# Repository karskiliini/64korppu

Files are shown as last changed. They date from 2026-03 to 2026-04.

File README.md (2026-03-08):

# 64korppu

Standardi PC:n 1.44MB 3.5" HD-korppuasema Commodore 64 -tietokoneeseen. FAT12-levyformaatti mahdollistaa tiedostojen siirron C64:n ja PC:n välillä.

## Vaihtoehdot

| # | Ratkaisu | Liitäntä | Hinta | RAM | Tasonmuuntimet | Suositus |
|---|---|---|---|---|---|---|
| **[A](docs/A-IEC-Pico/)** | **IEC + Raspberry Pi Pico** | IEC-sarjaväylä | ~12€ | 264 KB | 4x BSS138 | **Suositeltu** |
| [B](docs/B-Expansion-FDC/) | Expansion port + FDC-piiri | Expansion port | ~20-30€ | - | Ei | Nopein |
| [C](docs/C-Userport-Pico/) | User port + Raspberry Pi Pico | User port | ~12€ | 264 KB | 1x 74LVC245 + 2x BSS138 | Kompromissi |
| [D](docs/D-IEC-Nano/) | IEC + Arduino Nano | IEC-sarjaväylä | ~8€ | 2 KB | **Ei yhtään** | Halvin |
| [E](docs/E-IEC-Nano-SRAM/) | IEC + Arduino Nano + SPI SRAM | IEC-sarjaväylä | ~10-13€ | 2+128 KB | **Ei yhtään** | Nano tehostettuna |

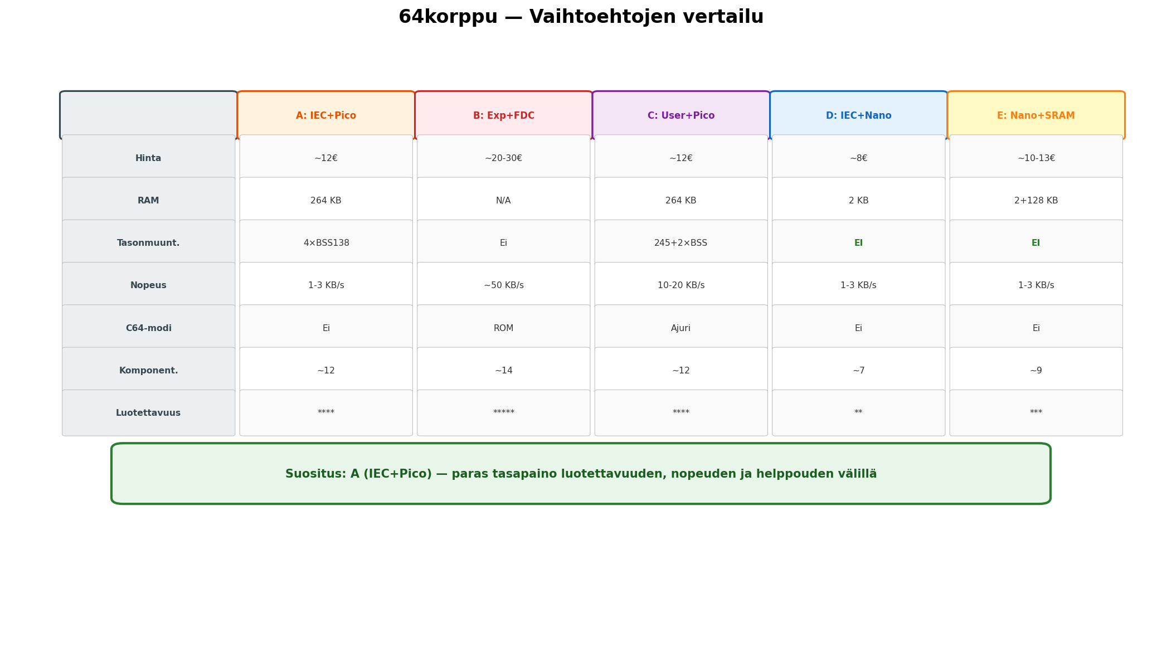
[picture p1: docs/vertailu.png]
Vaihtoehtojen vertailu


## Arkkitehtuuri

```
C64 ──[IEC / User port / Expansion port]──> Ohjain ──[34-pin]──> PC 3.5" HD floppy
                                                         │
                                                    FAT12-levy
                                                    (1.44 MB)
                                                         │
                                                    PC lukee/kirjoittaa
                                                    samaa levyä
```

## Miksi?

- **Tiedostonsiirto** C64:n ja modernin PC:n välillä ilman erikoislaitteita
- **FAT12** on universaali — levy toimii molemmissa koneissa
- **.PRG-tiedostot** tallennetaan suoraan levylle (2 tavun load address + data)
- **.D64 disk imaget** tuettuja — kopioi .D64-tiedosto levylle, mounttaa C64:llä, lataa ohjelmia suoraan
- C64:llä: `LOAD "PELI.PRG",8` / `SAVE "OMA.PRG",8` / `LOAD "$",8`

## Projektin rakenne

```
64korppu/
├── docs/
│   ├── A-IEC-Pico/           Vaihtoehto A: IEC + Pico (suositeltu)
│   │   ├── README.md         Yhteenveto
│   │   ├── kuvaus.md         Arkkitehtuuri ja komponentit
│   │   ├── piirikaavio.md    Yksityiskohtainen piirikaavio
│   │   └── d64-tuki.md       D64 disk image -tuki
│   ├── B-Expansion-FDC/      Vaihtoehto B: Expansion port + FDC
│   │   ├── README.md
│   │   ├── kuvaus.md
│   │   └── piirikaavio.md
│   ├── C-Userport-Pico/      Vaihtoehto C: User port + Pico
│   │   ├── README.md
│   │   ├── kuvaus.md
│   │   └── piirikaavio.md
│   ├── D-IEC-Nano/           Vaihtoehto D: IEC + Arduino Nano
│   │   ├── README.md
│   │   ├── kuvaus.md
│   │   └── piirikaavio.md
│   └── E-IEC-Nano-SRAM/      Vaihtoehto E: IEC + Nano + 128KB SRAM
│       ├── README.md
│       ├── kuvaus.md
│       └── piirikaavio.md
├── firmware/                  Pico-firmware (vaihtoehto A)
│   ├── CMakeLists.txt
│   ├── include/               Header-tiedostot
│   │   ├── cbm_dos.h          CBM-DOS-emulaatio
│   │   ├── d64.h              D64 disk image -tuki
│   │   ├── fat12.h            FAT12-tiedostojärjestelmä
│   │   ├── floppy_ctrl.h      Floppy-aseman ohjaus
│   │   ├── iec_protocol.h     IEC-väyläprotokolla
│   │   └── mfm_codec.h        MFM-koodaus/dekoodaus
│   ├── src/                   Lähdekoodit
│   │   ├── main.c             Pääohjelma, dual-core, inter-core viestit
│   │   ├── cbm_dos.c          LOAD/SAVE/$, CD:/S:/R:/N:/I:, D64-moodi
│   │   ├── d64.c              D64-parsinta, mount/unmount, BAM, T/S-ketjut
│   │   ├── fat12.c            FAT12 mount/read/write/delete/format
│   │   ├── floppy_ctrl.c      GPIO-ohjaus: moottori, seek, side select
│   │   ├── iec_protocol.c     ATN/CLK/DATA bit-bang, byte send/receive
│   │   └── mfm_codec.c        MFM-dekoodaus, CRC-CCITT, sektorihaku
│   └── pio/                   PIO-ohjelmat (RP2040)
│       ├── iec_bus.pio        IEC-vastaanotto
│       ├── mfm_read.pio       MFM flux-transitioiden mittaus
│       └── mfm_write.pio      MFM flux-transitioiden generointi
└── test/                      Testit (ajetaan host-koneella, ei tarvitse Picoa)
    ├── Makefile               Kääntää testit ja IEC bridge
    ├── test_d64.c             D64-moduulin yksikkötestit (27 testiä)
    ├── mock_fat12.c/h         FAT12-mock: tiedostot muistissa
    ├── gen_test_d64.py        Generoi testi-.D64-imagen
    └── vice/                  IEC bridge integraatiotestaukseen
        ├── iec_bridge.c       TCP-palvelin: oikea CBM-DOS + D64 host-koneella
        ├── mock_iec.c/h       IEC-protokollan stubit
        ├── vice_test.py       Python-testiskripti (simuloi C64 IEC-komentoja)
        └── README.md          Bridge-arkkitehtuuri ja ohje
```

## Testaus

D64- ja CBM-DOS-koodi on testattavissa host-koneella (Linux/macOS) ilman Pico-laitteistoa:

```bash
cd test
make test          # 27 yksikkötestiä D64-moduulille
make               # kääntää myös IEC bridge
./vice/iec_bridge  # käynnistä TCP-palvelin
python3 vice/vice_test.py  # aja integraatiotestit toisessa terminaalissa
```

## Tila

Projekti on suunnitteluvaiheessa. Firmware-koodi on kirjoitettu vaihtoehto A:lle (Pico), mutta ei vielä testattu oikealla laitteistolla. D64 disk image -tuki toteutettu ja testattu host-tasolla.

## Lisenssi

Avoin lähdekoodi. Lisenssi lisätään myöhemmin.

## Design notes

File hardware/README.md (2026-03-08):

# Hardware — KiCad-piirilevyt

## Hakemistorakenne

```
hardware/
└── E-IEC-Nano-SRAM/
    ├── 64korppu-E.kicad_pro        # KiCad-projekti
    ├── 64korppu-E.kicad_sch        # Piirikaavio
    ├── 64korppu-E.kicad_pcb        # Piirilevylayout
    ├── fp-lib-table                # Footprint-kirjaston asetukset
    └── 64korppu-E.pretty/          # Projektikohtaiset footprintit
        └── DIN-6_IEC_Vertical.kicad_mod
```

## Vaatimukset

- **KiCad 8** (https://www.kicad.org/)

## Projektin avaaminen

1. Avaa KiCad
2. **File → Open Project**
3. Valitse `hardware/E-IEC-Nano-SRAM/64korppu-E.kicad_pro`

Piirikaavio avautuu Schematic Editorilla, piirilevylayout PCB Editorilla.

## Automaattireititys Freeroutingilla

Freerouting reitittää piirilevyn vedot automaattisesti KiCadin tuottamasta netlististä.

1. **KiCad PCB Editor:** File → Export → Specctra DSN — tallenna `.dsn`-tiedosto
2. Lataa Freerouting: https://github.com/freerouting/freerouting
3. Käynnistä:
   ```bash
   java -jar freerouting.jar
   ```
4. Avaa `.dsn`-tiedosto ja klikkaa **Autoroute**
5. Kun reititys valmis: **File → Export Specctra Session** (`.ses`)
6. **KiCad PCB Editor:** File → Import → Specctra Session — valitse `.ses`-tiedosto

Tarkista tulos DRC:llä (Inspect → Design Rules Checker) ennen Gerber-vientiä.

## Gerber-vienti (JLCPCB / PCBWay)

### Gerber-tiedostot

1. **KiCad PCB Editor:** File → Fabrication Outputs → Gerbers
2. Varmista että seuraavat tasot ovat valittuna:
   - `F.Cu` — etupuolen kupari
   - `B.Cu` — takapuolen kupari
   - `F.SilkS` — etupuolen silkkipaino
   - `B.SilkS` — takapuolen silkkipaino
   - `F.Mask` — etupuolen juotosmaskimaski
   - `B.Mask` — takapuolen juotosmaskimaski
   - `Edge.Cuts` — levyn ääriviivat
3. Klikkaa **Plot**

### Poraustiedostot

1. File → Fabrication Outputs → Drill Files
2. Käytä oletusasetuksia (Excellon-formaatti)
3. Klikkaa **Generate Drill File**

### Tilaus

1. Pakkaa kaikki Gerber- ja poraustiedostot yhteen `.zip`-tiedostoon
2. Lataa osoitteeseen [JLCPCB](https://jlcpcb.com/) tai [PCBWay](https://pcbway.com/)
3. Tarkista esikatselu ennen tilausta

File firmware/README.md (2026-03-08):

# Firmware

Kullekin laitteistovaihtoehdolle on oma hakemistonsa.
Vaihtoehdot vastaavat `docs/`-kansion suunnitelmia.

```
firmware/
├── A-IEC-Pico/          Raspberry Pi Pico, IEC-väylä (suositeltu)
│   ├── src/             C-lähdekoodi
│   ├── include/         Otsikkotiedostot
│   ├── pio/             PIO-ohjelmat (iec_bus, mfm_read, mfm_write)
│   ├── CMakeLists.txt   Pico SDK build
│   └── pico_sdk_import.cmake
│
├── B-Expansion-FDC/     Expansion port + FDC-piiri (ei vielä toteutettu)
├── C-Userport-Pico/     User port + Pico (ei vielä toteutettu)
├── D-IEC-Nano/          Arduino Nano, IEC-väylä (ei vielä toteutettu)
└── E-IEC-Nano-SRAM/     Arduino Nano + SPI SRAM (ei vielä toteutettu)
```

## A-IEC-Pico

Ainoa toistaiseksi toteutettu vaihtoehto. Raspberry Pi Pico emuloi
CBM-levyasemaa IEC-sarjaväylän yli ja ohjaa PC 3.5" HD -korppuasemaa.

Tuetut levyformaatit:
- **HD 1.44 MB** — FAT12-tiedostojärjestelmä
- **DD 720 KB** — CBM 1581 -yhteensopiva CBMFS-tiedostojärjestelmä
- **D64-levykuvat** — 1541-yhteensopiva (luetaan FAT12-levyltä)

Kääntäminen:

```bash
cd firmware/A-IEC-Pico
mkdir build && cd build
cmake ..
make
```

## B–E: Muut vaihtoehdot

Suunnitteludokumentit löytyvät `docs/`-kansiosta. Firmwarea ei ole
vielä toteutettu näille vaihtoehdoille. Jokainen vaihtoehto tulee
noudattamaan samaa logiikkakerrosrakennetta (CBM-DOS, D64, FAT12/CBMFS),
mutta laitteistotason koodi (IEC-protokolla, floppy-ohjaus, MFM) on
alustaspesifistä.

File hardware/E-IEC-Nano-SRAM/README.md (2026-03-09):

# 64korppu-E — Hardware

> Arduino Nano + 23LC256 SPI SRAM + 74HC595

## 4-layer (70x60mm)

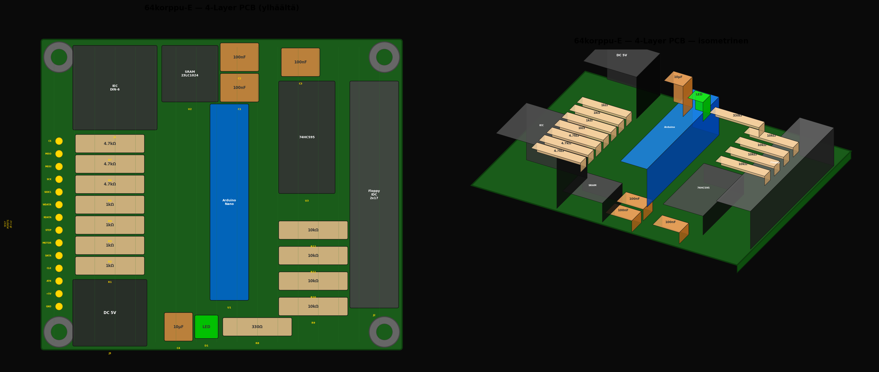
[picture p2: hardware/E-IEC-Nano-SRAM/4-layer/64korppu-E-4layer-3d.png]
64korppu-E 4-layer PCB


## 2-layer (140x120mm)

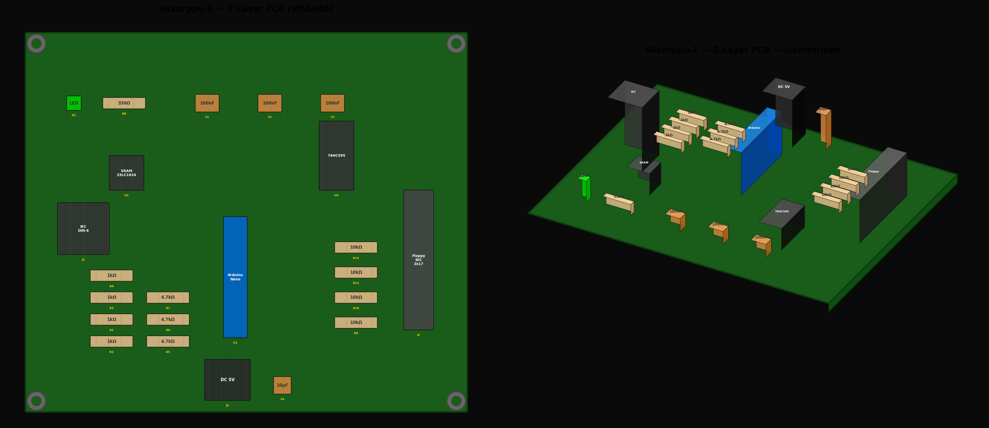
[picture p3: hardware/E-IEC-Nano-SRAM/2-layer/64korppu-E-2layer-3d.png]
64korppu-E 2-layer PCB


## Variantit

| Kansio | Kerrokset | Mitat (mm) | Pinta-ala |
|---|---|---|---|
| [2-layer/](2-layer/) | F.Cu + B.Cu | 140.0 × 120.0 | 16 800 mm² |
| [4-layer/](4-layer/) | F.Cu / GND / +5V / B.Cu | 70.0 × 60.0 | 4 200 mm² |

## Dokumentaatio

Katso [docs/E-IEC-Nano-SRAM/](../../docs/E-IEC-Nano-SRAM/) — piirikaavio, diagnostiikkapadit, komponenttikuvaus.

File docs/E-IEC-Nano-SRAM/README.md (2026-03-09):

# E: IEC-väylä + Arduino Nano + SPI SRAM (Nano tehostettuna)

> C64:n IEC-sarjaväylä → Arduino Nano + 23LC256 SRAM → PC 3.5" HD floppy

## Yhteenveto

Vaihtoehto D:n parannettu versio. Microchipin 23LC256 SPI SRAM (32 KB) ratkaisee Nanon 2 KB muistirajoituksen. 74HC595 shift register ohjaa floppy-signaaleja SPI-väylän kautta, vapauttaen GPIO-pinnejä. Edelleen täysin 5V-natiivi — ei tasonmuuntimia.

## Tiedostot

| Tiedosto | Sisältö |
|---|---|
| [kuvaus.md](kuvaus.md) | SRAM-vaihtoehdot, muistikartta, SPI-väylän jakaminen, 74HC595-ohjaus, firmware-rakenne |
| [piirikaavio.md](piirikaavio.md) | 23LC256 + 74HC595 SPI-kytkentä, kokonaispiirikaavio, bypass-kondensaattorit |
| [diagnostiikkapadit.md](diagnostiikkapadit.md) | 14 testipistettä: signaalit, odotetut tasot, mittausohje, vianetsintä |

## PCB

| Variantti | Mitat | Kerrokset |
|---|---|---|
| 2-layer | 140.0 × 120.0 mm | F.Cu + B.Cu |
| 4-layer | 70.0 × 60.0 mm | F.Cu / GND / +5V / B.Cu |

64korppu-E 4-layer PCB

## Piirikaavio

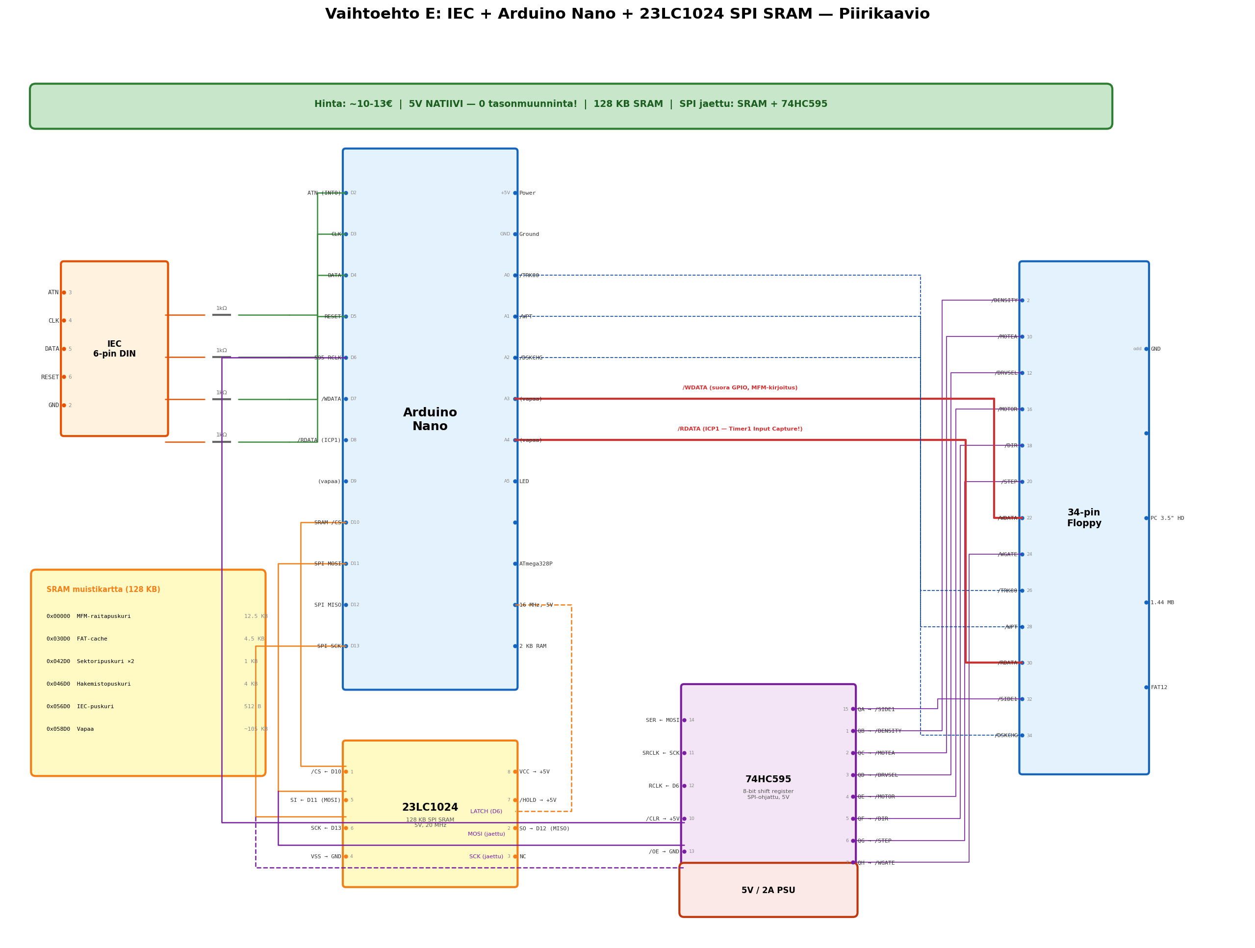
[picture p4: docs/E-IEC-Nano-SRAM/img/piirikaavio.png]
Vaihtoehto E: Nano + SRAM


## Avainominaisuudet

- **32 KB SRAM** — koko raita, FAT-taulu ja puskurit mahtuvat
- **Ei tasonmuuntimia** — 5V natiivi (Nano + 23LC256 + 74HC595 + floppy)
- **SPI-väylän jakaminen** — SRAM ja shift register samalla väylällä
- **Edullinen** (~10-13€)

## Hinta: ~10-13€

## Haaste

SPI SRAM lisää hieman latenssia. Single-core (ei rinnakkaista IEC + floppy). 32 KB Flash voi olla tiukka.

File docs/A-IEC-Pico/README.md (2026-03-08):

# A: IEC-väylä + Raspberry Pi Pico (Suositeltu)

> C64:n IEC-sarjaväylä → Raspberry Pi Pico → PC 3.5" HD floppy

## Yhteenveto

Pico emuloi CBM-levyasemaa (device #8) IEC-väylällä ja ohjaa PC-korppuasemaa 34-pin Shugart-liitännällä. FAT12-tiedostojärjestelmä mahdollistaa levyjen lukemisen sekä C64:llä että PC:llä.

## Tiedostot

| Tiedosto | Sisältö |
|---|---|
| [kuvaus.md](kuvaus.md) | Arkkitehtuuri, komponenttilista, GPIO-kartta, firmware-rakenne, plussat/miinukset |
| [piirikaavio.md](piirikaavio.md) | Yksityiskohtainen piirikaavio: BSS138 level shifter, floppy-kytkentä, Pico pinout |
| [d64-tuki.md](d64-tuki.md) | D64 disk image -tuki: formaatti, käyttöohjeet, rajoitukset |

## Piirikaavio

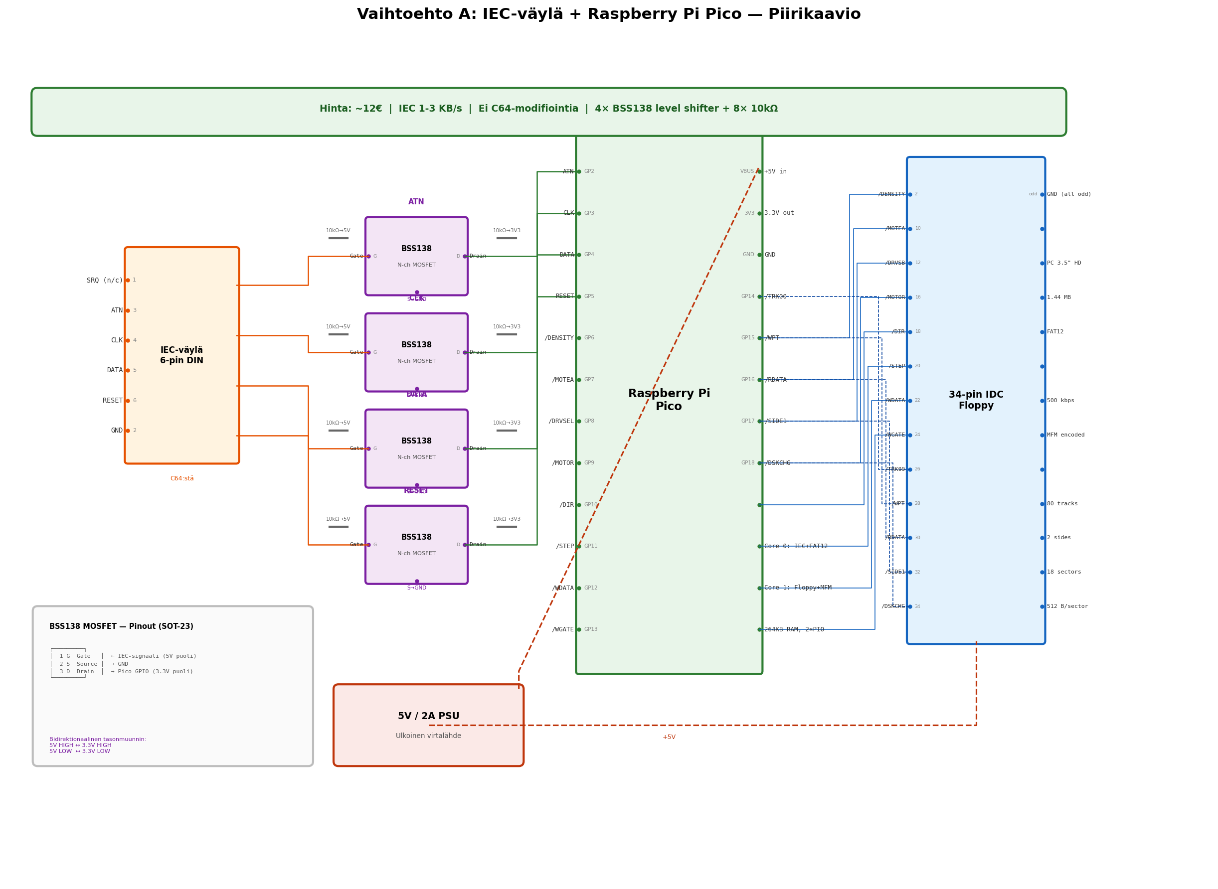
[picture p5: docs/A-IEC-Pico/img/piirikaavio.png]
Vaihtoehto A: IEC + Pico


## Avainominaisuudet

- **Ei vaadi C64:n modifiointia** — toimii suoraan LOAD/SAVE-komennoilla
- **Dual-core**: IEC-protokolla ja floppy-ohjaus rinnakkain
- **PIO**: tarkka ajoitus MFM-koodaukselle ja IEC-signaloinnille
- **264 KB RAM**: koko raita ja FAT-taulu mahtuvat muistiin
- **D64 disk image -tuki**: kopioi .D64-tiedosto levylle, mounttaa C64:llä `CD:`-komennolla

## Hinta: ~12€

## Haaste

Tarvitsee 4x BSS138 MOSFET level shifter (3.3V ↔ 5V) IEC-väylälle.

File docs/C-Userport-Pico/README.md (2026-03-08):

# C: User Port + Raspberry Pi Pico (Hyvä kompromissi)

> C64 user port → Raspberry Pi Pico → PC 3.5" HD floppy

## Yhteenveto

Pico kommunikoi C64:n kanssa user portin 8-bittisen rinnakkaisväylän kautta. Nopeampi kuin IEC (~10-20 KB/s), mutta vaatii ladattavan ajurin C64-puolelle. Expansion port jää vapaaksi.

## Tiedostot

| Tiedosto | Sisältö |
|---|---|
| [kuvaus.md](kuvaus.md) | Arkkitehtuuri, user port protokolla, CIA2-kytkennät, C64-ajurikoodi |
| [piirikaavio.md](piirikaavio.md) | 74LVC245 dataväylä, BSS138 handshake, floppy-kytkentä, DIR-ohjaus |

## Piirikaavio

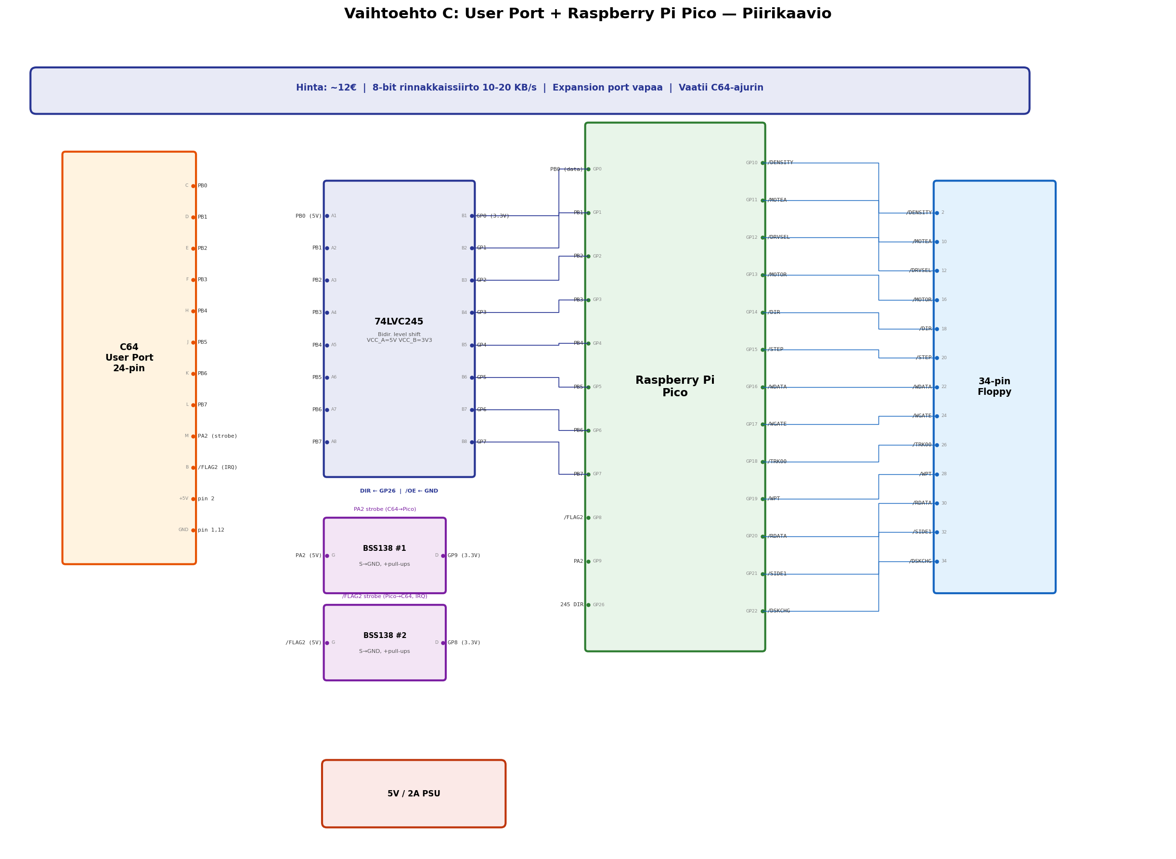
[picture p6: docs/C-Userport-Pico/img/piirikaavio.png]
Vaihtoehto C: User port + Pico


## Avainominaisuudet

- **Nopeampi kuin IEC** — 8-bittinen rinnakkaissiirto (~10-20 KB/s)
- **Expansion port vapaa** — cartridget ja REU toimivat
- **Dual-core**: sama Pico-etu kuin vaihtoehdossa A

## Hinta: ~12€

## Haaste

Vaatii C64-ajurin lataamisen ennen käyttöä. Ei suoraan yhteensopiva kaiken ohjelmiston kanssa. User port varattu.

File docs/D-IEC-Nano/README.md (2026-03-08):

# D: IEC-väylä + Arduino Nano (Edullinen klassikko)

> C64:n IEC-sarjaväylä → Arduino Nano → PC 3.5" HD floppy

## Yhteenveto

Arduino Nano emuloi CBM-levyasemaa IEC-väylällä. Nanon 5V-logiikka on suoraan yhteensopiva sekä IEC-väylän että floppy-aseman kanssa — tasonmuuntimia ei tarvita lainkaan!

## Tiedostot

| Tiedosto | Sisältö |
|---|---|
| [kuvaus.md](kuvaus.md) | Arkkitehtuuri, GPIO-kartta, Timer1 ICP MFM-strategia, RAM-rajoitukset |
| [piirikaavio.md](piirikaavio.md) | Suora 5V-kytkentä, ICP1 MFM-luku, komponenttilista |

## Piirikaavio

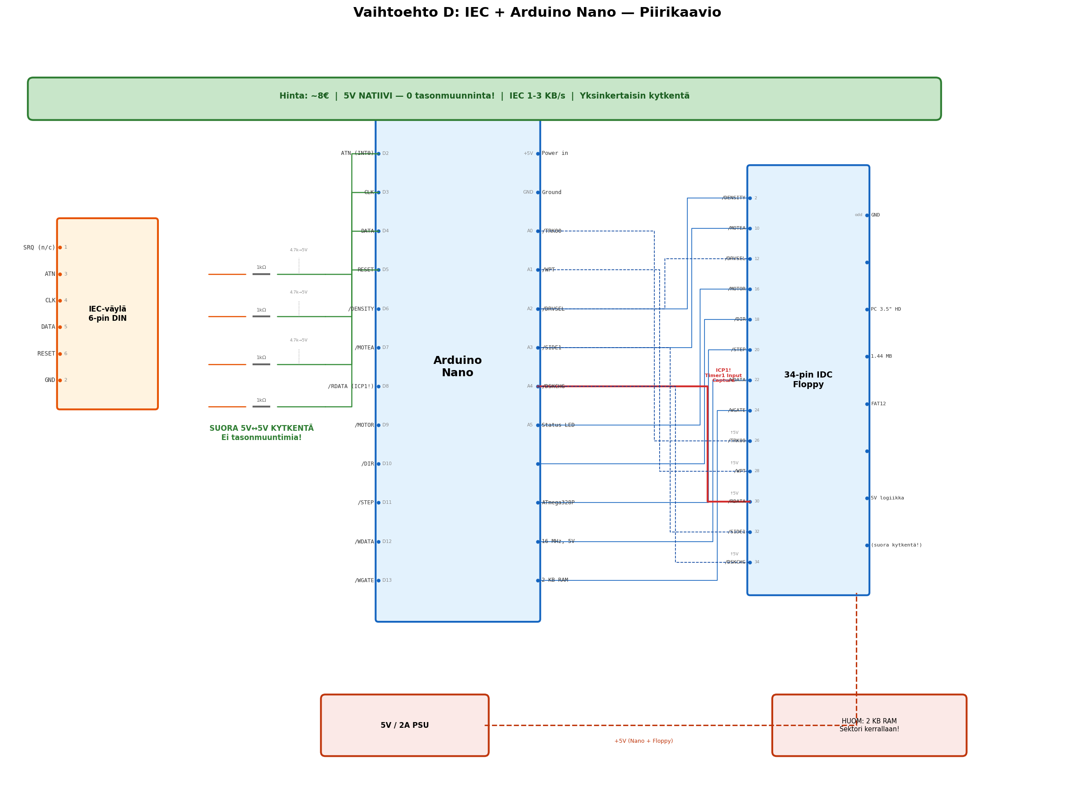
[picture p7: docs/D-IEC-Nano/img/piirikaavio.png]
Vaihtoehto D: IEC + Nano


## Avainominaisuudet

- **Ei tasonmuuntimia!** — 5V natiivi, yksinkertaisin kytkentä
- **Edullisin vaihtoehto** (~8€)
- **Tuttu Arduino-ympäristö**

## Hinta: ~8-10€

## Haaste

Vain 2 KB RAM — MFM-raita (12.5 KB) ja FAT-taulu (4.5 KB) eivät mahdu muistiin. Vaatii sektori-kerrallaan reaaliaikaista dekoodausta. Katso vaihtoehto E ratkaisulle.

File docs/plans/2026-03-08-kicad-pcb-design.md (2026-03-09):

# KiCad PCB Design — Vaihtoehto E (IEC + Nano + SPI SRAM)

## Päätökset

- **Levy:** ~85 × 55 mm, 2-kerroksinen (top + bottom)
- **Nano:** Pin header -sokkelit, irrotettava moduuli
- **Liittimet:** IEC DIN-6 vasemmalla, 34-pin IDC oikealla, DC jack ylhäällä
- **Automaattireititys:** Freerouting (.dsn export)

## Komponentit

| Ref | Komponentti | Paketti | Kpl |
|-----|---|---|-----|
| U1 | Arduino Nano | 2×15 pin header | 1 |
| U2 | 23LC256 | DIP-8 | 1 |
| U3 | 74HC595 | DIP-16 | 1 |
| J1 | 6-pin DIN | DIN-6 (IEC) | 1 |
| J2 | 34-pin IDC | 2×17 shrouded header | 1 |
| J3 | DC jack | 5.5/2.1mm barrel | 1 |
| R1-R4 | 1 kOhm | axial | 4 |
| R5-R7 | 4.7 kOhm | axial | 3 |
| R8 | 330 Ohm | axial | 1 |
| R9-R12 | 10 kOhm | axial | 4 |
| C1-C3 | 100 nF | ceramic disc | 3 |
| C4 | 10 uF | electrolytic | 1 |
| D1 | LED green | 3mm | 1 |

## Netlist

```
IEC-väylä:
  J1.ATN  → R1 → U1.D2
  J1.CLK  → R2 → U1.D3
  J1.DATA → R3 → U1.D4
  J1.RST  → R4 → U1.D5
  J1.GND  → GND

IEC pull-up:
  R5: +5V → J1.ATN (after R1)
  R6: +5V → J1.CLK (after R2)
  R7: +5V → J1.DATA (after R3)

SPI SRAM (23LC256):
  U1.D10  → U2./CS
  U1.D11  → U2.SI
  U1.D12  ← U2.SO
  U1.D13  → U2.SCK
  U2./HOLD → +5V
  U2.VCC  → +5V
  U2.VSS  → GND

74HC595:
  U1.D11  → U3.SER
  U1.D13  → U3.SRCLK
  U1.D6   → U3.RCLK
  U3./CLR → +5V
  U3./OE  → GND
  U3.VCC  → +5V
  U3.GND  → GND

Floppy (via 74HC595):
  U3.QA → J2./SIDE1
  U3.QB → J2./DENSITY
  U3.QC → J2./MOTEA
  U3.QD → J2./DRVSEL
  U3.QE → J2./MOTOR
  U3.QF → J2./DIR
  U3.QG → J2./STEP
  U3.QH → J2./WGATE

Floppy (suora GPIO):
  U1.D7  → J2./WDATA
  U1.D8  ← J2./RDATA
  U1.A0  ← J2./TRK00   (R9 pull-up 10k)
  U1.A1  ← J2./WPT     (R10 pull-up 10k)
  U1.A2  ← J2./DSKCHG  (R11 pull-up 10k)
  U1.D8 pull-up: R12 10k → +5V

LED:
  U1.A5 → R8(330) → D1 → GND

Bypass:
  C1: U1.+5V ↔ GND
  C2: U2.VCC ↔ GND
  C3: U3.VCC ↔ GND
  C4: J3.+5V ↔ GND (bulk)

Virta:
  J3.+5V → +5V (kaikille)
  J3.GND → GND (kaikille)
```

## Sijoittelu

```
              J3 (DC jack)
        ┌────────┬─────────────────┐
        │  C4                      │
        │                          │
  J1 ───┤  R1-R4    ┌──────────┐   ├─── J2
 (DIN-6)│  R5-R7    │ U1 Nano  │   │  (34-pin IDC)
        │           │ headers  │   │
        │  ┌────┐   └──────────┘   │
        │  │ U2 │                  │
        │  │SRAM│   ┌──────────┐   │
        │  └────┘   │U3 74HC595│   │
        │           └──────────┘   │
        │  D1 R8   C1 C2 C3       │
        │          R9-R12          │
        └──────────────────────────┘
```

## Reititysprioriteetti

1. SPI-väylä (MOSI/MISO/SCK) — lyhyet vedot
2. MFM (WDATA/RDATA) — suorat lyhyet vedot
3. IEC — DIN-6 → vastukset → Nano
4. GND-täyttö bottom-kerroksella

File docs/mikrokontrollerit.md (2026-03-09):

# Mikrokontrollerit ja kehitysalustat — vertailu

Tämä dokumentti listaa kaikki Arduino-laudat ja vastaavat kehitysalustat,
jotka voisivat soveltua 64korppu-projektiin.

## Projektin vaatimukset

```
IEC-väylä:       4 GPIO  (ATN interrupt, CLK, DATA, RESET)
Floppy output:   9 GPIO  (DENSITY, MOTEA, DRVSEL, MOTOR, DIR, STEP, WDATA, WGATE, SIDE1)
Floppy input:    4 GPIO  (TRK00, WPT, RDATA, DSKCHG)
─────────────────────────
Yhteensä:       17 GPIO  (minimi ilman SRAM:ia)
+ SPI SRAM:     +4 GPIO  (MOSI, MISO, SCK, CS)  → 21 GPIO

Lisävaatimukset:
- Timer Input Capture tai vastaava MFM-dekoodaukseen (500 kbps, 2 µs/bitti)
- Ulkoinen keskeytys ATN-signaalille
- MFM-kirjoitus: tarkka ajoitus (~2 µs resoluutio)
- 5V-logiikka suositeltava (IEC + floppy ovat 5V) — 3.3V vaatii tasonmuuntimia
```

---

## Arduino-laudat

### 5V-laudat (ei tarvitse tasonmuuntimia)

| Lauta | Prosessori | MHz | RAM | Flash | GPIO | Hinta | Soveltuvuus |
|---|---|---|---|---|---|---|---|
| **Arduino Uno** | ATmega328P | 16 | 2 KB | 32 KB | 20 | ~5€ (klooni) | Toimii, RAM tiukka |
| **Arduino Nano** | ATmega328P | 16 | 2 KB | 32 KB | 22 | ~3-5€ (klooni) | Toimii, kompakti |
| **Arduino Pro Mini 5V** | ATmega328P | 16 | 2 KB | 32 KB | 20 | ~2-3€ (klooni) | Pienin, ei USB:ta |
| **Arduino Leonardo** | ATmega32U4 | 16 | 2.5 KB | 32 KB | 20 | ~5-8€ (klooni) | +500B RAM, natiivi USB |
| **Arduino Micro** | ATmega32U4 | 16 | 2.5 KB | 32 KB | 20 | ~5-8€ (klooni) | Sama kuin Leonardo, pienempi |
| **Arduino Mega 2560** | ATmega2560 | 16 | **8 KB** | 256 KB | **54** | ~8-12€ (klooni) | Paljon RAM:ia ja GPIO:ta |
| **Arduino Nano Every** | ATmega4809 | 20 | **6 KB** | 48 KB | 20 | ~8-10€ | Parempi Nano, CCL-logiikka |

### 3.3V-laudat (tarvitsee tasonmuuntimet IEC:lle ja flopylle)

| Lauta | Prosessori | MHz | RAM | Flash | GPIO | Hinta | Soveltuvuus |
|---|---|---|---|---|---|---|---|
| **Arduino Due** | SAM3X8E (ARM) | 84 | **96 KB** | 512 KB | 54 | ~12-15€ | Tehokas, paljon muistia |
| **Arduino Zero** | SAMD21 (ARM) | 48 | **32 KB** | 256 KB | 20 | ~15-20€ | ARM Cortex-M0+ |
| **Arduino Nano 33 IoT** | SAMD21 + WiFi | 48 | **32 KB** | 256 KB | 14 | ~18€ | WiFi turha, vähän GPIO:ta |
| **Arduino Nano 33 BLE** | nRF52840 | 64 | **256 KB** | 1 MB | 14 | ~20€ | BLE turha, vähän GPIO:ta |
| **Arduino Nano RP2040** | RP2040 | 133 | **264 KB** | 16 MB | 20 | ~20€ | Pico Nano-muodossa |
| **Arduino MKR Zero** | SAMD21 | 48 | **32 KB** | 256 KB | 22 | ~25€ | SD-korttipaikka mukana |

---

## Arduino-yhteensopivat alustat

### 5V-alustat

| Lauta | Prosessori | MHz | RAM | Flash | GPIO | Hinta | Soveltuvuus |
|---|---|---|---|---|---|---|---|
| **STM32 Blue Pill** | STM32F103C8 | 72 | **20 KB** | 64 KB | 33 | ~2-3€ | 5V-tolerantti input! |
| **Teensy 2.0** | ATmega32U4 | 16 | 2.5 KB | 32 KB | 25 | ~20€ | Hyvä USB, kuten Leonardo |

### 3.3V-alustat

| Lauta | Prosessori | MHz | RAM | Flash | GPIO | Hinta | Soveltuvuus |
|---|---|---|---|---|---|---|---|
| **Raspberry Pi Pico** | RP2040 (2 ydintä) | 133 | **264 KB** | 2 MB | 26 | ~4-5€ | **Projektin päävalinta** |
| **Raspberry Pi Pico W** | RP2040 + WiFi | 133 | **264 KB** | 2 MB | 26 | ~7€ | WiFi turha |
| **Raspberry Pi Pico 2** | RP2350 (2 ydintä) | 150 | **520 KB** | 4 MB | 26 | ~5-6€ | Picon seuraaja, PIO v2 |
| **STM32 Black Pill** | STM32F411CE | 100 | **128 KB** | 512 KB | 32 | ~3-5€ | Tehokas, edullinen |
| **Teensy 4.0** | i.MX RT1062 | 600 | **1 MB** | 2 MB | 24 | ~25€ | Ylilyönti, kallis |
| **Teensy 4.1** | i.MX RT1062 | 600 | **1 MB** | 8 MB | 42 | ~35€ | Ylilyönti, kallis |
| **ESP32-DevKit** | ESP32 (2 ydintä) | 240 | **520 KB** | 4 MB | 25 | ~4-5€ | WiFi/BT turha, ajoitus? |
| **ESP32-S3** | ESP32-S3 (2 ydintä) | 240 | **512 KB** | 8 MB | 36 | ~5-7€ | USB OTG, paljon GPIO |
| **Seeed XIAO SAMD21** | SAMD21 | 48 | **32 KB** | 256 KB | 11 | ~5€ | Liian vähän GPIO:ta |
| **Seeed XIAO RP2040** | RP2040 | 133 | **264 KB** | 2 MB | 11 | ~5€ | Liian vähän GPIO:ta |
| **Adafruit Feather M4** | SAMD51 | 120 | **192 KB** | 512 KB | 21 | ~25€ | Kallis, hyvä suorituskyky |
| **WeAct STM32F411** | STM32F411CE | 100 | **128 KB** | 512 KB | 32 | ~3€ | Black Pill klooni |

---

## GPIO-riittävyys

Minimi 17 GPIO (ilman SRAM:ia), 21 GPIO SRAM:n kanssa.

```
                               GPIO    Riittääkö?
                               ────    ──────────
5V-laudat:
  Arduino Uno / Nano / Pro Mini  20-22   Kyllä (17/22), SRAM:lla tiukka (21/22)
  Arduino Leonardo / Micro       20      Kyllä (17/20), SRAM:lla tiukka (21 > 20!)
  Arduino Mega 2560              54      Reilusti
  Arduino Nano Every             20      Kyllä, SRAM:lla tiukka
  STM32 Blue Pill                33      Reilusti
  Teensy 2.0                     25      Reilusti

3.3V-laudat:
  Raspberry Pi Pico / Pico 2     26      Reilusti
  Arduino Due                    54      Reilusti
  Arduino Nano RP2040            20      Kyllä, SRAM:lla tiukka
  STM32 Black Pill               32      Reilusti
  ESP32-DevKit                   25      Reilusti (mutta osa pinneistä rajoitettuja)
  Teensy 4.0                     24      Kyllä
  Teensy 4.1                     42      Reilusti
  Arduino Nano 33 IoT/BLE        14      EI RIITÄ
  Seeed XIAO (kaikki)            11      EI RIITÄ
```

### Leonardo/Micro + SRAM -ongelma

ATmega32U4-lautojen 20 GPIO:sta D0/D1 ovat vapaita (natiivi USB ei käytä niitä),
joten 21 GPIO on juuri mahdollista kun kaikki pinnit käytetään. Ei yhtään
vapaata debug-pinnistä.

---

## RAM-riittävyys (ilman ulkoista SRAM:ia)

```
MFM-raita:    ~12 500 B (yksi raita 500 kbps × 200 ms)
FAT-taulu:    ~4 500 B (1.44 MB levyn FAT12)
Sektori:         512 B
IEC-puskuri:     256 B
Pino + muut:     512 B
─────────────────────────
Yhteensä:    ~18 280 B  (jos kaikki mahtuu kerralla)
Minimi:       ~1 536 B  (sektori + IEC + pino, ei raitapuskuria)

                     RAM      Raitapuskuri?   FAT kokonaan?
                     ───      ─────────────   ─────────────
ATmega328P           2 KB     Ei              Ei
ATmega32U4           2.5 KB   Ei              Ei
ATmega4809           6 KB     Ei              Kyllä (4.5 KB)
ATmega2560           8 KB     Ei              Kyllä
STM32F103 (Blue)     20 KB    Kyllä           Kyllä
SAMD21               32 KB    Kyllä           Kyllä
RP2040 (Pico)        264 KB   Kyllä           Kyllä
STM32F411 (Black)    128 KB   Kyllä           Kyllä
ESP32                520 KB   Kyllä           Kyllä
SAM3X8E (Due)        96 KB    Kyllä           Kyllä
i.MX RT1062 (Teensy) 1 MB     Kyllä           Kyllä
```

---

## MFM-ajoituksen soveltuvuus

MFM-dekoodaus vaatii 2 µs tarkkuutta (500 kbps HD floppy).
CPU-syklejä per MFM-bitti = kellotaajuus × 2 µs:

```
                     MHz    Syklejä/bitti   Riittääkö?
                     ───    ─────────────   ──────────
ATmega328P           16          32         Tiukka mutta toimii (Timer1 ICP)
ATmega32U4           16          32         Tiukka mutta toimii (Timer1 ICP)
ATmega4809           20          40         Hieman parempi
ATmega2560           16          32         Tiukka mutta toimii
STM32F103            72         144         Hyvä
SAMD21               48          96         Hyvä
RP2040              133         266         Erinomainen (+ PIO!)
RP2350              150         300         Erinomainen (+ PIO v2!)
STM32F411           100         200         Hyvä
ESP32               240         480         Erinomainen (mutta RTOS-jitter!)
SAM3X8E              84         168         Hyvä
i.MX RT1062         600        1200         Ylivoimainen
```

**ESP32-varoitus:** ESP32 pyörittää FreeRTOS-käyttöjärjestelmää, joka aiheuttaa
satunnaista viivettä (jitter) keskeytyksiin. Tämä voi häiritä MFM-dekoodausta,
vaikka CPU-teho sinänsä riittää. Ratkaisu: käytä toista ydintä ilman RTOS:ia
tai RMT-periferiaa (Remote Control Transceiver) pulssinmittaukseen.

---

## Tasonmuunnin-tarve

```
5V-natiivi (ei tasonmuuntimia):
  ✓ Kaikki ATmega-pohjaiset Arduinot (Uno, Nano, Mega, Leonardo...)
  ✓ Teensy 2.0
  △ STM32 Blue Pill (5V-tolerantti INPUT, mutta output on 3.3V)

3.3V (tarvitsee tasonmuuntimia IEC + floppy):
  ✗ Raspberry Pi Pico / Pico 2
  ✗ Arduino Due, Zero, MKR, Nano 33 -sarja
  ✗ STM32 Black Pill
  ✗ ESP32
  ✗ Teensy 4.x
  ✗ Kaikki SAMD-pohjaiset

Tasonmuuntimen hinta: ~1-3€ (2× 74LVC245 tai 4× BSS138 MOSFET)
```

**STM32 Blue Pill -erikoistapaus:** STM32F103:n GPIO-pinnit ovat 5V-tolerantteja
*input*-tilassa, mutta output on 3.3V. IEC-väylä on open-collector (aktiivisena
vedetään alas), joten 3.3V:n LOW-taso riittää. Floppy-signaalit ovat samoin
aktiivi-LOW. Blue Pill saattaa toimia **ilman tasonmuuntimia** open-collector-
kytkennällä, mutta tämä vaatii testausta.

---

## Yhteenveto — parhaat vaihtoehdot

### Tier 1: Suositeltavat

| Lauta | Hinta | Miksi |
|---|---|---|
| **Raspberry Pi Pico** | ~4-5€ | Paras kokonaisuus: PIO, dual-core, 264 KB RAM |
| **Raspberry Pi Pico 2** | ~5-6€ | Picon seuraaja, PIO v2, enemmän RAM:ia |
| **Arduino Nano + 23LC256** | ~6-8€ | Edullisin 5V-ratkaisu, ei tasonmuuntimia |
| **Arduino Mega 2560** | ~8-12€ | 8 KB RAM + 54 GPIO, 5V, ei SRAM:ia välttämättä tarvita |

### Tier 2: Toimivia vaihtoehtoja

| Lauta | Hinta | Miksi |
|---|---|---|
| **STM32 Blue Pill** | ~2-3€ | Halvin, 20 KB RAM, 5V-tolerantti, mutta voi tarvita tasonmuuntimia |
| **STM32 Black Pill** | ~3-5€ | 128 KB RAM, 100 MHz, mutta 3.3V |
| **Arduino Nano Every** | ~8-10€ | 6 KB RAM, 20 MHz, 5V, CCL-logiikka |
| **Arduino Uno** | ~5€ | Sama kuin Nano, isompi |
| **Arduino Leonardo** | ~5-8€ | +500B RAM vs. Nano, natiivi USB |

### Tier 3: Toimivat mutta huono hinta/hyöty

| Lauta | Hinta | Miksi |
|---|---|---|
| **Arduino Due** | ~12-15€ | Tehokas mutta 3.3V, sama hinta kuin Pico |
| **ESP32** | ~4-5€ | Halpa ja tehokas, mutta RTOS-jitter ja WiFi/BT turhia |
| **Teensy 4.0/4.1** | ~25-35€ | Ylilyönti, kallis |
| **Adafruit Feather M4** | ~25€ | Kallis, 3.3V |

### Ei sovellu

| Lauta | Miksi ei |
|---|---|
| **Arduino Nano 33 IoT/BLE** | Vain 14 GPIO — ei riitä |
| **Seeed XIAO (kaikki)** | Vain 11 GPIO — ei riitä |
| **ESP8266** | Vain 11 GPIO, 3.3V, ei Input Capture |

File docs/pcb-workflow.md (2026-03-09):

# PCB-suunnittelun työnkulku (CLI)

Koko PCB-suunnitteluprosessi komentoriviltä ilman GUI:ta.

## Vaatimukset

- KiCad 9+ (`brew install --cask kicad`)
- Freerouting (`tools/freerouting.jar`) — https://github.com/freerouting/freerouting/releases
- OpenJDK (`brew install openjdk`)
- KiCadin Python: `/Applications/KiCad/KiCad.app/Contents/Frameworks/Python.framework/Versions/Current/bin/python3`

## Pikapolku: kaikki yhdellä komennolla

Kun `.kicad_pcb` on generoitu, **yksi komento** hoitaa kaiken:

```bash
./tools/pcb-pipeline.sh hardware/E-IEC-Nano-SRAM/64korppu-E
```

Pipeline tekee: validointi → DSN export → Freerouting → SES import → zone fill → DRC → Gerberit → GenCAD → zip.

## Vaiheet yksityiskohtaisesti

### 1. Claude Code generoi KiCad-projektitiedostot

Generoitavat tiedostot:
- `.kicad_pro` — projektiasetukset (JSON)
- `.kicad_sch` — piirikaavio (S-expression)
- `.kicad_pcb` — PCB-layout ilman reititystä (S-expression)
- Custom footprintit `.pretty/`-kansioon
- `fp-lib-table` — kirjastoviittaus

### 2. Validoi ja reititä

```bash
./tools/pcb-pipeline.sh hardware/<variant>/<name>
```

### 3. Kopioi tuotokset bin/-kansioon

```bash
cp hardware/<variant>/<name>-gerbers.zip bin/<variant>/
```

### 4. Tilaa

Lataa `<name>-gerbers.zip` palveluun:
- https://jlcpcb.com — halvin, 5 levyä ~$2 + toimitus
- https://www.pcbway.com — hyvä laatu

## Kriittiset säännöt PCB-generoinnissa

**Nämä tulee tarkistaa AINA ennen reititystä.** `pcb-validate.py` tarkistaa automaattisesti.

### 1. Ei `;;`-kommentteja
KiCad 9 hylkää S-expression-tiedostot joissa on `;;`-kommentteja.

### 2. Komponenttien minimietäisyydet
- **Eri komponenttien padien reunojen** välissä vähintään **0.3 mm**
- Erityisvaara: axial-vastukset (P10.16mm) ulottuvat 10.16mm origosta
- DIP-paketit: DIP-16 ulottuu 17.78mm pystysuunnassa, 7.62mm vaakasuunnassa
- 2x17 IDC header: ulottuu 40.64mm pystysuunnassa

### 3. Kaikki padit piirilevyn sisällä
- Jokaisen padin **absoluuttinen** sijainti (footprint origin + pad offset + rotaatio) tulee olla levyn rajojen sisällä
- Vähintään 0.5mm marginaali reunaan

### 4. Komponenttien sijoittelusäännöt
- **Älä aseta IC:itä suoraan toistensa päälle tai viereen** — jätä vähintään 5mm IC-pakettien väliin
- Arduino Nano (2x15, P2.54mm) ulottuu 35.56mm pystysuunnassa
- Sijoita 74HC595 ja 23LC256 **eri puolille** Nanoa, ei suoraan alle

### 5. Piirilevyn koko
- Prototyypille 100-120mm per sivu on hyvä
- Mounting holet M3 (3.2mm drill, 6mm pad) 3mm sisäänvedolla kulmista
- GND copper zone B.Cu-kerrokselle

## Työkalut

| Tiedosto | Kuvaus |
|---|---|
| `tools/pcb-pipeline.sh` | Koko pipeline yhdellä komennolla |
| `tools/pcb-validate.py` | Validoi PCB ennen reititystä |
| `tools/freerouting.jar` | Freerouting autorouter |

## Tuotetut tiedostot

```
hardware/<variant>/
├── <name>.kicad_pro          Projektiasetukset
├── <name>.kicad_sch          Piirikaavio
├── <name>.kicad_pcb          PCB-layout (+ tracet reitytyksen jälkeen)
├── <name>.dsn                Specctra DSN (väliaikainen)
├── <name>.ses                Specctra Session (väliaikainen)
├── <name>.cad                GenCAD (Eagle-yhteensopiva)
├── <name>-gerbers.zip        Valmis tilattavaksi
├── <name>.pretty/            Custom footprintit
├── fp-lib-table              Kirjastoviittaus
└── gerbers/                  Gerber + drill -tiedostot

bin/<variant>/
├── <name>-gerbers.zip        Gerberit (kopio)
└── <variant>.zip             Firmware-binääri
```

## DRC-tarkistus erikseen

```bash
kicad-cli pcb drc --severity-all hardware/<variant>/<name>.kicad_pcb
```

## GenCAD → Eagle

Eagle: **File → Import → GenCAD** ja valitse `.cad`-tiedosto.

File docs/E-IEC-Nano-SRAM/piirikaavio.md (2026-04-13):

# Vaihtoehto E: IEC + Arduino Nano + SPI SRAM — Piirikaavio

## Kokonaiskaavio

```
                                   Ulkoinen
                                   5V/2A PSU
                                   ┌───────┐
                                   │ +5V   │
                                   │ GND   │
                                   └───┬───┘
                                       │
              ┌────────────────────────┼────────────────────────┐
              │                        │                        │
              ▼                        ▼                        ▼
       ┌──────────────┐         ┌──────────────┐        ┌────────────┐
       │   Floppy     │         │  Arduino     │        │  C64       │
       │   asema      │         │  Nano        │        │            │
       │   PC 3.5" HD │         │  + SPI SRAM  │        │  IEC-port  │
       └──────┬───────┘         │  + 74HC595   │        └──────┬─────┘
              │                 └──────┬───────┘               │
              │  34-pin                │  SPI              6-pin DIN
              │  lattakaapeli          │  väylä             IEC-kaapeli
              └────── GPIO ────────────┴──── GPIO ─────────────┘

  Kaikki komponentit ovat 5V — ei yhtään tasonmuunninta!
```

## IEC-väylä (suora 5V kytkentä)

```
  Sama kuin vaihtoehto D — suora kytkentä, ei tasonmuuntimia.

           C64                                    Arduino Nano
     6-pin DIN-liitin                             (5V logiikka)
    ┌──────────────┐                             ┌──────────────┐
    │              │        100Ω suoja            │              │
    │  Pin 3: ATN  ├─────────┤├──────────────────┤ D2 (INT0)    │
    │              │        100Ω                  │              │
    │  Pin 4: CLK  ├─────────┤├──────────────────┤ D3           │
    │              │        100Ω                  │              │
    │  Pin 5: DATA ├─────────┤├──────────────────┤ D4           │
    │              │        100Ω                  │              │
    │  Pin 6: RESET├─────────┤├──────────────────┤ D5           │
    │              │                              │              │
    │  Pin 2: GND  ├──────────────────────────────┤ GND          │
    │              │                              │              │
    └──────────────┘                             └──────────────┘

  Valinnaiset pull-up vastukset:

         +5V         +5V         +5V
          │           │           │
        4.7kΩ       4.7kΩ       4.7kΩ
          │           │           │
    ATN ──┘     CLK ──┘    DATA ──┘
```

## 23LC512 SPI SRAM (64 KB)

```
                    +5V
                     │
                    100nF      (bypass-kondensaattori
                     │          mahdollisimman lähelle
                    GND         piirin VCC/GND-pinnejä)

                23LC512
               ┌────┬────┐
    D10 ───────┤1 /CS  VCC├───── +5V
               │         8│
    D12 ←──────┤2 SO  /HLD├───── +5V  (HOLD ei käytössä, vedetään HIGH)
               │         7│
               │3 NC   SCK├───── D13 (SCK)
               │         6│
    GND ───────┤4 VSS   SI├───── D11 (MOSI)
               └──────────┘  5

  Pinnit:
    1  /CS   ← Arduino D10 (Chip Select, active LOW)
    2  SO    → Arduino D12 (MISO, data out)
    3  NC    (ei kytketä)
    4  VSS   → GND
    5  SI    ← Arduino D11 (MOSI, data in)
    6  SCK   ← Arduino D13 (SPI Clock)
    7  /HOLD ← +5V (ei käytetä, vedetään HIGH)
    8  VCC   ← +5V

  SPI Mode 0 (CPOL=0, CPHA=0), max 20 MHz
  Arduino SPI @ 8 MHz (16 MHz / 2) → ~1 MB/s
```

## 74HC595 Shift Register (floppy output -signaalit)

```
  8 floppy output -signaalia ohjataan yhdellä 74HC595:llä
  SPI-väylän kautta. Tämä vapauttaa 8 GPIO-pinniä Nanosta.

                    +5V
                     │
                    100nF
                     │
                    GND

                74HC595
               ┌────┬────┐
  /DENSITY ←───┤1 QB  VCC├───── +5V
               │        16│
  /MOTEA   ←───┤2 QC  QA ├───── /SIDE1 (→ IDC pin 32)
               │        15│                    ┌── 10kΩ ── +5V
  /DRVSEL  ←───┤3 QD  SER├───── D11 (MOSI)    │  (pull-up: tri-state
               │        14│                    │   bootissa kunnes
  /MOTOR   ←───┤4 QE RCLK├───── D6 ��─┬────    │   firmware aktivoi)
               │        12│          │         │
  /DIR     ←───┤5 QF SRCK├───── D13  10kΩ     │
               │        11│          │         │
  /STEP    ←───┤6 QG /CLR├───── +5V  GND      │
               │        10│   (pull-down:      │
  /WGATE   ←───┤7 QH  /OE├───── A3 ──┘──���─────┘
               │         9│   (firmware ohjaa LOW kun valmis)
  GND ─────────┤8 GND QH'├───── (ei käytetä)
               └──────────┘

  Boot-turvallisuus:
  - RCLK:n 10kΩ pull-down estää vahingollisen latchin ennen
    kuin firmware alustaa D6:n output LOW:ksi
  - /OE:n 10kΩ pull-up pitää lähdöt tri-state (high-Z) kunnes
    firmware ajaa A3:n LOW. Floppy-aseman omat pull-upit pitävät
    signaalit HIGH (deasserted) tri-state-aikana.
  - /WGATE ei voi vahingossa mennä päälle boot/reset-hetkellä

  Toiminta:
  1. Arduino lähettää 8 bittiä SPI:llä (MOSI + SCK)
     - /CS_SRAM on HIGH (SRAM ei reagoi)
  2. Arduino pulsittaa D6:n (RCLK) HIGH→LOW
     → 74HC595 siirtää shift registerin sisällön lähtöihin
  3. Floppy-signaalit päivittyvät

  Bittijärjestys (MSB first):
    Bit 7 (QH) = /WGATE
    Bit 6 (QG) = /STEP
    Bit 5 (QF) = /DIR
    Bit 4 (QE) = /MOTOR
    Bit 3 (QD) = /DRVSEL
    Bit 2 (QC) = /MOTEA
    Bit 1 (QB) = /DENSITY
    Bit 0 (QA) = /SIDE1

  Koodiesimerkki:
    void floppy_set_outputs(uint8_t bits) {
        digitalWrite(CS_SRAM, HIGH);   // Varmista SRAM pois
        SPI.transfer(bits);            // Siirrä 8 bittiä
        digitalWrite(LATCH_595, HIGH); // Lukitse lähtöihin
        digitalWrite(LATCH_595, LOW);
    }
```

## SPI-väylän jakaminen

```
  SRAM ja 74HC595 jakavat SPI-väylän (MOSI, MISO, SCK).
  Chip Select -signaalit erottavat ne:

         Arduino Nano
        ┌──────────────┐
        │              │
        │ D11 (MOSI) ──┼──────┬──────────────┐
        │              │      │              │
        │ D12 (MISO) ──┼──────┤              │
        │              │      │              │
        │ D13 (SCK) ───┼──────┤──────────┐   │
        │              │      │          │   │
        │ D10 (/CS) ───┼──┐   │          │   │
        │              │  │   │          │   │
        │ D6 (LATCH) ──┼──┼───┼──────┐   │   │
        │              │  │   │      │   │   │
        └──────────────┘  │   │      │   │   │
                          │   │      │   │   │
                     ┌────┴───┴──┐ ┌─┴───┴───┴──┐
                     │ 23LC512  │ │  74HC595    │
                     │           │ │             │
                     │ /CS ← D10│ │ SER ← MOSI  │
                     │ SI ← MOSI│ │ SRCLK ← SCK │
                     │ SO → MISO│ │ RCLK ← D6   │
                     │ SCK ← SCK│ │             │
                     └──────────┘ └─────────────┘

  Käyttöprotokolla:
  ─────────────────

  SRAM-operaatio:
    1. D10 = LOW  (SRAM valittu)
    2. D6  = LOW  (595 latch ei muutu)
    3. SPI.transfer(...)
    4. D10 = HIGH (SRAM deselected)

  595-operaatio:
    1. D10 = HIGH (SRAM deselected)
    2. SPI.transfer(byte)  ← bittit siirtyvät 595:een
    3. D6 = HIGH → LOW     ← latchi! lähdöt päivittyvät

  Näin SRAM ja 595 eivät häiritse toisiaan.
```

## Floppy-asema (34-pin IDC)

```
  Output-signaalit 74HC595:n kautta:

         74HC595                          34-pin IDC
        ┌──────────────┐                 ┌──────────────────┐
        │              │                 │                  │
        │ QB /DENSITY ─┼─────────────────┤  pin 2           │
        │ QC /MOTEA ───┼─────────────────┤  pin 10          │
        │ QD /DRVSEL ──┼─────────────────┤  pin 12          │
        │ QE /MOTOR ───┼─────────────────┤  pin 16          │
        │ QF /DIR ─────┼─────────────────┤  pin 18          │
        │ QG /STEP ────┼─────────────────┤  pin 20          │
        │ QH /WGATE ───┼─────────────────┤  pin 24          │
        │ QA /SIDE1 ───┼─────────────────┤  pin 32          │
        └──────────────┘                 │                  │
                                         │                  │
  Suorat GPIO (tarkka ajoitus tarpeen):  │                  │
                                         │                  │
         Arduino Nano                    │                  │
        ┌──────────────┐                 │                  │
        │ D7  /WDATA ──┼─────────────────┤  pin 22          │
        │              │                 │  (MFM write data)│
        │ D8  /RDATA ──┼──── 74LS14 ─────┤  pin 30          │
        │  (ICP1)      │   (Schmitt)     │  (MFM read data) │
        │              │   │             │                  │
        │ A0  /TRK00 ──┼───┤─────────────┤  pin 26          │
        │              │   ┌─ 10kΩ──5V   │                  │
        │ A1  /WPT ────┼───┤─────────────┤  pin 28          │
        │              │   ┌─ 10kΩ──5V   │                  │
        │ A2  /DSKCHG ─┼───┤─────────────┤  pin 34          │
        │              │                 │                  │
        │ GND ─────────┼─────────────────┤  pins 1,3,...,33 │
        └──────────────┘                 └──────────────────┘

  HUOM: /WDATA (D7) tarvitsee suoran GPIO-kytkennän (MFM-kirjoitus).
  /RDATA (D8) kulkee 74LS14 Schmitt-triggerin läpi joka terävöittää
  hitaat reunat ja poistaa muuttuvan viiveen MFM-lukusignaalista.
  Katso "74LS14 Schmitt-trigger puskuri" -osio.
```

## Arduino Nano — Pinout (Vaihtoehto E)

```
                        ┌──────────┐
                  ┌─────┤  USB     ├─────┐
                  │     └──────────┘     │
                  │     Arduino Nano     │
                  │                      │
    (TX)     D1  [1] │                      │ [30] VIN
    (RX)     D0  [2] │                      │ [29] GND
           /RST  [3] │                      │ [28] /RST
             GND [4] │                      │ [27] +5V ← PSU
    ATN      D2  [5] │                      │ [26] A7
    CLK      D3  [6] │                      │ [25] A6
    DATA     D4  [7] │                      │ [24] A5 ← LED
    RESET    D5  [8] │                      │ [23] A4 (vapaa)
    595LATCH D6  [9] │                      │ [22] A3 → 595 /OE
    WDATA    D7 [10] │                      │ [21] A2 ← /DSKCHG
    RDATA    D8 [11] │(ICP1)                │ [20] A1 ← /WPT
    (vapaa)  D9 [12] │                      │ [19] A0 ← /TRK00
    /CS_SRAM D10[13] │                      │ [18] AREF
    MOSI     D11[14] │→ SRAM SI + 595 SER   │ [17] 3V3
    MISO     D12[15] │← SRAM SO             │ [16] D13 SCK
                  │                      │        → SRAM SCK
                  │                      │        + 595 SRCLK
                  └──────────────────────┘

  GPIO-yhteenveto:
    D0-D1:   Serial (USB debug)
    D2-D5:   IEC-väylä (ATN/INT0, CLK, DATA, RESET)
    D6:      74HC595 Latch (RCLK)
    D7:      /WDATA (suora GPIO, MFM-kirjoitus)
    D8:      /RDATA (ICP1, MFM-luku Timer1 Input Capture)
    D9:      Vapaa
    D10:     23LC512 /CS
    D11-D13: SPI (MOSI, MISO, SCK) → SRAM + 595
    A0-A2:   Floppy input (/TRK00, /WPT, /DSKCHG)
    A3:      74HC595 /OE (output enable, active LOW)
    A4:      Vapaa
    A5:      Status LED
```

## Virtalähde

```
    Ulkoinen 5V/2A PSU
    ┌──────────┐
    │          │
    │ +5V ─────┼──┬───── Arduino Nano +5V (pin 27)
    │          │  │
    │          │  ├───── 23LC512 VCC (pin 8)
    │          │  │
    │          │  ├───── 74HC595 VCC (pin 16)
    │          │  │
    │          │  └───── Floppy-asema +5V
    │          │
    │ GND ─────┼──┬───── Arduino Nano GND
    │          │  ├───── 23LC512 VSS (pin 4)
    │          │  ├───── 74HC595 GND (pin 8)
    │          │  └───── Floppy-asema GND
    └──────────┘
```

## Kokonaispiirikaavio

```
    C64                                                       Floppy-asema
  ┌──────┐                                                   ┌───────────┐
  │      │                                                   │ PC 3.5"   │
  │ IEC  │      Arduino Nano                                  │ HD 1.44MB │
  │ port │     ┌────────────────┐                             │           │
  │      │     │   ATmega328P   │     23LC512      74HC595   │  34-pin   │
  │      │     │                │    ┌────────┐   ┌────────┐  │  IDC      │
  │      │100Ω │                │    │ 64KB   │   │ 8-bit  │  │           │
  │ ATN  ├─┤├──┤ D2 (INT0)     │    │ SPI    │   │ shift  │  │           │
  │ CLK  ├─┤├──┤ D3            │    │ SRAM   │   │ reg    │  │           │
  │ DATA ├─┤├──┤ D4            │    │        │   │        │  │           │
  │ RESET├─┤├──┤ D5            │    │        │   │        │  │           │
  │ GND  ├─────┤ GND          │    │        │   │        │  │           │
  │      │     │               │    │        │   │        │  │           │
  └──────┘     │ D10 (/CS) ────┼────┤ /CS    │   │        │  │           │
               │               │    │        │   │        │  │           │
               │ D11 (MOSI) ───┼──┬─┤ SI     │ ┌─┤ SER    │  │           │
               │               │  │ │        │ │ │        │  │           │
               │ D12 (MISO) ───┼──┤─┤ SO     │ │ │        │  │           │
               │               │  │ │        │ │ │        │  │           │
               │ D13 (SCK) ────┼──┴─┤ SCK    │ ├─┤ SRCLK  │  │           │
               │               │    │        │ │ │        │  │           │
               │               │    │ /HOLD──┤5V│        │  │           │
               │               │    │ VCC────┤5V│ VCC──5V│  │           │
               │               │    │ GND────┤G │ GND──G │  │           │
               │               │    └────────┘ │ │        │  │           │
               │               │               │ │ QB─────┼──┤ /DENSITY  │
               │ D6 (LATCH) ───┼───────────────┘─┤ RCLK   │  │           │
               │               │                 │ QC─────┼──┤ /MOTEA    │
               │               │                 │ QD─────┼──┤ /DRVSEL   │
               │               │                 │ QE─────┼──┤ /MOTOR    │
               │               │                 │ QF─────┼──┤ /DIR      │
               │               │                 │ QG─────┼──┤ /STEP     │
               │               │                 │ QH─────┼──┤ /WGATE    │
               │               │                 │ QA─────┼──┤ /SIDE1    │
               │               │                 └────────┘  │           │
               │ D7 (/WDATA) ──┼──────────────────────────────┤ /WDATA    │
               │               │           ┌── 10kΩ──5V      │           │
               │ D8 (/RDATA) ──┼───────────┤──────────────────┤ /RDATA    │
               │  (ICP1)       │           │                  │           │
               │               │           ┌── 10kΩ──5V      │           │
               │ A0 (/TRK00) ──┼───────────┤──────────────────┤ /TRK00    │
               │               │           ┌── 10kΩ──5V      │           │
               │ A1 (/WPT) ────┼───────────┤──────────────────┤ /WPT      │
               │               │           ┌── 10kΩ──5V      │           │
               │ A2 (/DSKCHG) ─┼───────────┤──────────────────┤ /DSKCHG   │
               │               │                              │           │
               │ GND ──────────┼──────────────────────────────┤ GND       │
               │               │                              │           │
               │ A5 ──┤├── LED │                              │ +5V ← PSU│
               │      330Ω     │                              │           │
               └───────────────┘                              └───────────┘

  +5V PSU ──────────────────────────────────────────────────────────┐
  GND PSU ──────────────────────────────────────────────────────────┤
                │          │           │            │               │
              Nano +5V   SRAM VCC    595 VCC    Floppy +5V    Bypass caps
              Nano GND   SRAM GND    595 GND    Floppy GND    3x 100nF
```

## 74LS14 Schmitt-trigger puskuri (/RDATA-signaalin terävöitys)

```
  Floppy-aseman /RDATA-signaali nousee hitaasti aseman sisäisen
  elektroniikan takia. Tämä aiheuttaa muuttuvan viiveen ICP-
  reunatunnistuksessa → MFM-pulssit luokitellaan väärin.

  74LS14 (tai 74HC14) on Schmitt-trigger invertterin joka:
  - Terävöittää hitaat reunat → vakio ~15ns propagaatioviive
  - Poistaa muuttuvan viiveen → puhtaat 2T/3T/4T-klusterit
  - Hystereesi (1.7V/0.9V) estää kohinatriggeröinnin

  Huom: 74LS14/74HC14 on INVERTOIVA. Käytetään yhtä porttia
  ja vaihdetaan ICP1 edge-tunnistus nousevaksi reunaksi softassa:
    TCCR1B |= (1 << ICES1);  /* Rising edge (inverted) */

  Tai kaksoiinversio kahdella portilla (ei softamuutosta).

  Vaihtoehto A: yksi inversio + softamuutos (suositeltu)
  ──────────────────���───────────────────────────────────

                    +5V
                     │
                    100nF
                     │
                    GND

                 74LS14
                ┌────┬──���─┐
  /RDATA ───────┤1 1A  VCC├───── +5V
                │        14│
  Arduino D8 ←──┤2 1Y  GND├───── GND
                │         7│
                │  (muut portit: input → GND)
                └──────────┘

  Floppy /RDATA (pin 30)
       │
       ├─── 150Ω ── +5V  (pull-up, edelleen tarpeen)
       │
       └─── 74LS14 pin 1 (1A, input)
                    pin 2 (1Y, output) ──→ Arduino D8 (ICP1)

  Softamuutos mfm_init():
    TCCR1B |= (1 << ICES1);   /* Rising edge (74LS14 invertoi) */

  Vaihtoehto B: kaksoiinversio, ei softamuutosta
  ──────────────────────────────────────────────

  /RDATA ──→ 74LS14 pin 1 (1A)
              pin 2 (1Y) ─���→ pin 3 (2A)
              pin 4 (2Y) ──→ Arduino D8

  Tulos: signaali kulkee kahden invertterin läpi → alkuperäinen
  polariteetti säilyy. ICP pysyy falling edge -tilassa.
  Viive: ~30ns (2 × 15ns).

  Vaihtoehto C: aktiivinen pull-up transistorilla
  ──────────────────────────────────────────────

  Ongelma: passiivinen pull-up -vastus (150Ω-1.5kΩ) ei voi olla
  sekä tarpeeksi pieni (nopea nousu) että tarpeeksi suuri
  (asema pystyy vetämään linjan alle 0.9V pulssin aikana).

  Ratkaisu: NPN-transistori toimii aktiivisena pull-upina joka
  vetää linjaa vahvasti HIGH-tilaan lepotilassa, mutta sammuu
  pulssin aikana eikä vastusta aseman open-collector -vetoa.

              +5V
               │
              1kΩ  (R_c, kollektorivastus)
               │
               ├─────────────────── /RDATA-linja ── 74LS14 pin 1
               │                         │
           C ──┤ 2N3904 (NPN)            │
               │                     Floppy /RDATA
           E ──┤                     (open-collector)
               │
              GND
               │
           B ──┤
               │
              10kΩ (R_b, kantavastus)
               │
               ├── +5V

  Toiminta:
    Lepotila: R_b vetää kannan HIGH → transistori ON → kollektori
    vetää /RDATA-linjaa aktiivisesti kohti +5V (nopea nousu).
    Nousuaika riippuu R_c:stä ja kuormasta, tyypillisesti ~10-20ns.

    Pulssin aikana: floppy-aseman OC-transistori vetää linjan LOW.
    NPN:n emitteri on GND:ssä, kollektori on /RDATA-linjalla.
    Kun linja putoaa alle ~0.7V, NPN:n VCE < VBE → transistori
    sammuu (saturoituu "väärin päin"). Asema pystyy vetämään
    linjan 0V:iin koska NPN ei enää vastusta.

    Vaihtoehtoinen kytkentä (emitteriseuraajapohjaiinen):

              +5V
               │
              10kΩ (R_b)
               │
           B ──┤ 2N3904
               │
           C ──┤── GND
               │
           E ──┤
               │
               ├── /RDATA-linja ── 74LS14 pin 1
               │
           Floppy /RDATA (open-collector)

    Emitteriseuraaja: V_out ≈ V_base - 0.7V ≈ 4.3V lepotilassa.
    Kun floppy vetää linjaa alas, emitteri seuraa → nopea lasku.
    Emitteriseuraajan ulostuloresistanssi on matala (~20Ω) →
    erittäin nopea nousu takaisin ilman erillistä pull-up-vastusta.
    Mutta: max V_out = 4.3V (ei täyttä 5V). Riittää 74LS14:lle
    jonka positiivinen kynnys on 1.7V.

  Komponentit:
    - 2N3904 NPN-transistori (tai BC547, yleinen NPN)
    - 10kΩ vastus (kanta)
    - 1kΩ vastus (kollektori, vaihtoehto 1)

  Oloskooppilla todennettavat parametrit:
    - /RDATA-pulssin alareuna: < 0.5V (asema vetää kunnolla)
    - Nousuaika: < 100ns (0.3V → 1.7V)
    - Pulssin leveys: ~150-250ns
    - Intervallien jitteri: < ±5 tikkiä (±312ns)

  Yhteensopivat piirit:
    74LS14   — TTL Schmitt-trigger, 5V, DIP-14
    74HC14   — CMOS Schmitt-trigger, 5V, DIP-14 (pienempi virrankulutus)
    74HCT14  — CMOS + TTL-yhteensopivat kynnykset, 5V, DIP-14
    SN74LS14 — Texas Instruments versio 74LS14:stä

  Kaikki ovat pin-yhteensopivia. 74HC14 suositeltu uusiin piireihin
  (pienempi virta), 74LS14 toimii yhtä hyvin.

  Käyttämättömät portit: kytke inputit (3A, 4A, 5A, 6A) → GND.
```

## Bypass-kondensaattorit

```
  Jokaiselle IC:lle 100nF keraaminen bypass-kondensaattori
  VCC-GND väliin, mahdollisimman lähelle piirin jalkoja:

    +5V ──┤├── GND   (Arduino Nano, lähellä +5V/GND pinnejä)
          100nF

    +5V ──┤├── GND   (23LC512, pin 8 ja pin 4 väliin)
          100nF

    +5V ──┤├── GND   (74HC595, pin 16 ja pin 8 väliin)
          100nF

    +5V ──┤├── GND   (74LS14, pin 14 ja pin 7 väliin)
          100nF

  Lisäksi bulk-kondensaattori virtalähteen liittimeen:
    +5V ──┤├── GND   (10µF elektrolyyttinen)
```

## Komponenttilista (BOM)

```
  Nro  Komponentti            Paketti       Kpl   Huomio
  ───  ─────────────────────  ────────────  ───   ────────────────────────
   1   Arduino Nano (klooni)  DIP-moduuli    1   ATmega328P, 16MHz, 5V
   2   23LC512               DIP-8          1   64KB SPI SRAM, 5V
   3   74HC595                DIP-16         1   8-bit shift register
  3b  74LS14 tai 74HC14      DIP-14         1   Schmitt-trigger /RDATA puskuri
   4   Vastus 100Ω            1/4W           4   IEC-suojavastukset
   5   Vastus 4.7kΩ           1/4W           3   IEC pull-up (valinnainen)
   6   Vastus 10kΩ            1/4W           5   Floppy pull-up: /TRK00, /WPT, /DSKCHG (3) + RCLK pull-down (1) + /OE pull-up (1)
  6b  Vastus 150Ω            1/4W           1   /RDATA pull-up (PC-standardi, nopea MFM-signaali)
   7   Vastus 330Ω            1/4W           1   LED-vastus
   8   Kond. 100nF            keraami.       4   Bypass (Nano, SRAM, 595, 74LS14)
   9   Kond. 10µF             elektrol.      1   Bulk virta
  10   LED vihreä             3mm            1   Tilaindikaattori
  11   6-pin DIN liitin       DIN-6          1   IEC-väylä
  12   34-pin IDC header      2x17 pin       1   Floppy-liitäntä
  13   4-pin Berg liitin      Berg           1   Floppy-virta
  14   DC jack 5.5/2.1mm      panel mount    1   Virtalähde
  15   Pin headerit           2.54mm         -   Nanon + IC:den kiinnitys
  ──────────────────────────────────────────────────────────────────
  Yhteensä (ilman Nanoa ja floppy-asemaa):             ~7€
  Yhteensä (Nano-kloonilla):                           ~10-13€
```

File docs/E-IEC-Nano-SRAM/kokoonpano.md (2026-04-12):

# 64korppu E — Kokoonpano-ohje (2-layer)

## Tarvikkeet

- Juotoskolvi (~350 °C)
- Lyijyllinen tinajuote (Sn60/Pb40, ø 0.5–1.0 mm)
- Sivuleikkurit
- Kolmas käsi tai PCB-pidike
- IC-kannat: DIP-8 (U2) ja DIP-16 (U3)
- Pin headerit: 2 × 15 female (U1 Nano)

## Komponenttilista

| Ref | Komponentti | Kotelo | Huom |
|-----|---|---|---|
| U1 | Arduino Nano | 2×15 pin header | Female headerit levylle |
| U2 | 23LC512 / 23LCV512 | DIP-8 | SPI SRAM 64KB |
| U3 | 74HC595 | DIP-16 | Shift register |
| J1 | DIN-6 liitin | Pystysuora | IEC-väylä (C64) |
| J2 | IDC 2×17 header | Pystysuora | Floppy-kaapeli |
| J3 | Barrel jack | 5.5/2.1 mm | Virtaliitin |
| R1–R7 | Vastukset | Axial | IEC-väylän vastukset |
| R8 | Vastus | Axial | LED-virranrajoitin |
| R9–R12 | Vastukset | Axial | Floppy pull-up |
| C1–C3 | Keraaminen kondensaattori | Disc 100 nF | Bypass-kondikat |
| C4 | Elektrolyyttikondensaattori | Radial | Syöttösuodatus |
| D1 | LED | 3 mm / 5 mm | Tila-LED |
| H1–H4 | Kiinnitysruuvit | M3 | Valinnainen |

## Juottamisen periaate

Kaikki komponentit ovat through-hole (THT):

1. **Työnnä** komponentin jalat levyn etupuolelta (silkscreen-teksteillä merkitty puoli) reikien läpi
2. **Käännä** levy ympäri
3. **Juota** jalat takapuolelta (B.Cu)
4. **Leikkaa** ylimääräiset jalat sivuleikkurilla

Kaikki juotetaan samalta puolelta — ei tarvitse juottaa mitään etupuolella.

## Juotusjärjestys

Juota matalimmasta korkeimpaan, jotta komponentit pysyvät paikallaan kun levy on ylösalaisin:

### 1. Vastusten R1–R12

- Taivuta jalat 90° kohdasta jossa ne menevät runkoon
- Työnnä reikiin, taivuta jalat hieman levyn alla jotta pysyy paikallaan
- Juota, leikkaa ylimääräiset jalat

### 2. IC-kannat (U2, U3)

- **Älä juota siruja suoraan** — käytä IC-kantoja
- Tarkista kannan lovi vastaa silkscreen-merkintää (pin 1)
- Juota ensin kaksi vastakkaista kulmaa, tarkista suoruus, juota loput

### 3. Keraamiskondensaattorit C1–C3

- Ei napaisuutta, menee kummin päin tahansa

### 4. LED D1

- **Napainen!** Pidempi jalka = anodi (+), lyhyempi = katodi (−)
- Tarkista silkscreen-merkintä levyltä

### 5. Elektrolyyttikondensaattori C4

- **Napainen!** Raita kotelossa = miinusjalka (−)
- Tarkista silkscreen-merkintä

### 6. Liittimet J1, J2, J3

- **J1 (DIN-6):** IEC-liitin, shield-jalat menevät myös reikiin
- **J2 (IDC 2×17):** Pitkä header, tarkista suunta (lovi osoittaa oikein)
- **J3 (Barrel jack):** Isot padit, tarvitsee enemmän lämpöä

### 7. Arduino Nano pin headerit

- Juota 2 × 15 pin female headerit levylle
- Nano painetaan paikoilleen headereihin (irrotettava)

### 8. IC-piirit kantaan

- Aseta U2 (23LC512) ja U3 (74HC595) kantoihinsa
- Tarkista pin 1 -merkintä (lovi) ennen painamista

## Juotosvinkit

- **Kolvi padiin ja jalkaan yhtä aikaa ~2 s** → syötä tinaa → irrota kolvi
- Hyvä juotos on kiiltävä ja kartion muotoinen (ei pallon muotoinen)
- Kylmäjuotos (mattapintainen, rosoinen) → lämmitä uudelleen ja lisää tinaa
- Tina-silta kahden padin välillä → poista juotospumpulla tai juotosnauhalla

## Reset-nappi (valinnainen)

Arduino Nanon voi varustaa ulkoisella reset-napilla:

1. Kytke hetkellinen painonappi (normally open) Nanon **RST**-pinnin ja **GND**-pinnin väliin
2. Nanossa on sisäinen pull-up-vastus RST-pinnissä, joten ulkoista pull-upia ei tarvita
3. Napin painaminen vetää RST-pinnin maahan → Nano resetoituu

Nappi ei ole PCB:llä — se kytketään hyppylangalla suoraan Nanon headereihin.

> **Vinkki:** 100 nF keraaminen kondensaattori napin yli (RST–GND) vähentää mekaanista värähtelyä (debounce), mutta ei ole välttämätön.

## Test pointit (TP1–TP14)

Levyn takapuolella (B.Cu) on 14 testipistettä. Näitä **ei juoteta** — ne ovat mittauspisteitä joihin voi koskea yleismittarin koetinkärjellä vianetsinnässä. Katso [diagnostiikkapadit.md](diagnostiikkapadit.md) lisätietoja.

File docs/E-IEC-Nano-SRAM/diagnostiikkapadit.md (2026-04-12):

# Diagnostiikkapadit (Test Points) — 4-layer PCB

14 SMD-testipistettä PCB:n taustapuolella (B.Cu), vasemmassa reunassa pystyrivinä.
Kaikki padit ovat 1.5mm pyöreitä kuparipadeja ilman juotepastaa — mittapää koskettaa suoraan kupariin.

## Padien sijainnit ja signaalit

```
    PCB:n vasen reuna (x = 103mm)
    ────────────────────────────────

    TP1  ● GND              y = 108.0mm
    TP2  ● +5V              y = 110.5mm
         ─── jännitteet ───
    TP3  ● IEC_ATN           y = 113.0mm
    TP4  ● IEC_CLK           y = 115.5mm
    TP5  ● IEC_DATA          y = 118.0mm
         ─── IEC-väylä ───
    TP6  ● FLOPPY_MOTOR      y = 120.5mm
    TP7  ● FLOPPY_STEP       y = 123.0mm
    TP8  ● FLOPPY_RDATA      y = 125.5mm
    TP9  ● FLOPPY_WDATA      y = 128.0mm
    TP10 ● FLOPPY_SIDE1      y = 130.5mm
         ─── floppy-väylä ───
    TP11 ● SPI_SCK            y = 133.0mm
    TP12 ● SPI_MOSI           y = 135.5mm
    TP13 ● SPI_MISO           y = 138.0mm
    TP14 ● SPI_CS_SRAM        y = 140.5mm
         ─── SPI-väylä ───
```

## Signaalien selitykset

### Jännitteet (TP1-TP2)

| Padi | Signaali | Odotettu taso | Merkitys |
|---|---|---|---|
| TP1 | GND | 0V | Maareferenssi. Kiinnitä yleismittarin musta johto tähän. |
| TP2 | +5V | 4.8–5.2V | Käyttöjännite. Jos puuttuu, mikään ei toimi. Tarkista virtalähde ja barrel jack. |

### IEC-väylä / C64 (TP3-TP5)

Nämä signaalit kulkevat C64:n ja Arduinon välillä 100Ω suojavastusten läpi.
Kaikki ovat open collector: lepotilassa HIGH (4.7kΩ pull-up → +5V), aktiivisena LOW.

| Padi | Signaali | Lepotila | Aktiivinen | Merkitys |
|---|---|---|---|---|
| TP3 | IEC_ATN | HIGH (~5V) | LOW (0V) | **Attention** — C64 lähettää komennon. Pulssittaa LOW kun C64 kutsuu laitetta. Jos pysyy LOW, C64 on jumissa. Jos pysyy HIGH, C64 ei kommunikoi. |
| TP4 | IEC_CLK | HIGH (~5V) | LOW (0V) | **Clock** — kellosignaali. Datansiirron aikana vaihtelee HIGH/LOW. Bittiväli ~60-80µs. |
| TP5 | IEC_DATA | HIGH (~5V) | LOW (0V) | **Data** — databitit. Talker vetää LOW lähettäessään 0-bitin. |

**Pikadiagnostiikka:**
- Kaikki HIGH → C64 ei ole käynnissä tai IEC-kaapeli irti
- ATN pulssittaa, CLK/DATA eivät → Arduino ei vastaa C64:lle
- Kaikki LOW → oikosulku tai komponentti viallinen

### Floppy-signaalit (TP6-TP10)

Nämä ohjataan 74HC595 shift registerin (TP6-TP7, TP10) tai suoran GPIO:n (TP8-TP9) kautta.
Kaikki floppy-signaalit ovat aktiivisia LOW-tilassa (negatiivinen logiikka).

| Padi | Signaali | Lepotila | Aktiivinen | Merkitys |
|---|---|---|---|---|
| TP6 | FLOPPY_MOTOR | HIGH (~5V) | LOW (0V) | **Moottorin käynnistys.** LOW = moottori pyörii. Tarkista: aseman moottori pyörii kun LOW. Jos HIGH eikä moottori pyöri, signaali ei kulje. |
| TP7 | FLOPPY_STEP | HIGH (~5V) | pulssi LOW | **Askelpulssi.** Jokainen LOW-pulssi siirtää lukupäätä yhden raidan. Seuraavien aikana pitäisi näkyä 3ms pulsseja oskilloskoopilla. |
| TP8 | FLOPPY_RDATA | HIGH (~5V) | pulssijuna | **Luettu data (MFM).** Nopea pulssijuna (~4-8µs väli) kun asema lukee levyä. Vaatii oskilloskoopin. Jos pysyy HIGH levyn pyöriessä, lukupää tai asema on viallinen. |
| TP9 | FLOPPY_WDATA | HIGH (~5V) | pulssijuna | **Kirjoitettava data (MFM).** Nopea pulssijuna kirjoituksen aikana. Vaatii oskilloskoopin. |
| TP10 | FLOPPY_SIDE1 | HIGH (~5V) | LOW (0V) | **Levyn puoli.** HIGH = puoli 0 (yläpuoli), LOW = puoli 1 (alapuoli). DD-levyillä vain puoli 0. |

**Pikadiagnostiikka:**
- MOTOR LOW mutta asema ei pyöri → tarkista floppy-virta (4-pin Berg) ja IDC-kaapeli
- RDATA pysyy HIGH moottorin pyöriessä → lukupää ei lue, levy viallinen, tai asema rikki
- STEP ei pulssita seek-komennolla → 74HC595 tai SPI-väylä viallinen

### SPI-väylä (TP11-TP14)

SPI-väylä on jaettu 23LC256 SRAM:n ja 74HC595 shift registerin kesken.
SCK ja MOSI menevät molemmille, MISO tulee vain SRAM:lta. CS_SRAM valitsee SRAM:n.

| Padi | Signaali | Lepotila | Aktiivinen | Merkitys |
|---|---|---|---|---|
| TP11 | SPI_SCK | LOW (0V) | kellopulssijuna | **SPI Clock.** 8 MHz kellosignaali SPI-siirron aikana (Mode 0, CPOL=0). Oskilloskoopilla näkyy siistit 125ns pulssit. |
| TP12 | SPI_MOSI | vaihtelee | datapulssit | **Master Out, Slave In.** Arduino → SRAM/595 data. Vaihtuu SCK:n nousevalla reunalla. |
| TP13 | SPI_MISO | HIGH (Z) | datapulssit | **Master In, Slave Out.** SRAM → Arduino data. Aktiivinen vain kun CS_SRAM = LOW. Jos pysyy HIGH tai LOW CS:n ollessa LOW ja SCK pulssittaessa → SRAM viallinen tai kytös rikki. |
| TP14 | SPI_CS_SRAM | HIGH (~5V) | LOW (0V) | **SRAM Chip Select.** LOW = SRAM valittu. HIGH = SRAM pois, 595 voidaan ohjata. Jos pysyy LOW → SPI-väylä jumissa. |

**Pikadiagnostiikka:**
- SCK ei pulssita → SPI ei alustautunut, tarkista Arduino-firmware
- CS_SRAM pysyy LOW → koodi ei vapauta SRAM:a, 595 ei saa komentoja
- MISO pysyy HIGH CS:n ollessa LOW → SRAM-piiri viallinen tai kylmäjuotos

## Mittausohje

### Yleismittarilla (DC-jännite)

1. Kytke musta johto **TP1 (GND)**
2. Mittaa punainen johto muihin padeihin
3. Tarkista:
   - TP2 (+5V): pitää olla 4.8–5.2V
   - Lepotilassa IEC-signaalit (TP3-TP5): ~5V (pull-up)
   - Lepotilassa floppy-signaalit (TP6-TP10): ~5V (inaktiivinen)
   - TP14 (CS_SRAM): ~5V (SRAM ei valittuna)

### Oskilloskoopilla

1. GND-clip → **TP1 (GND)**
2. Probe → haluttu signaali
3. Hyödylliset asetukset:

| Signaali | Aikaskaalaus | Jänniteskaalaus | Mitä etsiä |
|---|---|---|---|
| IEC_ATN | 1ms/div | 2V/div | ~80µs LOW-pulssit komennon alussa |
| IEC_CLK | 50µs/div | 2V/div | 60-80µs bittikello datan aikana |
| FLOPPY_STEP | 5ms/div | 2V/div | 3ms LOW-pulssit seekin aikana |
| FLOPPY_RDATA | 2µs/div | 2V/div | MFM-pulssijuna 4-8µs välein |
| SPI_SCK | 100ns/div | 2V/div | 8 MHz neliöaalto (125ns jakso) |

## Vianetsintätaulukko

| Oire | Tarkista | Todennäköinen syy |
|---|---|---|
| +5V puuttuu | TP2 | Virtalähde, barrel jack, sulake |
| C64 ei löydä laitetta | TP3 (ATN) | IEC-kaapeli, suojavastukset R1-R4 |
| ATN pulssittaa, ei vastausta | TP4, TP5 | Arduino-firmware, pull-up vastukset R5-R7 |
| Floppy ei pyöri | TP6 (MOTOR) | IDC-kaapeli, floppy-virta, 74HC595 |
| Ei lue levyä | TP8 (RDATA) | Asema viallinen, levy viallinen, lukupää |
| SPI ei toimi | TP11 (SCK) | Arduino SPI-alustus, piirin kytös |
| SRAM-virhe | TP13, TP14 | 23LC256 viallinen, kylmäjuotos |

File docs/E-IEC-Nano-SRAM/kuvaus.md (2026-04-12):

# Vaihtoehto E: IEC-väylä + Arduino Nano + Ulkoinen SRAM

## Arkkitehtuuri

```
C64 ──[IEC-sarjaväylä]──> Arduino Nano ──[34-pin]──> PC 3.5" HD floppy
                                │
                           [SPI-väylä]
                                │
                          SRAM (64KB)
```

## Motivaatio

Vaihtoehto D:n (pelkkä Nano) suurin ongelma on 2 KB sisäinen RAM:
- Kokonainen MFM-raita = ~12.5 KB (ei mahdu)
- FAT-taulu = 4.5 KB (ei mahdu)
- Sektoripuskuri + IEC-puskuri + pino = ~1.5 KB

Lisäämällä ulkoinen SRAM-piiri saadaan riittävästi muistia ilman
Picon monimutkaisuutta, ja säilytetään Nanon 5V-etu (ei tasonmuuntimia).

## SRAM-vaihtoehdot

### Vaihtoehto 1: 23LC512 SPI SRAM (Valittu)

| Ominaisuus | Arvo |
|---|---|
| Valmistaja | Microchip |
| Kapasiteetti | 64 KB (512 Kbit) |
| Liitäntä | SPI (20 MHz max) |
| Käyttöjännite | 1.8V - 5.5V (**5V yhteensopiva!**) |
| Pinnit | 8 (DIP-8 / SOIC-8) |
| Hinta | ~1.5€ (uusi, Mouser/Digikey/eBay) |
| Arduino-pinnit | 4 kpl (MOSI, MISO, SCK, /CS) |
| Osoiteleveys | 16-bit (vs. 23LC1024:n 24-bit) |

**Miksi tämä:** LZ4-pakkauksen puskurit (~1 KB) mahtuvat ulkoiseen SRAM:iin,
vapauttaen ATmega328P:n 2 KB sisäisen RAM:in pinolle ja muuttujille.
Sama DIP-8 pinout ja SPI-komennot kuin 23LC256/23LC1024. Drop-in vaihto.

### Vaihtoehto 3: 62256 Parallel SRAM (vanhoista laitteista)

| Ominaisuus | Arvo |
|---|---|
| Kapasiteetti | 32 KB |
| Liitäntä | Rinnakkainen (15 osoite + 8 data) |
| Saatavuus | Vanhoista tietokoneista, pelikonsoleista |
| Ongelma | **Tarvitsee 23 I/O-pinniä — Nanossa ei riitä!** |

**Ei käytännöllinen Nanon kanssa** ilman shift-rekistereitä (74HC595)
osoiteväylän multipleksointiin. Mahdollinen mutta monimutkainen.

### Vaihtoehto 4: 6264 SRAM (C64:stä tai vastaavasta)

- 8 KB, rinnakkainen
- Löytyy vanhoista C64-koneista, Amiga-laajennuksista, jne.
- Sama ongelma kuin 62256: liikaa pinnejä

### Suositus: 23LC256 (SPI)

SPI-liitäntä on ylivoimainen Nano-projektissa:
- Vain 4 pinniä (vs. 23+ rinnakkaiselle)
- 20 MHz SPI → ~2 MB/s siirtonopeus
- 32 KB riittää (todellinen käyttö ~22 KB)
- 5V natiivi

## Muistikartta (23LC512, 64 KB)

```
SRAM-osoite    Käyttö                    Koko
───────────────────────────────────────────────────
0x00000-0x030CF  MFM-raitapuskuri          12.5 KB
0x030D0-0x042CF  FAT-taulun cache          4.5 KB
0x042D0-0x044CF  Sektoripuskuri #1         512 B
0x044D0-0x046CF  Sektoripuskuri #2         512 B
0x046D0-0x056CF  Hakemistopuskuri          4 KB
0x056D0-0x058CF  IEC-kanavan puskuri       512 B
0x058D0-0x05ACF  LZ4 raakadata-puskuri     512 B
0x05AD0-0x05D0B  LZ4 kehyspuskuri          556 B
0x05D0C-0x0FFFF  Vapaa (~41.2 KB)          käytettävissä
───────────────────────────────────────────────────
```

Nanon sisäinen 2 KB RAM käytetään:
- Pinolle ja muuttujille (~512 B)
- SPI-siirtopuskurille (~256 B)
- IEC-tilakoneelle (~256 B)
- MFM-dekoodauksen välipuskurille (~512 B)
- LZ4-pakkauksen aikana: hash-taulu pinossa (~512 B, väliaikainen)
- Loppuosa vapaana

## Komponenttilista

| Komponentti | Kuvaus | Hinta (arvio) |
|---|---|---|
| Arduino Nano (klooni) | ATmega328P, 16 MHz, 5V | ~3-5€ |
| 23LC512 | 64KB SPI SRAM, DIP-8 | ~1.5€ |
| 6-pin DIN -liitin | IEC-väylä C64:lle | ~2€ |
| 34-pin IDC -liitin | PC-floppy | ~1€ |
| 4-pin Berg liitin | Virta floppy-asemalle | ~1€ |
| Vastukset 100Ω x4 | IEC-suojavastukset | ~0.5€ |
| Kond. 100nF x3 | Bypass | ~0.5€ |
| **Yhteensä** | | **~10-13€** |

## GPIO-allokaatio

### SPI-väylä (Nano ↔ 23LC256)

| Nano-pinni | SPI-signaali | 23LC256 pin | Huomio |
|---|---|---|---|
| D13 (SCK) | SPI Clock | pin 6 (SCK) | Jaettu floppy /WGATE kanssa! |
| D11 (MOSI) | SPI Data In | pin 5 (SI) | Jaettu floppy /STEP kanssa! |
| D12 (MISO) | SPI Data Out | pin 2 (SO) | Jaettu floppy /WDATA kanssa! |
| D10 | /CS (SRAM) | pin 1 (/CS) | - |

**ONGELMA:** SPI-pinnit (D11-D13) ovat samat kuin floppy-signaalit
vaihtoehdossa D. Tarvitaan uudelleenjärjestely!

### Päivitetty GPIO-kartta

```
IEC-väylä (suora 5V kytkentä):
  D2  = ATN (INT0 keskeytys)
  D3  = CLK
  D4  = DATA
  D5  = RESET

SPI SRAM:
  D10 = /CS (SRAM chip select)
  D11 = MOSI (SPI data out)  → 23LC256 SI
  D12 = MISO (SPI data in)   ← 23LC256 SO
  D13 = SCK  (SPI clock)     → 23LC256 SCK

Floppy output (uudelleenjärjestelty!):
  D6  = /DENSITY
  D7  = /MOTEA
  D9  = /MOTOR
  A0  = /DRVSEL  (siirretty analogipinniin)
  A1  = /DIR     (siirretty)
  A2  = /STEP    (siirretty)
  A3  = /WDATA   (siirretty)
  A4  = /WGATE   (siirretty)
  A5  = /SIDE1   (siirretty)

Floppy input:
  D8  = /RDATA   (ICP1 — Timer1 Input Capture!)

Ei enää vapaita pinnejä input-signaaleille /TRK00, /WPT, /DSKCHG!
```

**Pinnit loppuvat!** Arduino Nanossa on 22 digitaalista I/O-pinniä,
ja tarvitsemme: 4 (IEC) + 4 (SPI) + 10 (floppy out) + 4 (floppy in) = 22.

### Ratkaisu: SPI-väylän jakaminen + 74HC595 shift register

Lisätään yksi 74HC595 (shift register) floppy-output-signaalien
ohjaamiseen SPI-väylän kautta. Tämä vapauttaa 8 pinniä!

```
Floppy output-signaalit 74HC595:n kautta:
  SPI MOSI → 74HC595 SER (data in)
  SPI SCK  → 74HC595 SRCLK (shift clock)
  D6       → 74HC595 RCLK (latch clock)

  74HC595 QA = /SIDE1    (floppy pin 32)
  74HC595 QB = /DENSITY  (floppy pin 2)
  74HC595 QC = /MOTEA    (floppy pin 10)
  74HC595 QD = /DRVSEL   (floppy pin 12)
  74HC595 QE = /MOTOR    (floppy pin 16)
  74HC595 QF = /DIR      (floppy pin 18)
  74HC595 QG = /STEP     (floppy pin 20)
  74HC595 QH = /WGATE    (floppy pin 24)
```

**Päivitetty GPIO-kartta (74HC595:n kanssa):**

```
IEC-väylä:
  D2  = ATN (INT0)
  D3  = CLK
  D4  = DATA
  D5  = RESET

SPI (jaettu SRAM + 74HC595):
  D10 = /CS_SRAM
  D11 = MOSI  → SRAM SI + 74HC595 SER
  D12 = MISO  ← SRAM SO
  D13 = SCK   → SRAM SCK + 74HC595 SRCLK

Floppy (suorat GPIO):
  D6  = 74HC595 RCLK (latch)
  D7  = /WDATA (tarvitsee suora GPIO tarkan ajoituksen takia)
  D8  = /RDATA (ICP1 input capture)
  D9  = vapaa / LED

Floppy input:
  A0  = /TRK00 (input pullup)
  A1  = /WPT   (input pullup)
  A2  = /DSKCHG (input pullup)

Vapaat:
  A3-A5 = vapaat (debug, LED, jne.)
  D0-D1 = Serial (USB debug)
```

## Firmware-rakenne

```
┌──────────────────────────────────────┐
│        Arduino Nano Firmware         │
│        + 23LC512 SRAM               │
├──────────────────────────────────────┤
│  SPI SRAM -ajuri                     │
│  (sram_read, sram_write, sram_seq)   │
├──────────────────────────────────────┤
│  IEC-protokolla                      │
│  (INT0 ATN, bit-bang CLK/DATA)       │
├──────────────────────────────────────┤
│  Floppy-ohjaus                       │
│  (74HC595 output, ICP1 MFM-luku)    │
├──────────────────────────────────────┤
│  MFM decode/encode                   │
│  (ICP1 → SRAM raitapuskuri)          │
├──────────────────────────────────────┤
│  FAT12 (SRAM-pohjaisella cachella)   │
│  (koko FAT mahtuu SRAM:iin!)         │
├──────────────────────────────────────┤
│  CBM-DOS emulaatio                   │
│  (LOAD, SAVE, $, S:, R:, N:)        │
└──────────────────────────────────────┘

RAM-käyttö:
  Nano 2KB:  pino, SPI-puskuri, tilakone, välimuuttujat
  SRAM 64KB: raitapuskuri, FAT-cache, sektorit, hakemisto, LZ4-puskurit
```

### SPI SRAM -käyttö (23LC256)

```c
// 23LC256 SPI komennot (samat kuin 23LC1024)
#define SRAM_READ   0x03   // Lue data
#define SRAM_WRITE  0x02   // Kirjoita data
#define SRAM_RDMR   0x05   // Lue mode register
#define SRAM_WRMR   0x01   // Kirjoita mode register

// Mode: Sequential (oletusarvo, paras suorituskyky)
// Osoite kasvaa automaattisesti → voi lukea/kirjoittaa
// pitkiä lohkoja yhdellä SPI-transaktiolla.

// 23LC256 käyttää 16-bit osoitteita (vs. 23LC1024:n 24-bit)
void sram_read(uint32_t addr, uint8_t *buf, uint16_t len) {
    digitalWrite(CS_SRAM, LOW);
    SPI.transfer(SRAM_READ);
    SPI.transfer((addr >> 8) & 0xFF);
    SPI.transfer(addr & 0xFF);
    for (uint16_t i = 0; i < len; i++) {
        buf[i] = SPI.transfer(0x00);
    }
    digitalWrite(CS_SRAM, HIGH);
}

void sram_write(uint32_t addr, const uint8_t *buf, uint16_t len) {
    digitalWrite(CS_SRAM, LOW);
    SPI.transfer(SRAM_WRITE);
    SPI.transfer((addr >> 8) & 0xFF);
    SPI.transfer(addr & 0xFF);
    for (uint16_t i = 0; i < len; i++) {
        SPI.transfer(buf[i]);
    }
    digitalWrite(CS_SRAM, HIGH);
}
```

### MFM-luku SRAM-puskurilla

```
Ero vaihtoehtoon D:

Vaihtoehto D (ilman SRAM):
  - MFM dekoodataan lennosta, sektori kerrallaan
  - Jos oikea sektori ohitetaan, pitää odottaa koko kierros (~200ms)
  - Hidas ja epäluotettava

Vaihtoehto E (SRAM:lla):
  - Koko raita luetaan SRAM:iin (~12.5 KB)
  - Dekoodataan rauhassa SRAM:sta
  - Kaikki 18 sektoria saatavilla heti
  - Useampi sektori samalta raidalta = vain yksi luku

  Timer1 ICP ISR kirjoittaa suoraan SRAM:iin:
    ISR(TIMER1_CAPT_vect) {
        uint16_t interval = ICR1 - last_capture;
        last_capture = ICR1;
        // Kirjoita SRAM:iin (SPI single byte, nopea)
        sram_write_byte(track_write_ptr++, classify_pulse(interval));
    }
```

## Plussat

- **Ei tasonmuuntimia** — 5V natiivi (Nano + 23LC256 + floppy)
- **Riittävästi muistia** — 32 KB SRAM ratkaisee Nanon 2 KB rajoituksen
- Koko FAT-taulu mahtuu SRAM:iin → nopea tiedostohaku
- Raitapuskuri mahdollinen → luotettavampi MFM-dekoodaus
- Edullinen (~10-13€)
- Yksinkertaisempi kuin Pico-ratkaisu (ei tasonmuuntimia)

## Miinukset

- SPI SRAM lisää latenssia (~50µs per 512B sektoriluku SRAM:sta)
- 74HC595 shift register lisää yhden komponentin
- Floppy-signaalien ohjaus shift registerin kautta hieman hitaampaa
- Edelleen single-core — IEC ja floppy eivät voi toimia rinnakkain
- /WDATA tarvitsee suoran GPIO:n tarkan MFM-ajoituksen takia
- 32 KB Flash voi olla tiukka kaikelle firmwarelle
- SPI-väylän jakaminen SRAM:n ja 74HC595:n kesken vaatii huolellista CS-hallintaa

## Vertailu vaihtoehtoihin D ja A

```
┌──────────────────┬───────────────┬───────────────┬───────────────┐
│ Ominaisuus       │ D: Nano       │ E: Nano+SRAM  │ A: Pico       │
├──────────────────┼───────────────┼───────────────┼───────────────┤
│ RAM              │ 2 KB (!)      │ 2+64 KB       │ 264 KB        │
│ Tasonmuuntimet   │ 0 kpl         │ 0 kpl         │ 4x BSS138     │
│ Komponentteja    │ 7             │ 9 (+SRAM,595) │ 12            │
│ Hinta            │ ~8€           │ ~10-13€       │ ~12€          │
│ Raitapuskuri     │ Ei mahdu      │ Mahtuu (SRAM) │ Mahtuu (RAM)  │
│ FAT-cache        │ Osittainen    │ Kokonainen    │ Kokonainen    │
│ MFM-luotettavuus │ Heikko        │ Hyvä          │ Erinomainen   │
│ Kehitysnopeus    │ Hidas         │ Keskiverto    │ Nopea         │
│ Kytkennän helppous│ Helpoin      │ Helppo        │ Keskiverto    │
└──────────────────┴───────────────┴───────────────┴───────────────┘
```

## Toteutusvaiheet

1. SPI SRAM -ajurin toteutus ja testaus (read/write/sequential)
2. 74HC595 shift register floppy-outputille
3. IEC-protokolla (sama kuin vaihtoehto D)
4. MFM-luku Timer1 ICP:llä → SRAM-raitapuskuri
5. MFM-dekoodaus SRAM:sta
6. FAT12 SRAM-pohjaisella cachella
7. CBM-DOS (LOAD, SAVE, $)
8. MFM-kirjoitus (SRAM → floppy)
9. PCB-suunnittelu
10. Testaus ja viimeistely

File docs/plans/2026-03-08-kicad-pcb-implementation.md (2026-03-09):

# KiCad PCB — Vaihtoehto E Implementation Plan

> **For Claude:** REQUIRED SUB-SKILL: Use superpowers:executing-plans to implement this plan task-by-task.

**Goal:** Generate a complete KiCad 8 project for vaihtoehto E (Arduino Nano + 23LC256 + 74HC595) PCB, ready for Freerouting autorouting and Gerber export.

**Architecture:** Three KiCad files generated as S-expressions/JSON: `.kicad_pro` (project config), `.kicad_sch` (schematic with all symbols, wires, and nets), `.kicad_pcb` (board outline, footprint placement, net assignments, GND zone). A custom DIN-6 footprint is created since KiCad's standard library lacks one. Tracks are left to Freerouting.

**Tech Stack:** KiCad 8 file formats (S-expression for .sch/.pcb, JSON for .pro), standard KiCad libraries, custom footprint for DIN-6.

**Reference:** `docs/plans/2026-03-08-kicad-pcb-design.md` and `docs/E-IEC-Nano-SRAM/piirikaavio.md`

---

### Task 1: Create project directory and .kicad_pro

**Files:**
- Create: `hardware/E-IEC-Nano-SRAM/64korppu-E.kicad_pro`

**Step 1: Create directory**

```bash
mkdir -p hardware/E-IEC-Nano-SRAM
```

**Step 2: Write .kicad_pro file**

JSON project file with default KiCad 8 settings. Key sections: board design_settings (trace width 0.25mm, clearance 0.2mm, via size 0.6mm/0.3mm drill), 2-layer stackup, net classes.

**Step 3: Verify valid JSON**

```bash
python3 -c "import json; json.load(open('hardware/E-IEC-Nano-SRAM/64korppu-E.kicad_pro'))"
```
Expected: No error.

**Step 4: Commit**

```bash
git add hardware/E-IEC-Nano-SRAM/64korppu-E.kicad_pro
git commit -m "feat(hw): add KiCad project file for option E"
```

---

### Task 2: Create custom DIN-6 footprint

**Files:**
- Create: `hardware/E-IEC-Nano-SRAM/64korppu-E.pretty/DIN-6_IEC_Vertical.kicad_mod`

KiCad standard library has no DIN-6 connector footprint.
Create one based on standard DIN-6 pin circular layout:
- 6 through-hole pins on 7mm diameter circle (262° arc, 45° apart)
- Pin numbering per DIN standard: 1(bottom-left), 2(bottom-right), 3(top-right), 4(top-left), 5(center-right), 6(center-left)
- Shield/mounting pins at ±6mm
- Courtyard and silkscreen outline

**Step 1: Create footprint library directory**

```bash
mkdir -p hardware/E-IEC-Nano-SRAM/64korppu-E.pretty
```

**Step 2: Write .kicad_mod footprint file**

S-expression footprint with:
- 6 THT pads (1.5mm drill, 2.0mm pad) at DIN-6 standard positions
- 2 mounting/shield pads at ±6mm
- Silkscreen circle and pin 1 marker
- Fab layer outline
- Courtyard (15mm × 15mm)

**Step 3: Verify S-expression syntax**

```bash
python3 -c "
with open('hardware/E-IEC-Nano-SRAM/64korppu-E.pretty/DIN-6_IEC_Vertical.kicad_mod') as f:
    content = f.read()
    assert content.startswith('(footprint'), 'Not a valid footprint file'
    assert content.count('(pad') == 8, 'Expected 8 pads (6 signal + 2 shield)'
print('OK')
"
```

**Step 4: Commit**

```bash
git add hardware/E-IEC-Nano-SRAM/64korppu-E.pretty/
git commit -m "feat(hw): add custom DIN-6 IEC footprint"
```

---

### Task 3: Create schematic — lib_symbols section

**Files:**
- Create: `hardware/E-IEC-Nano-SRAM/64korppu-E.kicad_sch`

The schematic requires embedded copies of all library symbols used.
This task creates the file with header and all lib_symbols.

**Symbols needed:**

| Ref | Symbol | Pins |
|-----|---|---|
| U1 | Arduino Nano module | 30 pins (2×15 headers: D0-D13, A0-A7, VIN, GND, RST, 5V, 3V3, AREF) |
| U2 | 23LC256 (generic 8-pin SPI SRAM) | 8 pins: /CS, SO, NC, VSS, SI, SCK, /HOLD, VCC |
| U3 | 74HC595 | 16 pins: QB,QC,QD,QE,QF,QG,QH,GND,QH',SRCLK,RCLK,/OE,SER,QA,/CLR,VCC |
| J1 | DIN-6 connector | 6 pins |
| J2 | 2×17 IDC header | 34 pins |
| J3 | Barrel jack | 3 pins (tip, ring, sleeve) |
| R1-R12 | Resistor | 2 pins |
| C1-C3 | Capacitor | 2 pins |
| C4 | Capacitor polarized | 2 pins |
| D1 | LED | 2 pins (A, K) |

Use standard KiCad lib symbols for all except Arduino Nano (custom symbol with 2×15 pin headers) and 23LC256 (custom 8-pin IC).

**Step 1: Write schematic header and lib_symbols**

Create file with:
- `(version 20231120)` header
- `(paper "A3")` — larger paper for readable schematic
- All symbol definitions embedded in `(lib_symbols ...)`
- No placed components yet (those come in Task 4)

**Step 2: Verify S-expression syntax**

```bash
python3 -c "
with open('hardware/E-IEC-Nano-SRAM/64korppu-E.kicad_sch') as f:
    content = f.read()
    assert '(kicad_sch' in content
    assert '(lib_symbols' in content
print('Symbols:', content.count('(symbol \"'))
"
```

**Step 3: Commit**

```bash
git add hardware/E-IEC-Nano-SRAM/64korppu-E.kicad_sch
git commit -m "feat(hw): add schematic with library symbols"
```

---

### Task 4: Place components and wire schematic

**Files:**
- Modify: `hardware/E-IEC-Nano-SRAM/64korppu-E.kicad_sch`

Place all component instances and draw wires.
Use the netlist from `docs/plans/2026-03-08-kicad-pcb-design.md`.

**Layout on schematic sheet (A3, coordinates in mm):**

```
  Left side (x=30):    Center (x=130):     Right side (x=230):
  J1 DIN-6 (IEC)       U1 Arduino Nano     J2 34-pin IDC (floppy)
  R1-R4 (1k series)    U2 23LC256          R9-R12 (10k pull-ups)
  R5-R7 (4.7k pullup)  U3 74HC595

  Top center (x=130, y=30):
  J3 DC jack
  C4 bulk cap

  Bottom (y=200):
  C1-C3 bypass caps
  D1 LED + R8
```

**Step 1: Add all symbol instances with positions**

Each symbol block includes:
- `(lib_id ...)`, `(at x y angle)`, `(uuid ...)`
- Properties: Reference, Value, Footprint
- Pin UUIDs for wire connections

**Step 2: Add power symbols**

Place `+5V` and `GND` power symbols at all power connections.

**Step 3: Draw all wires**

Connect pins per netlist using `(wire (pts (xy x1 y1) (xy x2 y2)))`.
Use `(junction ...)` where wires cross/join.

Add `(net_label ...)` for named nets: SPI_MOSI, SPI_MISO, SPI_SCK,
IEC_ATN, IEC_CLK, IEC_DATA, IEC_RESET, LATCH_595, etc.

**Step 4: Add sheet_instances footer**

```
(sheet_instances (path "/" (page "1")))
```

**Step 5: Verify**

```bash
python3 -c "
with open('hardware/E-IEC-Nano-SRAM/64korppu-E.kicad_sch') as f:
    content = f.read()
    # Count placed symbols (not lib_symbols definitions)
    import re
    placed = len(re.findall(r'\(symbol \(lib_id', content))
    print(f'Placed components: {placed}')
    assert placed >= 20, f'Expected >=20 placed components, got {placed}'
    wires = content.count('(wire')
    print(f'Wires: {wires}')
    assert wires >= 30, f'Expected >=30 wires, got {wires}'
print('OK')
"
```

**Step 6: Commit**

```bash
git add hardware/E-IEC-Nano-SRAM/64korppu-E.kicad_sch
git commit -m "feat(hw): complete schematic with all components and wiring"
```

---

### Task 5: Create PCB — board outline and footprints

**Files:**
- Create: `hardware/E-IEC-Nano-SRAM/64korppu-E.kicad_pcb`

**Step 1: Write PCB header**

- `(version 20240108)`, 2-layer setup (F.Cu + B.Cu)
- Board thickness 1.6mm
- All standard layers

**Step 2: Define nets**

All nets from schematic:
```
(net 0 "")
(net 1 "GND")
(net 2 "+5V")
(net 3 "SPI_MOSI")
(net 4 "SPI_MISO")
(net 5 "SPI_SCK")
(net 6 "SPI_CS_SRAM")
(net 7 "LATCH_595")
(net 8 "IEC_ATN")
(net 9 "IEC_CLK")
(net 10 "IEC_DATA")
(net 11 "IEC_RESET")
(net 12 "FLOPPY_WDATA")
(net 13 "FLOPPY_RDATA")
(net 14 "FLOPPY_TRK00")
(net 15 "FLOPPY_WPT")
(net 16 "FLOPPY_DSKCHG")
(net 17 "FLOPPY_DENSITY")
(net 18 "FLOPPY_MOTEA")
(net 19 "FLOPPY_DRVSEL")
(net 20 "FLOPPY_MOTOR")
(net 21 "FLOPPY_DIR")
(net 22 "FLOPPY_STEP")
(net 23 "FLOPPY_WGATE")
(net 24 "FLOPPY_SIDE1")
(net 25 "LED_ANODE")
... (resistor intermediate nets)
```

**Step 3: Draw board outline**

85mm × 55mm rectangle on Edge.Cuts, origin at (100, 100):
```
(gr_rect (start 100 100) (end 185 155)
  (stroke (width 0.05) (type solid))
  (fill none) (layer "Edge.Cuts"))
```

Add 4 mounting holes: M3 (3.2mm drill) at corners, 3mm inset.

**Step 4: Place footprints**

Coordinates based on design doc layout (origin 100,100):

| Ref | Footprint | Position (mm) | Notes |
|-----|---|---|---|
| J3 | BarrelJack_Horizontal | (130, 102) | Top center |
| J1 | DIN-6_IEC_Vertical (custom) | (105, 125) | Left side |
| J2 | IDC-Header_2x17_P2.54mm_Vertical | (175, 125) | Right side |
| U1 | PinHeader_2x15_P2.54mm_Vertical | (142, 125) | Center |
| U2 | DIP-8_W7.62mm_Socket | (118, 135) | Left of Nano |
| U3 | DIP-16_W7.62mm_Socket | (142, 145) | Below Nano |
| R1-R4 | R_Axial P10.16mm | (110, 115) stacked | Near J1 |
| R5-R7 | R_Axial P10.16mm | (110, 120) stacked | Near J1 |
| R8 | R_Axial P10.16mm | (115, 150) | Near LED |
| R9-R12 | R_Axial P10.16mm | (168, 135) stacked | Near J2 |
| C1-C3 | C_Disc_D5.0mm | near each IC | Bypass |
| C4 | CP_Radial_D5.0mm | (138, 103) | Near J3 |
| D1 | LED_D3.0mm | (112, 150) | Bottom left |
| H1-H4 | MountingHole_3.2mm | corners | 3mm inset |

Each footprint includes all pads with net assignments.

**Step 5: Add GND zone on B.Cu**

```
(zone (net 1) (net_name "GND") (layer "B.Cu")
  (hatch edge 0.5)
  (connect_pads (clearance 0.3))
  (min_thickness 0.25)
  (fill (thermal_gap 0.5) (thermal_bridge_width 0.5))
  (polygon (pts
    (xy 100 100) (xy 185 100) (xy 185 155) (xy 100 155)
  ))
)
```

**Step 6: Verify**

```bash
python3 -c "
with open('hardware/E-IEC-Nano-SRAM/64korppu-E.kicad_pcb') as f:
    content = f.read()
    assert '(kicad_pcb' in content
    footprints = content.count('(footprint ')
    nets = content.count('(net ')
    print(f'Footprints: {footprints}, Nets: {nets}')
    assert footprints >= 20
    assert 'Edge.Cuts' in content
print('OK')
"
```

**Step 7: Commit**

```bash
git add hardware/E-IEC-Nano-SRAM/64korppu-E.kicad_pcb
git commit -m "feat(hw): add PCB with footprint placement and GND zone"
```

---

### Task 6: Add fp-lib-table for custom footprint library

**Files:**
- Create: `hardware/E-IEC-Nano-SRAM/fp-lib-table`

KiCad needs to know where to find the custom DIN-6 footprint.

**Step 1: Write fp-lib-table**

```
(fp_lib_table
  (version 7)
  (lib (name "64korppu-E")(type "KiCad")(uri "${KIPRJMOD}/64korppu-E.pretty")(options "")(descr "64korppu project footprints"))
)
```

**Step 2: Commit**

```bash
git add hardware/E-IEC-Nano-SRAM/fp-lib-table
git commit -m "feat(hw): add footprint library table for custom DIN-6"
```

---

### Task 7: Add hardware README and Freerouting instructions

**Files:**
- Create: `hardware/README.md`

**Step 1: Write README**

Document:
- Directory structure
- How to open in KiCad 8
- How to export .dsn for Freerouting
- How to import .ses back
- How to export Gerbers for JLCPCB/PCBWay

**Step 2: Commit**

```bash
git add hardware/README.md
git commit -m "docs: add hardware README with Freerouting and Gerber instructions"
```

---

### Task 8: Final verification and commit

**Step 1: Verify all files present**

```bash
ls -la hardware/E-IEC-Nano-SRAM/
# Expected:
#   64korppu-E.kicad_pro
#   64korppu-E.kicad_sch
#   64korppu-E.kicad_pcb
#   64korppu-E.pretty/DIN-6_IEC_Vertical.kicad_mod
#   fp-lib-table
```

**Step 2: Try KiCad CLI validation (if installed)**

```bash
kicad-cli sch erc --severity-all --exit-code-violations \
  hardware/E-IEC-Nano-SRAM/64korppu-E.kicad_sch || echo "ERC issues found (expected for generated schematic)"

kicad-cli pcb drc --severity-all --exit-code-violations \
  hardware/E-IEC-Nano-SRAM/64korppu-E.kicad_pcb || echo "DRC issues found (expected, no tracks yet)"
```

**Step 3: Final commit if any fixes**

```bash
git add hardware/
git commit -m "feat(hw): complete KiCad project for option E PCB"
```

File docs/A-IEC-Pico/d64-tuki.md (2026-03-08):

# D64 Disk Image -tuki

## Yleiskuvaus

64korppu tukee D64 disk image -tiedostoja. PC:llä kopioidaan `.D64`-tiedosto FAT12-levylle,
ja firmware "mounttaa" sen RAM-puskuriin. Tämän jälkeen D64:n sisältämät tiedostot
ovat käytettävissä normaalisti IEC-väylän kautta.

Tämä mahdollistaa valtavan C64-ohjelmakirjaston käytön: netistä ladattu `.D64`-image
kopioidaan FAT12-korppulevylle, ja C64 lataa suoraan.

## D64-formaatti

Standardi 1541 disk image (35 raitaa):
- 174 848 tavua (683 sektoria × 256 tavua)
- Raidat 1–17: 21 sektoria/raita
- Raidat 18–24: 19 sektoria/raita
- Raidat 25–30: 18 sektoria/raita
- Raidat 31–35: 17 sektoria/raita

Raita 18, sektori 0 = BAM (Block Availability Map) + levyn nimi.
Raita 18, sektori 1+ = Hakemisto (linkitetty lista, 8 merkintää/sektori).

## Käyttöohjeet

### Levyn valmistelu PC:llä

1. Lataa haluamasi `.D64`-tiedosto (esim. `game.d64`)
2. Kopioi FAT12-levylle: `copy game.d64 A:`

### C64-käyttö

```
LOAD "$",8                     — näyttää FAT12-hakemiston (.D64-tiedostot näkyvissä)
OPEN 15,8,15,"CD:GAME.D64"    — mounttaa D64-image (lataa RAM:iin)
LOAD "$",8                     — näyttää D64:n sisäisen hakemiston
LOAD "PELI",8                  — lataa PRG D64:n sisältä
SAVE "OMA.PRG",8               — tallentaa D64-imageen
OPEN 15,8,15,"S:VANHA"        — poistaa tiedoston D64-imagesta
OPEN 15,8,15,"CD:.."           — palaa FAT12-juureen (flush + unmount)
```

### CD-komennon syntaksi

| Komento | Toiminto |
|---|---|
| `CD:GAME.D64` | Mounttaa D64-image |
| `CD:..` | Unmounttaa D64 ja palaa FAT12-juureen |

Komento lähetetään komentokanavalle (SA 15), kuten SD2IEC:ssä ja muissa
moderneissa C64-levyasemaemulaattoreissa.

## Kirjoitustuki (write-back)

Kun D64 on mountattu ja käyttäjä tekee SAVE:n tai muun kirjoitusoperaation:
1. Kirjoitus kohdistuu RAM-puskuriin (nopea)
2. Unmount-hetkellä (`CD:..`) muutokset kirjoitetaan takaisin FAT12-levylle
3. Koko D64-puskuri (174 KB) kirjoitetaan kerralla (~5 s)
4. PC näkee päivitetyn `.D64`-tiedoston normaalisti

## RAM-käyttö

| Komponentti | Koko |
|---|---|
| Pico SRAM yhteensä | 264 KB |
| Firmware (arvio) | ~30–35 KB |
| D64-puskuri | ~171 KB |
| Jäljellä | ~58–63 KB |

## Toteutus

### Firmware-moduulit

| Tiedosto | Rooli |
|---|---|
| `firmware/include/d64.h` | D64-tietorakenteet, julkinen API |
| `firmware/src/d64.c` | D64-parsinta, mount/flush/unmount, BAM-hallinta, tiedosto-I/O |
| `firmware/src/cbm_dos.c` | `d64_mode`-haarautuminen, CD:-komento, D64-moodi LOAD/SAVE:lle |

### Toimintaperiaate

1. **Mount** (`d64_mount`): lukee koko 174 848 tavun D64-imagen FAT12-levyltä Picon RAM-puskuriin 512 tavun paloissa
2. **Luku/kirjoitus**: kaikki D64-operaatiot kohdistuvat suoraan RAM-puskuriin — ei levyhakuja, erittäin nopea
3. **Hakemisto**: parsii raita 18:n linkitetyn hakemistolistan, muuntaa CBM BASIC -listaukseksi
4. **T/S-ketjut**: seuraa track/sector-ketjua lohko kerrallaan (tavu 0–1 = seuraava T/S, tavut 2–255 = data)
5. **BAM**: allokoi/vapauttaa lohkoja suoraan BAM-sektorista (raita 18, sektori 0)
6. **Flush** (`d64_flush`): kirjoittaa koko RAM-puskurin takaisin FAT12-tiedostoksi 512 tavun paloissa
7. **CBM-DOS-integraatio**: `cbm_dos.c`:n `d64_mode`-lippu ohjaa kaikki LOAD/SAVE/$/S:-operaatiot D64-moduulille

### Hakemistolistauksen muoto

D64-moodissa `LOAD "$",8` tuottaa:
```
0 "LEVYN NIMI      " 64 D64
23   "OHJELMA"         PRG
5    "DATA"            SEQ
640 BLOCKS FREE.
```

Otsikkorivillä näkyy D64:n levynimi ja "64 D64" -tunniste (vrt. FAT12-moodissa "64 FAT").

## Rajoitukset

- **Vain 35-track** — standardi D64 (174 848 tavua), ei 40-track extended
- **Vain Pico (vaihtoehto A)** — Nano-variantit eivät pysty (RAM ei riitä)
- **Yksi D64 kerrallaan** — vain yksi mountattu image
- **Flush on hidas** — koko 174 KB kirjoitetaan levylle unmountissa (~5 s)
- **Tuetut tiedostotyypit** — PRG, SEQ, USR, REL (hakemistossa näkyvät kaikki)

## Testaus

D64-moduulille on kattavat host-testit (ei tarvita Pico-laitteistoa):

```bash
cd test
make test          # 27 yksikkötestiä (mount, dir, read, write, delete, BAM, flush)
make               # kääntää myös IEC bridge -integraatiotestin
```

Katso [test/vice/README.md](../../test/vice/README.md) IEC bridge -integraatiotestauksesta.

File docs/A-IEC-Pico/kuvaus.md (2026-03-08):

# Vaihtoehto A: IEC-väylä + Raspberry Pi Pico (Suositeltu)

## Arkkitehtuuri

```
C64 ──[IEC-sarjaväylä]──> Raspberry Pi Pico ──[34-pin]──> PC 3.5" HD floppy
```

## Toimintaperiaate

- Pico emuloi CBM-levyasemaa (device #8-11) IEC-sarjaväylällä
- Pico ohjaa PC-korppuasemaa suoraan 34-pin Shugart-liitännän kautta
- Pico hoitaa FAT12-tiedostojärjestelmän tulkinnan
- C64:lle ei tarvita ROM-muutoksia peruskäytössä

## Komponenttilista

| Komponentti | Kuvaus | Hinta (arvio) |
|---|---|---|
| Raspberry Pi Pico | RP2040 MCU, 264KB RAM, 2x PIO | ~5€ |
| 74LVC245 x2 | Tasonmuunnin 3.3V ↔ 5V (IEC-väylä) | ~1€ |
| 6-pin DIN -liitin | IEC-väylä C64:lle | ~2€ |
| 34-pin IDC -liitin | PC-floppy -liitäntä | ~1€ |
| 4-pin Molex/Berg | Virta floppy-asemalle | ~1€ |
| Jänniteregulaattori | 5V → 3.3V (jos Picoa syötetään 5V:sta) | ~1€ |
| Vastukset, kondensaattorit | Pull-upit, suodatus | ~1€ |
| **Yhteensä** | | **~12€** |

## PCB-vaatimukset

### Kytkennät

#### IEC-väylä (6-pin DIN → Pico, 74LVC245:n kautta)

| IEC-pin | Signaali | Pico GPIO | Suunta |
|---|---|---|---|
| 1 | SRQ (ei käytetä) | - | - |
| 2 | GND | GND | - |
| 3 | ATN | GP2 | Bidirectional |
| 4 | CLK | GP3 | Bidirectional |
| 5 | DATA | GP4 | Bidirectional |
| 6 | RESET | GP5 | Input |

**Huom:** IEC-signaalit ovat open collector -tyyppisiä. 74LVC245 tasonmuuntimen lisäksi tarvitaan open-drain -konfiguraatio tai erillinen ohjauslogiikka.

#### Floppy-asema (34-pin IDC → Pico)

| 34-pin | Signaali | Pico GPIO | Suunta |
|---|---|---|---|
| 2 | /DENSITY | GP6 | Output (HIGH=HD) |
| 10 | /MOTEA | GP7 | Output |
| 12 | /DRVSB | GP8 | Output (Drive Select B) |
| 16 | /MOTOR | GP9 | Output |
| 18 | /DIR | GP10 | Output |
| 20 | /STEP | GP11 | Output |
| 22 | /WDATA | GP12 | Output |
| 24 | /WGATE | GP13 | Output |
| 26 | /TRK00 | GP14 | Input |
| 28 | /WPT | GP15 | Input |
| 30 | /RDATA | GP16 | Input |
| 32 | /SIDE1 | GP17 | Output |
| 34 | /DSKCHG | GP18 | Input |
| Parittomat | GND | GND | - |

## Firmware-rakenne

```
┌─────────────────────────────────┐
│         Pico Firmware           │
├────────────┬────────────────────┤
│  Core 0    │     Core 1         │
│  IEC-proto │  Floppy-ohjaus     │
│  FAT12 FS  │  MFM encode/decode │
│  Komennot  │  Track seek/read   │
├────────────┴────────────────────┤
│  Jaettu puskuri (track data)    │
└─────────────────────────────────┘
```

### Moduulit

1. **iec_protocol** - ATN, CLK, DATA -signaalien käsittely PIO:lla, laite-emulaatio
2. **floppy_ctrl** - moottori, step, head select, read/write gate
3. **mfm_codec** - MFM-koodaus/dekoodaus PIO:lla
4. **fat12** - FAT-taulun, hakemiston ja tiedostojen käsittely
5. **cbm_dos** - CBM-DOS -emulaatio (LOAD, SAVE, OPEN, $, S:, R:, N:)

## Plussat

- Ei vaadi C64:n modifiointia
- Toimii kaiken C64-ohjelmiston kanssa (LOAD/SAVE)
- Yksinkertaisin PCB-suunnittelu
- Pico on edullinen ja helposti saatavilla
- PIO mahdollistaa tarkan ajoituksen sekä IEC- että floppy-protokollille
- Dual-core: IEC ja floppy-ohjaus rinnakkain

## Miinukset

- IEC-väylä on hidas (~1-3 KB/s vakiona, ~5-10 KB/s JiffyDOS:lla)
- FAT12 8.3-tiedostonimet vs. CBM 16-merkkiset nimet (tarvitaan nimeämiskäytäntö)

## Toteutusvaiheet

1. Floppy-aseman perusohjaus Picolla (moottori, seek, luku)
2. MFM-dekoodaus ja sektorien luku
3. FAT12-tiedostojärjestelmän tulkinta
4. IEC-protokollan toteutus PIO:lla
5. CBM-DOS -emulaatio
6. LOAD/SAVE/$ -komennot
7. PCB-suunnittelu KiCadilla
8. Testaus ja viimeistely

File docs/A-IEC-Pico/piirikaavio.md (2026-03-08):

================================================================================
  VAIHTOEHTO A: IEC-väylä + Raspberry Pi Pico — PIIRIKAAVIO
================================================================================

                          VIRTALÄHDE
  ┌─────────────────────────────────────────────────────────────┐
  │                                                             │
  │   Ulkoinen 5V/2A                                            │
  │   virtalähde                                                │
  │   ┌─────────┐     ┌──────────────────────┐                  │
  │   │  DC 5V  ├──┬──┤ VBUS (pin 40)  Pico  │                  │
  │   │  Jack   │  │  └──────────────────────┘                  │
  │   └────┬────┘  │                                            │
  │        │       ├──── +5V ──> Floppy-asema (pin 4)           │
  │        │       ├──── +5V ──> 74LVC245 VCC_B (IEC-puoli)     │
  │        │       │                                            │
  │       GND     GND                                           │
  │                                                             │
  │   Pico 3V3(OUT) ──> 74LVC245 VCC_A (Pico-puoli)            │
  │                                                             │
  └─────────────────────────────────────────────────────────────┘

================================================================================
  IEC-VÄYLÄ (C64 ↔ 74LVC245 ↔ Pico)
================================================================================

  IEC-väylä on open-collector: laitteet voivat vain vetää linjaa LOW.
  Käytetään MOSFET-pohjaista tasonmuunninta bidirektionaaliseen ohjaukseen.

           C64                                              Raspberry Pi Pico
     6-pin DIN-liitin                                       (3.3V logiikka)
    ┌──────────────┐                                       ┌─────────────────┐
    │              │                                       │                 │
    │  Pin 3: ATN  ├───┐                                   │                 │
    │              │   │    Bidirectional Level Shifter     │                 │
    │  Pin 4: CLK  ├───┤     (MOSFET-pohjainen, 4 ch)      │                 │
    │              │   │   ┌────────────────────────┐      │                 │
    │  Pin 5: DATA ├───┤   │  5V          3.3V      │      │                 │
    │              │   │   │  puoli       puoli     │      │                 │
    │  Pin 6: RESET├───┤   │                        │      │                 │
    │              │   │   │                        │      │                 │
    │  Pin 2: GND  ├───┤   │  GND    OE   VCC_A/B  │      │                 │
    │              │   │   └────────────────────────┘      │                 │
    │  Pin 1: SRQ  │   │                                   │                 │
    │  (ei käytetä)│   │                                   │                 │
    └──────────────┘   │                                   └─────────────────┘
                       │
                       │
  Yksityiskohtainen kytkentä per signaali (open-drain MOSFET level shifter):

  Kukin IEC-signaali (ATN, CLK, DATA) kytketään näin:

         5V                           3.3V
          │                            │
          ├─── R1 (10kΩ)               ├─── R2 (10kΩ)
          │    │                       │    │
  IEC ────┼────┤                       ├────┼──── Pico GPIO
  pin     │    │      BSS138           │    │     (open-drain mode)
          │    ├──────┤G   D├──────────┤    │
          │    │      │     │          │    │
          │    │      │  S  │          │    │
          │    │      └──┬──┘          │    │
          │    │         │             │    │
         GND  GND       GND          GND  GND

  MOSFET-level shifter -piiri (BSS138) jokaiselle IEC-signaalille:
  ═══════════════════════════════════════════════════════════════

                    5V puoli                     3.3V puoli
                   ┌────────────────────────────────────────┐
                   │                                        │
      R1 10kΩ      │     BSS138 (N-ch MOSFET)    R2 10kΩ   │
  5V──┤├──┬────────┼──G              D──┬────────┼──┤├──3V3 │
          │        │                    │        │          │
  IEC ────┘        │     S              │        └──── Pico │
  signaali         │     │              │           GPIO    │
                   │    GND             │                   │
                   └────────────────────────────────────────┘

  Toiminta:
  - Pico vetää GPIO LOW → MOSFET johtaa → IEC-linja menee LOW (5V-puolella)
  - C64 vetää IEC LOW → MOSFET johtaa → Pico GPIO menee LOW (3.3V-puolella)
  - Molemmat HIGH → pull-upit pitävät linjat ylhäällä

  Tarvitaan 4 kpl BSS138 + 4x R1 (10kΩ) + 4x R2 (10kΩ):
  - ATN   (IEC pin 3 ↔ GP2)
  - CLK   (IEC pin 4 ↔ GP3)
  - DATA  (IEC pin 5 ↔ GP4)
  - RESET (IEC pin 6 ↔ GP5) — vain input, mutta sama piiri toimii

  Kokonainen IEC-liitäntä:
  ════════════════════════

               6-pin DIN                BSS138 x4              Pico
            ┌────────────┐          ┌──────────────┐     ┌──────────────┐
            │            │          │   5V    3V3   │     │              │
            │ 1 SRQ  n/c │          │    │     │    │     │              │
            │            │   10kΩ   │   R1    R2   │     │              │
            │ 3 ATN ─────┼────┤├──┬─┤─G    D──┬─┤├─┼─────┤ GP2  ATN    │
            │            │        │ │  BSS138  │   │     │              │
            │ 4 CLK ─────┼────┤├──┬─┤─G    D──┬─┤├─┼─────┤ GP3  CLK    │
            │            │        │ │  BSS138  │   │     │              │
            │ 5 DATA ────┼────┤├──┬─┤─G    D──┬─┤├─┼─────┤ GP4  DATA   │
            │            │        │ │  BSS138  │   │     │              │
            │ 6 RESET ───┼────┤├──┬─┤─G    D──┬─┤├─┼─────┤ GP5  RESET  │
            │            │        │ │  BSS138  │   │     │              │
            │ 2 GND ─────┼────────┴─┤─S       │   │     │              │
            │            │         GND        GND  │     │              │
            └────────────┘          └──────────────┘     └──────────────┘

================================================================================
  FLOPPY-ASEMA (Pico ↔ 34-pin IDC)
================================================================================

  PC 3.5" HD floppy käyttää 34-pin IDC-liitäntää.
  Parittomat pinnit (1,3,5,...,33) ovat kaikki GND.
  Signaalit ovat active-low (invertoidut).
  Pico 3.3V GPIO:t voivat ohjata 5V floppy-logiikkaa suoraan
  (TTL-yhteensopiva: 3.3V > 2.0V = HIGH, OK).

         Raspberry Pi Pico                    34-pin IDC liitin
        ┌─────────────────┐                  ┌────────────────────────┐
        │                 │                  │                        │
        │ GP6  /DENSITY ──┼──────────────────┤  pin 2   /DENSITY     │
        │                 │                  │                        │
        │ GP7  /MOTEA ────┼──────────────────┤  pin 10  /MOTEA       │
        │                 │                  │  (Motor Enable A)      │
        │ GP8  /DRVSEL ───┼──────────────────┤  pin 12  /DRVSB       │
        │                 │                  │  (Drive Select B)      │
        │ GP9  /MOTOR ────┼──────────────────┤  pin 16  /MOTOR       │
        │                 │                  │  (Motor On)            │
        │ GP10 /DIR ──────┼──────────────────┤  pin 18  /DIR         │
        │                 │                  │  (Step Direction)      │
        │ GP11 /STEP ─────┼──────────────────┤  pin 20  /STEP        │
        │                 │                  │  (Step Pulse)          │
        │ GP12 /WDATA ────┼──────────────────┤  pin 22  /WDATA       │
        │                 │                  │  (Write Data)          │
        │ GP13 /WGATE ────┼──────────────────┤  pin 24  /WGATE       │
        │                 │                  │  (Write Gate)          │
        │                 │    ┌── 10kΩ──3V3 │                        │
        │ GP14 /TRK00 ────┼────┤─────────────┤  pin 26  /TRK00       │
        │                 │    │  (pull-up)   │  (Track 0 detect)     │
        │                 │    ┌── 10kΩ──3V3 │                        │
        │ GP15 /WPT ──────┼────┤─────────────┤  pin 28  /WPT         │
        │                 │    │  (pull-up)   │  (Write Protect)      │
        │                 │    ┌── 10kΩ──3V3 │                        │
        │ GP16 /RDATA ────┼────┤─────────────┤  pin 30  /RDATA       │
        │                 │    │  (pull-up)   │  (Read Data)          │
        │ GP17 /SIDE1 ────┼──────────────────┤  pin 32  /SIDE1       │
        │                 │                  │  (Head Select)         │
        │                 │    ┌── 10kΩ──3V3 │                        │
        │ GP18 /DSKCHG ───┼────┤─────────────┤  pin 34  /DSKCHG      │
        │                 │       (pull-up)  │  (Disk Change)        │
        │                 │                  │                        │
        │ GND ────────────┼──────────────────┤  pins 1,3,5,...,33    │
        │                 │                  │  (kaikki GND)          │
        └─────────────────┘                  └────────────────────────┘

  Floppy-aseman virtaliitäntä (4-pin Berg/Molex):
  ════════════════════════════════════════════════

        Ulkoinen 5V
        virtalähde             Floppy-asema
       ┌──────────┐           4-pin Berg
       │          │          ┌──────────┐
       │ +5V ─────┼──────────┤ pin 4 +5V│
       │          │          │ pin 3 GND│
       │ GND ─────┼──────────┤ pin 2 GND│
       │          │          │ pin 1 +12V│── ei kytketä (3.5" ei tarvitse)
       └──────────┘          └──────────┘

================================================================================
  RASPBERRY PI PICO — PINOUT
================================================================================
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

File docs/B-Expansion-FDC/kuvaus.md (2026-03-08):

# Vaihtoehto B: Expansion Port + FDC-piiri (Nopein)

## Arkkitehtuuri

```
C64 ──[Expansion port]──> PCB [FDC + logiikka] ──[34-pin]──> PC 3.5" HD floppy
```

## Toimintaperiaate

- FDC-piiri (esim. WD37C65 tai Intel 82077AA) ohjaa korppuasemaa
- FDC muistimapitetaan C64:n osoiteavaruuteen expansion portin kautta ($DExx/$DFxx)
- Custom ROM tai ladattava ajuri C64-puolella käsittelee FAT12:n ja tarjoaa LOAD/SAVE

## Komponenttilista

| Komponentti | Kuvaus | Hinta (arvio) |
|---|---|---|
| WD37C65 / 82077AA | Floppy Disk Controller | ~5-15€ (käytetty) |
| 74LS138 | Osoitedekooderi | ~1€ |
| 74LS245 x2 | Väylä buffer (data) | ~2€ |
| 74LS04 | Invertteriportit | ~1€ |
| 8KB EEPROM (28C64) | Custom ROM | ~3€ |
| 34-pin IDC -liitin | PC-floppy | ~1€ |
| 44-pin edge connector | Expansion port | ~3€ |
| Kide 16 MHz + 24 MHz | FDC:n kellotus | ~2€ |
| Vastukset, kondensaattorit | Pull-upit, suodatus | ~2€ |
| **Yhteensä** | | **~20-30€** |

## PCB-vaatimukset

### Osoitedekoodaus

FDC mapataan I/O-alueelle $DE00-$DE0F:

```
A15-A8 = $DE (1101 1110)
A7-A4  = $0  (0000)
A3-A0  → FDC:n rekisterivalinta

/IO1 (active low kun $DE00-$DEFF) + A7-A4 dekoodaus → FDC /CS
```
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

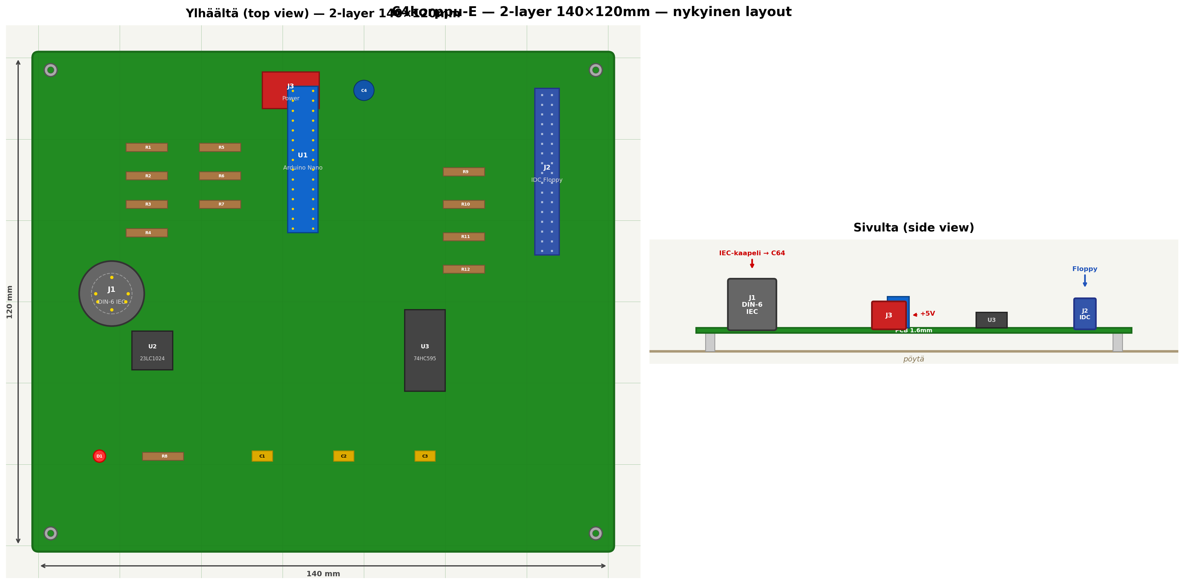
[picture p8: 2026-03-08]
docs/E-IEC-Nano-SRAM/64korppu-E-2layer-layout.png

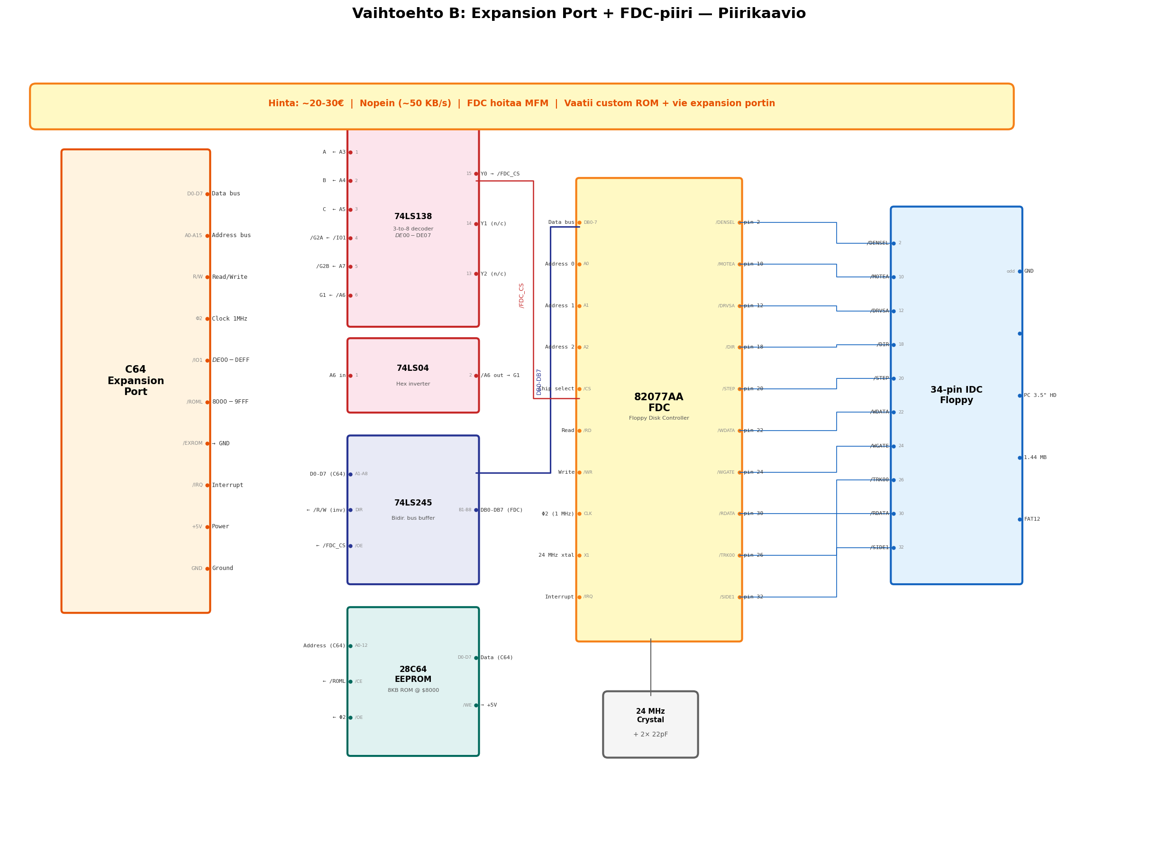
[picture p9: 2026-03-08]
docs/B-Expansion-FDC/img/piirikaavio.png

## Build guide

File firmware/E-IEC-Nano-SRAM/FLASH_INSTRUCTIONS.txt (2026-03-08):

64korppu Nano Firmware - Flashing Instructions (Windows)
=========================================================

1. Install avrdude
   - Download WinAVR from https://winavr.sourceforge.net/ (includes avrdude)
   - Or install via Chocolatey: choco install avrdude

2. Connect your Arduino Nano via USB

3. Find your COM port
   - Open Device Manager > Ports (COM & LPT)
   - Look for "USB-SERIAL" or "CH340" — note the COM number (e.g. COM3)

4. Flash the firmware
   Open Command Prompt and run:

   avrdude -c arduino -p atmega328p -P COM3 -b 115200 -U flash:w:64korppu_nano.hex:i

   Replace COM3 with your actual COM port.

5. If flashing fails, try the old bootloader baud rate:

   avrdude -c arduino -p atmega328p -P COM3 -b 57600 -U flash:w:64korppu_nano.hex:i

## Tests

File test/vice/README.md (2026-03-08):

# VICE IEC Bridge

Host-native build of 64korppu firmware for integration testing.

## Architecture

```
┌─────────────┐     TCP/6464     ┌──────────────────────┐
│ Python test  │◄───────────────►│  iec_bridge process   │
│ vice_test.py │                 │                       │
│ (simulates   │                 │  cbm_dos.c  (real)    │
│  C64 side)   │                 │  d64.c      (real)    │
│              │                 │  mock_fat12 (host fs) │
└─────────────┘                  │  mock_iec   (stubs)   │
                                 └──────────────────────┘
```

The bridge runs the **real** CBM-DOS and D64 code on the host machine.
FAT12 is mocked — D64 files are read from the host filesystem.
IEC protocol is replaced with a simple TCP binary protocol.

## Quick start

```bash
# Build
cd test
make vice/iec_bridge

# Start the bridge (scans current dir for .D64 files)
./vice/iec_bridge 6464 /path/to/d64/files/

# In another terminal, run the test client
python3 vice/vice_test.py
```

## TCP Protocol

Binary protocol, all integers are single bytes:

| Client → Server | Format |
|---|---|
| OPEN | `0x01` `sa` `len` `filename[len]` |
| CLOSE | `0x02` `sa` |
| READ | `0x03` `sa` |
| WRITE | `0x04` `sa` `byte` |
| EXEC | `0x05` `len` `command[len]` |
| QUIT | `0xFF` |

| Server → Client | Format |
|---|---|
| OK | `0x00` |
| BYTE | `0x01` `byte` `eoi` |
| NO DATA | `0x02` |
| ERROR | `0xFF` `code` `len` `msg[len]` |

## Using with VICE

For visual testing, you can use the Python client as a library
in a script that also controls VICE via its monitor interface:

```python
from vice_test import IECClient

c = IECClient()
c.mount_d64("GAME.D64")
data = c.load_file("INTRO")
# Write data to a .prg file, load in VICE...
```

Or generate .prg test files that exercise specific scenarios
and load them directly in VICE.

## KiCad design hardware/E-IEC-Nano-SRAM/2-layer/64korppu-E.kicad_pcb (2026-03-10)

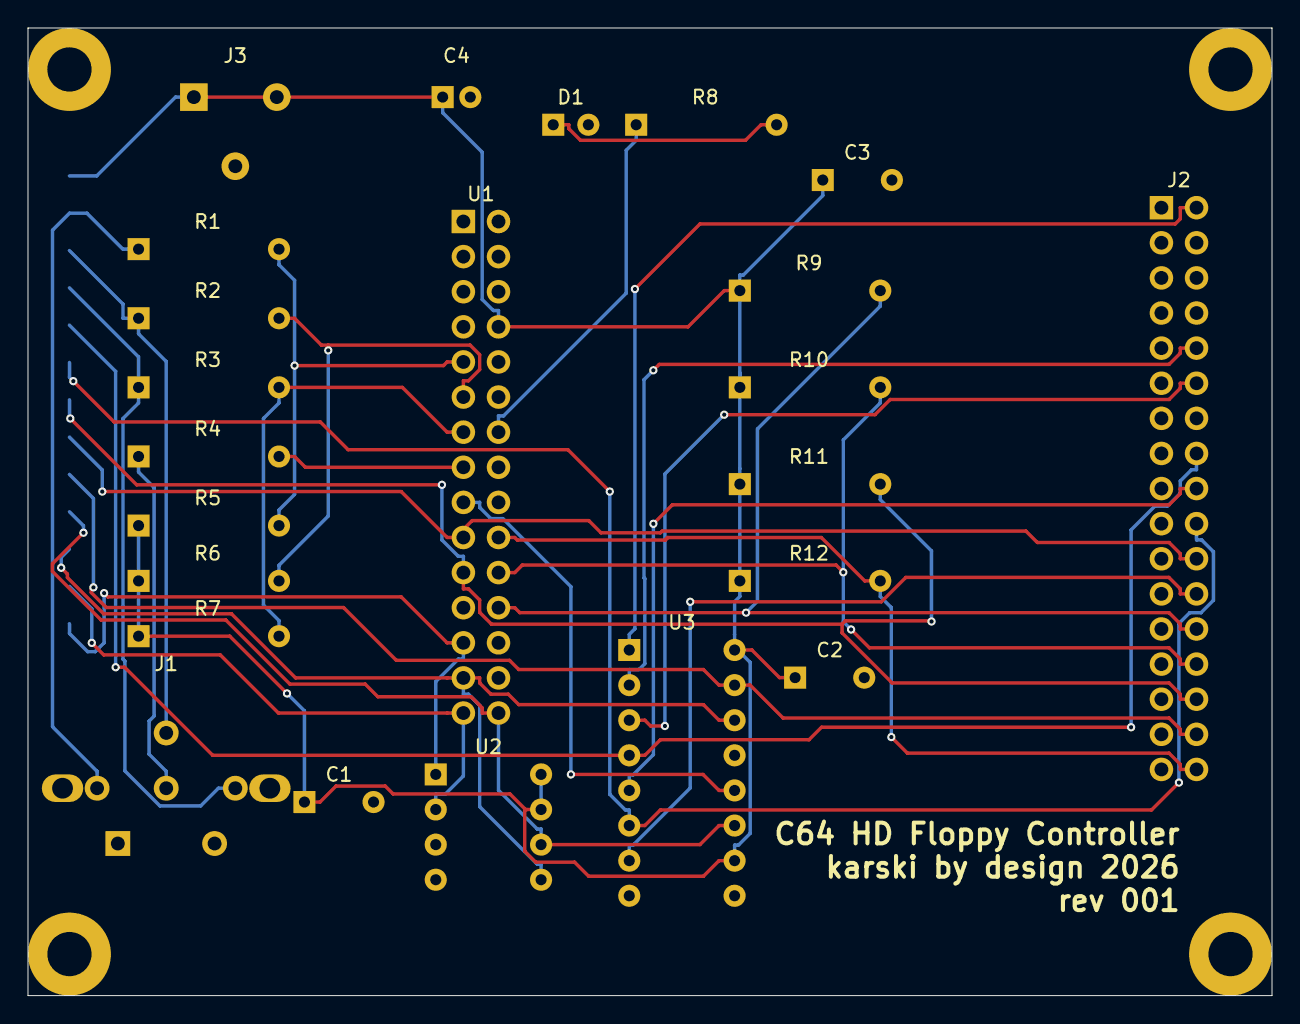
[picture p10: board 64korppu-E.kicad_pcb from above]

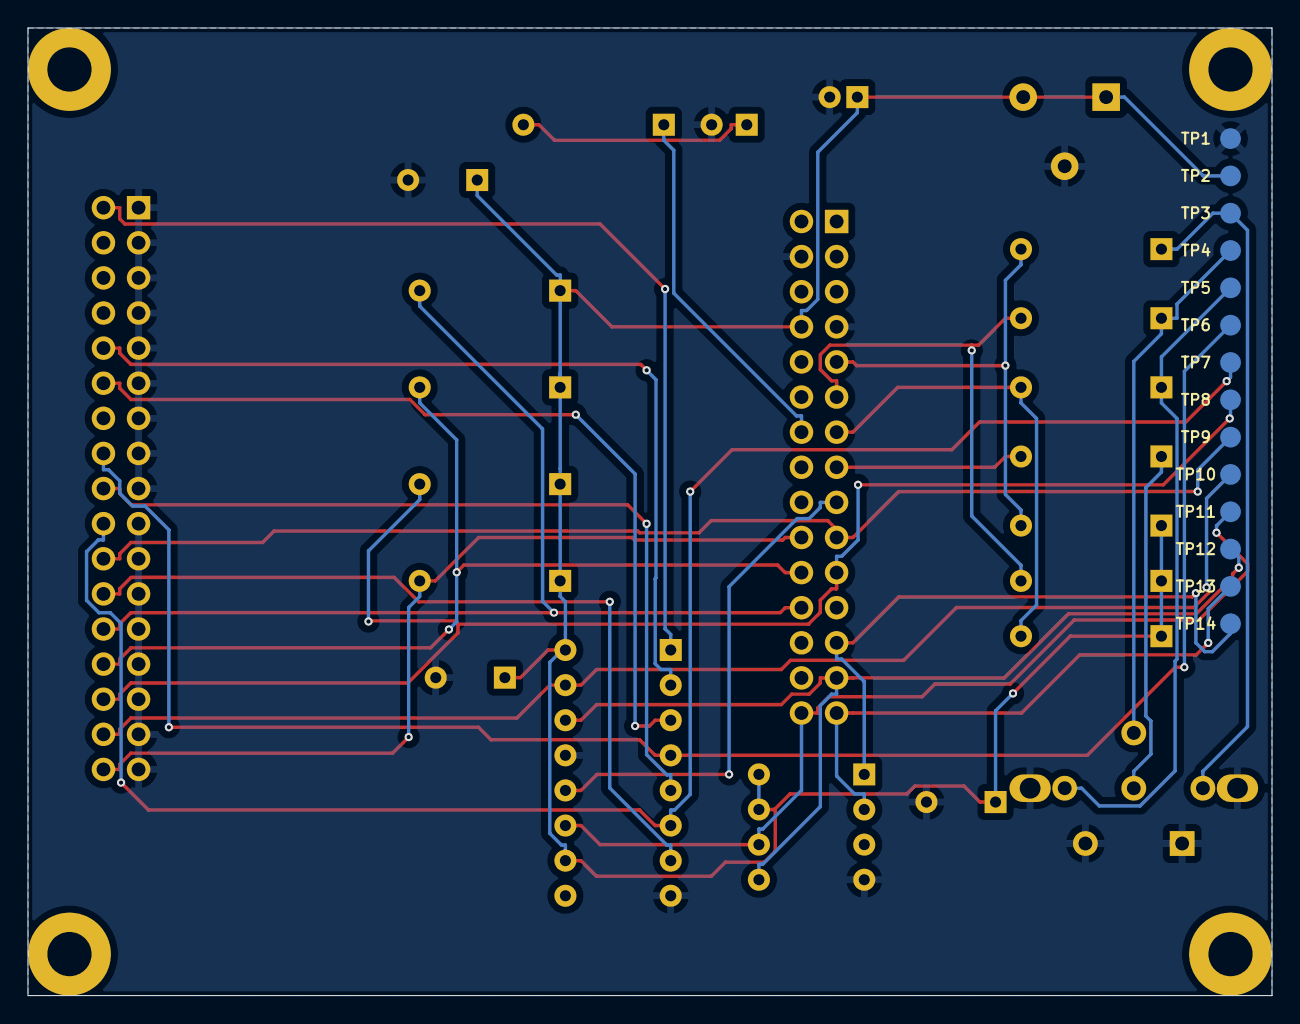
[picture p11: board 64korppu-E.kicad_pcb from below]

Board: 2 copper layers, 90.0 x 70.0 mm, 41 parts (14 on the bottom side), 30 nets.

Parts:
C1, C2, C3: 100nF; C_Disc_D5.0mm_W2.5mm_P5.00mm
C4: 100uF; CP_Radial_D5.0mm_P2.00mm
D1: LED; LED_D3.0mm
H1, H2, H3, H4: MountingHole; MountingHole_3.2mm_M3
J1: DIN-6_IEC; DIN-6_IEC_Vertical
J2: Floppy_34pin; IDC-Header_2x17_P2.54mm_Vertical
J3: DC_Jack; BarrelJack_Horizontal
R1, R2, R3, R4: 1k; R_Axial_DIN0207_L6.3mm_D2.5mm_P10.16mm_Horizontal
R5, R6, R7: 4.7k; R_Axial_DIN0207_L6.3mm_D2.5mm_P10.16mm_Horizontal
R8: 330; R_Axial_DIN0207_L6.3mm_D2.5mm_P10.16mm_Horizontal
R9, R10, R11, R12: 10k; R_Axial_DIN0207_L6.3mm_D2.5mm_P10.16mm_Horizontal
TP1: GND; TestPoint_Pad_D1.5_SMD
TP2: +5V; TestPoint_Pad_D1.5_SMD
TP3: IEC_ATN; TestPoint_Pad_D1.5_SMD
TP4: IEC_CLK; TestPoint_Pad_D1.5_SMD
TP5: IEC_DATA; TestPoint_Pad_D1.5_SMD
TP6: FLOPPY_MOTOR; TestPoint_Pad_D1.5_SMD
TP7: FLOPPY_STEP; TestPoint_Pad_D1.5_SMD
TP8: FLOPPY_RDATA; TestPoint_Pad_D1.5_SMD
TP9: FLOPPY_WDATA; TestPoint_Pad_D1.5_SMD
TP10: FLOPPY_SIDE1; TestPoint_Pad_D1.5_SMD
TP11: SPI_SCK; TestPoint_Pad_D1.5_SMD
TP12: SPI_MOSI; TestPoint_Pad_D1.5_SMD
TP13: SPI_MISO; TestPoint_Pad_D1.5_SMD
TP14: SPI_CS_SRAM; TestPoint_Pad_D1.5_SMD
U1: Arduino_Nano; PinHeader_2x15_P2.54mm_Vertical
U2: 23LC256; DIP-8_W7.62mm_Socket
U3: 74HC595; DIP-16_W7.62mm_Socket

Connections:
+5V: C1.1, C2.1, C3.1, C4.1, J3.1, J3.2, R5.1, R6.1, R7.1, R9.1, R10.1, R11.1, R12.1, TP2.1, U1.8, U2.7, U2.8, U3.10, U3.16
FLOPPY_DENSITY: J2.2, U3.1
FLOPPY_DIR: J2.18, U3.5
FLOPPY_DRVSEL: J2.12, U3.3
FLOPPY_DSKCHG: J2.34, R12.2, U1.20
FLOPPY_MOTEA: J2.10, U3.2
FLOPPY_MOTOR: J2.16, TP6.1, U3.4
FLOPPY_RDATA: J2.30, R11.2, TP8.1, U1.21
FLOPPY_SIDE1: J2.32, TP10.1, U3.15
FLOPPY_STEP: J2.20, TP7.1, U3.6
FLOPPY_TRK00: J2.26, R9.2, U1.24
FLOPPY_WDATA: J2.22, TP9.1, U1.19
FLOPPY_WGATE: J2.24, U3.7
FLOPPY_WPT: J2.28, R10.2, U1.22
GND: C1.2, C2.2, C3.2, C4.2, D1.2, J1.1, J1.2, J1.SH, J2.1, J2.3, J2.5, J2.7, J2.9, J2.11, J2.13, J2.15, J2.17, J2.19, J2.21, J2.23, J2.25, J2.27, J2.29, J2.31, J2.33, J3.3, TP1.1, U1.4, U1.7, U2.4, U3.8, U3.13
IEC_ATN: J1.3, R1.1, TP3.1
IEC_CLK: J1.4, R2.1, TP4.1
IEC_DATA: J1.5, R3.1, TP5.1
IEC_RESET: J1.6, R4.1
LATCH_595: U1.17, U3.12
LED_ANODE: R8.1, U1.14
LED_CATHODE: D1.1, R8.2
NANO_D2: R1.2, R5.2, U1.9
NANO_D3: R2.2, R6.2, U1.11
NANO_D4: R3.2, R7.2, U1.13
NANO_D5: R4.2, U1.15
SPI_CS_SRAM: TP14.1, U1.25, U2.1
SPI_MISO: TP13.1, U1.29, U2.2
SPI_MOSI: TP12.1, U1.27, U2.5, U3.14
SPI_SCK: TP11.1, U1.30, U2.6, U3.11

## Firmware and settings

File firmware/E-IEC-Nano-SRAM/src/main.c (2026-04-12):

#ifdef __AVR__

#include <avr/io.h>
#include <avr/interrupt.h>
#include <avr/pgmspace.h>
#include <util/delay.h>
#include <string.h>

#include "config.h"
#include "uart.h"
#include "sram.h"
#include "shiftreg.h"
#include "floppy_ctrl.h"
#include "mfm_codec.h"
#include "fat12.h"
#include "iec_protocol.h"
#include "cbm_dos.h"
#include "fastload.h"
#include "fastload_jiffydos.h"
#include "fastload_burst.h"
#include "fastload_epyx.h"
#include "compress_proto.h"
#include "led_debug.h"

/*
 * 64korppu — Alternative E: Arduino Nano + 23LC512 SPI SRAM
 *
 * C64 IEC serial bus ↔ PC 3.5" HD floppy via ATmega328P.
 * Single-core: IEC and floppy operations are interleaved.
 *
 * Boot sequence:
 *   1. Initialize SPI + SRAM + shift register
 *   2. Initialize IEC bus (device #8) — early, so device responds ASAP
 *   3. Initialize floppy drive (motor on, recalibrate)
 *   4. Read boot sector, mount FAT12
 *   5. Enter main loop: service IEC bus
 */

/* (sector buffer is in fat12.c as static) */

/*
 * Disk I/O interface for FAT12 layer.
 * Converts LBA to CHS and reads/writes via floppy controller.
 */
int disk_read_sector(uint16_t lba, uint8_t *buf) {
    uint8_t track, side, sector;
    floppy_lba_to_chs(lba, &track, &side, &sector);
    TRACE("[DISK] read LBA=");
    uart_putdec(lba);
    TRACE(" T=");
    uart_putdec(track);
    TRACE(" S=");
    uart_putdec(side);
    TRACE(" R=");
    uart_putdec(sector);
    TRACE("\r\n");
    int rc = floppy_read_sector(track, side, sector, buf);
    TRACE("[DISK] read rc=");
    uart_putdec((uint16_t)(rc < 0 ? -rc : rc));
    if (rc < 0) TRACE(" ERR");
    TRACE("\r\n");
    return rc;
}

int disk_write_sector(uint16_t lba, const uint8_t *buf) {
    uint8_t track, side, sector;
    floppy_lba_to_chs(lba, &track, &side, &sector);
    TRACE("[DISK] write LBA=");
    uart_putdec(lba);
    TRACE(" T=");
    uart_putdec(track);
    TRACE(" S=");
    uart_putdec(side);
    TRACE(" R=");
    uart_putdec(sector);
    TRACE("\r\n");
    int rc = floppy_write_sector(track, side, sector, (uint8_t *)buf);
    TRACE("[DISK] write rc=");
    uart_putdec((uint16_t)(rc < 0 ? -rc : rc));
    if (rc < 0) TRACE(" ERR");
    TRACE("\r\n");
    return rc;
}

/*
 * UART initialization for debug output (9600 baud at 16MHz).
 */
void uart_init(void) {
    uint16_t baud_setting = (F_CPU / 8 / 9600) - 1;
    UBRR0H = baud_setting >> 8;
    UBRR0L = baud_setting & 0xFF;
    UCSR0A |= (1 << U2X0);
    UCSR0B = (1 << TXEN0);
    UCSR0C = (1 << UCSZ01) | (1 << UCSZ00);  /* 8N1 */
}

void uart_putchar(char c) {
    while (!(UCSR0A & (1 << UDRE0)));
    UDR0 = c;
}

void uart_puts(const char *s) {
    while (*s) uart_putchar(*s++);
}

void uart_puts_P(const char *s) {
    char c;
    while ((c = pgm_read_byte(s++))) uart_putchar(c);
}

static const char hex_chars[] PROGMEM = "0123456789ABCDEF";

void uart_puthex8(uint8_t val) {
    uart_putchar(pgm_read_byte(&hex_chars[val >> 4]));
    uart_putchar(pgm_read_byte(&hex_chars[val & 0x0F]));
}

void uart_puthex16(uint16_t val) {
    uart_puthex8(val >> 8);
    uart_puthex8(val & 0xFF);
}

void uart_putdec(uint16_t val) {
    char buf[6];
    int i = 0;
    if (val == 0) { uart_putchar('0'); return; }
    while (val > 0) { buf[i++] = '0' + (val % 10); val /= 10; }
    while (i > 0) uart_putchar(buf[--i]);
}

int main(void) {
    /* Disable interrupts during init */
    cli();

    /*
     * CRITICAL: force 74HC595 outputs safe BEFORE anything else.
     * At power-on, shift register outputs are random. /WGATE could
     * be asserted (LOW) which would corrupt disk data. RCLK (D6)
     * is floating as INPUT, so any SPI activity could accidentally
     * latch garbage. Pin RCLK LOW immediately, then write 0xFF
     * (all deasserted) as soon as SPI is available.
     */
    DDRD |= (1 << PD6);    /* RCLK = output */
    PORTD &= ~(1 << PD6);  /* RCLK = LOW (prevent accidental latch) */

    uart_init();
    TRACE("\r\n=== 64korppu v1.0 (Nano+SRAM) ===\r\n");

    /* Initialize LED debug (green D9, optional red A5) */
    led_debug_init();

    /* Initialize SPI and SRAM */
    sram_init();
    TRACE("SRAM OK\r\n");

    /* Initialize shift register — writes 0xFF (all safe) immediately */
    shiftreg_init();
    TRACE("74HC595 OK\r\n");

    /* Initialize MFM codec (Timer1) */
    mfm_init();

    /* Initialize IEC bus EARLY — device responds on bus ASAP */
    TRACE("IEC device #8\r\n");
    iec_init(IEC_DEFAULT_DEVICE);
    cbm_dos_init();

    /* Initialize fast-load protocols */
    fastload_init();
    fastload_jiffydos_register();
    fastload_burst_register();
    fastload_epyx_register();
    TRACE("Fastload OK\r\n");

    /* Initialize compression protocol */
    compress_proto_init();
    TRACE("Compress OK\r\n");

    /* Enable interrupts before floppy init (MFM capture needs ISR) */
    sei();

    /* Initialize floppy drive (~2.8s blocking) */
    floppy_init();
    TRACE("Floppy init...\r\n");

    floppy_motor_on();
    int rc = floppy_recalibrate();
    if (rc != FLOPPY_OK) {
        TRACE("No drive!\r\n");
        iec_set_error(CBM_ERR_DRIVE_NOT_READY, "DRIVE NOT READY", 0, 0);
        led_debug_blink(DBG_FLOPPY_ERROR);
        floppy_motor_off();
        goto boot_done;
    }
    TRACE("Drive OK\r\n");

    /* Check if disk is present via /DSKCHG */
    if (!floppy_check_disk()) {
        TRACE("No disk in drive\r\n");
        iec_set_error(CBM_ERR_DRIVE_NOT_READY, "DRIVE NOT READY", 0, 0);
        led_debug_blink(DBG_NO_DISK);
        floppy_motor_off();
        goto boot_done;
    }

    /* Mount FAT12 */
    TRACE("Mount FAT12...\r\n");
    rc = fat12_mount();
    if (rc == FAT12_OK) {
        TRACE("FAT12 OK\r\n");
    } else {
        TRACE("Mount failed\r\n");
        iec_set_error(CBM_ERR_DRIVE_NOT_READY, "DRIVE NOT READY", 0, 0);
        led_debug_blink(DBG_NO_DISK);
    }

    /* Motor off after init — read/write will restart it on demand */
    floppy_motor_off();

boot_done:

    TRACE("Ready.\r\n");
    led_debug_blink(DBG_BOOT_OK);

    /* Main loop: service IEC bus */
    while (1) {
        iec_service();
    }

    return 0;
}

#endif /* __AVR__ */

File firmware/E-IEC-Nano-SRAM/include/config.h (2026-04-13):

#ifndef CONFIG_H
#define CONFIG_H

#include <stdint.h>
#include <stdbool.h>

/*
 * Hardware configuration for Alternative E:
 * Arduino Nano (ATmega328P) + 23LC512 SPI SRAM + 74HC595 shift register
 */

/* --- SRAM Memory Map (23LC512, 64KB) --- */

#define SRAM_SIZE           0x10000UL   /* 65536 bytes */

#define SRAM_MFM_TRACK      0x00000UL   /* MFM decoded track buffer */
#define SRAM_MFM_TRACK_SIZE 12496

/* Raw capture buffer: stores uint8_t timer intervals during ISR capture.
 * Occupies entire SRAM during capture (other buffers not needed then).
 * ~50000 intervals ≈ 1 revolution at HD 500kbps. */
#define SRAM_RAW_CAPTURE      0x00000UL
#define SRAM_RAW_CAPTURE_SIZE 50000UL

#define SRAM_FAT_CACHE      0x030D0UL   /* FAT table cache (9 sectors) */
#define SRAM_FAT_CACHE_SIZE 4608        /* 9 * 512 */

#define SRAM_SECTOR_BUF1    0x042D0UL   /* Sector buffer #1 */
#define SRAM_SECTOR_BUF2    0x044D0UL   /* Sector buffer #2 */
#define SRAM_SECTOR_SIZE    512

#define SRAM_DIR_BUF        0x046D0UL   /* Directory listing buffer */
#define SRAM_DIR_BUF_SIZE   4096

#define SRAM_IEC_BUF        0x056D0UL   /* IEC channel buffer */
#define SRAM_IEC_BUF_SIZE   512

/* LZ4 compression buffers (in external SRAM, not internal RAM) */
#define SRAM_COMP_RAW       0x058D0UL   /* Raw data before compression */
#define SRAM_COMP_RAW_SIZE  512         /* = COMPRESS_BLOCK_SIZE */
#define SRAM_COMP_FRAME     0x05AD0UL   /* Framed LZ4 output */
#define SRAM_COMP_FRAME_SIZE 556        /* = COMPRESS_FRAME_BUF_SIZE */
                                        /* Vapaa: 0x05D0C - 0x0FFFF = ~41.2 KB */

/* --- Floppy Geometry --- */

#define FLOPPY_TRACKS         80
#define FLOPPY_SIDES           2
#define FLOPPY_SECTORS_HD     18
#define FLOPPY_SECTOR_SIZE   512
#define FLOPPY_TOTAL_SECTORS (FLOPPY_TRACKS * FLOPPY_SIDES * FLOPPY_SECTORS_HD)

/* Timing constants (microseconds) */
#define FLOPPY_STEP_PULSE_US    3
#define FLOPPY_STEP_SETTLE_MS  15
#define FLOPPY_STEP_RATE_MS     3

/* Error codes */
#define FLOPPY_OK               0
#define FLOPPY_ERR_NO_TRK0    -1
#define FLOPPY_ERR_SEEK        -2
#define FLOPPY_ERR_READ        -3
#define FLOPPY_ERR_WRITE       -4
#define FLOPPY_ERR_WP          -5
#define FLOPPY_ERR_NO_DISK     -6
#define FLOPPY_ERR_CRC         -7
#define FLOPPY_ERR_NO_SECTOR   -8
#define FLOPPY_ERR_TIMEOUT     -9

/* --- AVR-specific Pin Assignments --- */

#ifdef __AVR__

#include <avr/io.h>

/* IEC bus (direct GPIO, active-low open-collector) */
#define IEC_PIN_ATN      PD2    /* INT0 interrupt */
#define IEC_PIN_CLK      PD3
#define IEC_PIN_DATA     PD4
#define IEC_PIN_RESET    PD5
#define IEC_DDR          DDRD
#define IEC_PORT         PORTD
#define IEC_PINR         PIND

/* SPI (shared SRAM + 74HC595) */
#define SPI_CS_SRAM      PB2    /* D10 = /CS_SRAM */
#define SPI_MOSI         PB3    /* D11 */
#define SPI_MISO         PB4    /* D12 */
#define SPI_SCK          PB5    /* D13 */

/* 74HC595 latch */
#define SR_RCLK_PIN      PD6    /* D6 = RCLK (latch) */
#define SR_RCLK_DDR      DDRD
#define SR_RCLK_PORT     PORTD

/* 74HC595 output enable (active LOW, active = outputs drive) */
#define SR_OE_PIN        PC3    /* A3 = /OE */
#define SR_OE_DDR        DDRC
#define SR_OE_PORT       PORTC

/* Floppy direct GPIO */
#define FLOPPY_WDATA_PIN    PD7    /* D7 = /WDATA (direct for timing) */
#define FLOPPY_WDATA_DDR    DDRD
#define FLOPPY_WDATA_PORT   PORTD
#define FLOPPY_RDATA_PIN    PB0    /* D8 = /RDATA (ICP1 input capture) */
#define FLOPPY_LED_PIN      PB1    /* D9 = LED */

/* Floppy input (active-low, internal pull-up) */
#define FLOPPY_TRK00_PIN    PC0    /* A0 = /TRK00 */
#define FLOPPY_WPT_PIN      PC1    /* A1 = /WPT */
#define FLOPPY_DSKCHG_PIN   PC2    /* A2 = /DSKCHG */
#define FLOPPY_IN_DDR       DDRC
#define FLOPPY_IN_PORT      PORTC
#define FLOPPY_IN_PINR      PINC

#endif /* __AVR__ */

/* --- 74HC595 Shift Register Bit Assignments --- */

#define SR_BIT_SIDE1     0    /* QA (pin 15) = /SIDE1 */
#define SR_BIT_DENSITY   1    /* QB (pin  1) = /DENSITY */
#define SR_BIT_MOTEA     2    /* QC (pin  2) = /MOTEA */
#define SR_BIT_DRVSEL    3    /* QD (pin  3) = /DRVSEL */
#define SR_BIT_MOTOR     4    /* QE (pin  4) = /MOTOR */
#define SR_BIT_DIR       5    /* QF (pin  5) = /DIR */
#define SR_BIT_STEP      6    /* QG (pin  6) = /STEP */
#define SR_BIT_WGATE     7    /* QH (pin  7) = /WGATE */

/* Default: all deasserted (HIGH for active-low signals) */
#define SR_DEFAULT       0xFF

/* --- IEC Protocol --- */

#define IEC_DEFAULT_DEVICE   8
#define IEC_NUM_CHANNELS    16

/* IEC bus commands (under ATN) */
#define IEC_CMD_LISTEN      0x20
#define IEC_CMD_UNLISTEN    0x3F
#define IEC_CMD_TALK        0x40
#define IEC_CMD_UNTALK      0x5F
#define IEC_CMD_OPEN        0x60
#define IEC_CMD_CLOSE       0xE0

/* Secondary addresses */
#define IEC_SA_LOAD          0
#define IEC_SA_SAVE          1
#define IEC_SA_COMMAND      15
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

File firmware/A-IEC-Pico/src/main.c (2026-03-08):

#include <stdio.h>
#include "pico/stdlib.h"
#include "pico/multicore.h"
#include "hardware/gpio.h"
#include "floppy_ctrl.h"
#include "mfm_codec.h"
#include "fat12.h"
#include "iec_protocol.h"
#include "cbm_dos.h"

/*
 * 64korppu - C64 IEC ↔ PC 1.44MB floppy bridge
 *
 * Core 0: IEC bus protocol + FAT12 + CBM-DOS
 * Core 1: Floppy drive control + MFM encoding/decoding
 */

/* Inter-core command queue */
typedef enum {
    FLOPPY_CMD_NONE = 0,
    FLOPPY_CMD_READ_SECTOR,
    FLOPPY_CMD_WRITE_SECTOR,
    FLOPPY_CMD_FORMAT_TRACK,
    FLOPPY_CMD_MOTOR_ON,
    FLOPPY_CMD_MOTOR_OFF,
    FLOPPY_CMD_RECALIBRATE,
} floppy_cmd_t;

typedef struct {
    floppy_cmd_t cmd;
    uint8_t track;
    uint8_t side;
    uint8_t sector;
    int result;
    volatile bool busy;
    volatile bool done;
} floppy_request_t;

static volatile floppy_request_t floppy_req = {0};

/* Shared sector buffer between cores */
static uint8_t shared_sector_buf[FLOPPY_SECTOR_SIZE];

/*
 * Core 1 entry point: floppy drive control loop.
 * Waits for commands from core 0 and executes them.
 */
static void core1_floppy_task(void) {
    floppy_init();
    mfm_init();

    while (true) {
        if (floppy_req.busy && !floppy_req.done) {
            int result = FLOPPY_OK;

            switch (floppy_req.cmd) {
                case FLOPPY_CMD_READ_SECTOR:
                    result = floppy_read_sector(
                        floppy_req.track, floppy_req.side,
                        floppy_req.sector, shared_sector_buf);
                    break;

                case FLOPPY_CMD_WRITE_SECTOR:
                    result = floppy_write_sector(
                        floppy_req.track, floppy_req.side,
                        floppy_req.sector, shared_sector_buf);
                    break;

                case FLOPPY_CMD_MOTOR_ON:
                    floppy_motor_on();
                    break;

                case FLOPPY_CMD_MOTOR_OFF:
                    floppy_motor_off();
                    break;

                case FLOPPY_CMD_RECALIBRATE:
                    result = floppy_recalibrate();
                    break;

                default:
                    break;
            }

            floppy_req.result = result;
            floppy_req.done = true;
            __dmb();  /* Ensure writes are visible to core 0 */
        }

        tight_loop_contents();
    }
}

/*
 * Submit a floppy command to core 1 and wait for completion.
 */
static int floppy_submit_and_wait(floppy_cmd_t cmd, uint8_t track,
                                   uint8_t side, uint8_t sector) {
    floppy_req.cmd = cmd;
    floppy_req.track = track;
    floppy_req.side = side;
    floppy_req.sector = sector;
    floppy_req.done = false;
    __dmb();
    floppy_req.busy = true;

    /* Wait for core 1 to complete */
    while (!floppy_req.done) {
        tight_loop_contents();
    }

    floppy_req.busy = false;
    return floppy_req.result;
}

/*
 * Disk I/O interface for FAT12 layer.
 * These are called from core 0 and delegate to core 1.
 */
int disk_read_sector(uint16_t lba, uint8_t *buf) {
    uint8_t track, side, sector;
    floppy_lba_to_chs(lba, &track, &side, &sector);

    int result = floppy_submit_and_wait(FLOPPY_CMD_READ_SECTOR, track, side, sector);
    if (result == FLOPPY_OK) {
        memcpy(buf, shared_sector_buf, FLOPPY_SECTOR_SIZE);
    }
    return result;
}

int disk_write_sector(uint16_t lba, const uint8_t *buf) {
    uint8_t track, side, sector;
    floppy_lba_to_chs(lba, &track, &side, &sector);

    memcpy(shared_sector_buf, buf, FLOPPY_SECTOR_SIZE);
    return floppy_submit_and_wait(FLOPPY_CMD_WRITE_SECTOR, track, side, sector);
}

int main(void) {
    stdio_init_all();

    printf("\n=== 64korppu v1.0 ===\n");
    printf("C64 IEC <-> PC 1.44MB Floppy Bridge\n\n");

    /* Launch core 1 for floppy control */
    multicore_launch_core1(core1_floppy_task);

    /* Wait for core 1 to initialize */
    sleep_ms(100);

    /* Initialize floppy drive */
    printf("Initializing floppy drive...\n");
    int result = floppy_submit_and_wait(FLOPPY_CMD_MOTOR_ON, 0, 0, 0);
    if (result != FLOPPY_OK) {
        printf("Motor start failed: %d\n", result);
    }

    result = floppy_submit_and_wait(FLOPPY_CMD_RECALIBRATE, 0, 0, 0);
    if (result == FLOPPY_OK) {
        printf("Drive recalibrated OK\n");
    } else {
        printf("Recalibrate failed: %d\n", result);
    }

    /* Mount FAT12 filesystem */
    printf("Mounting FAT12...\n");
    result = fat12_mount();
    if (result == FAT12_OK) {
        printf("FAT12 mounted OK\n");
        uint32_t free = fat12_free_space();
        printf("Free space: %lu bytes\n", (unsigned long)free);
    } else {
        printf("FAT12 mount failed: %d (insert formatted disk)\n", result);
    }

    /* Initialize IEC bus and CBM-DOS */
    printf("Starting IEC device #8...\n");
    iec_init(IEC_DEFAULT_DEVICE);
    cbm_dos_init();
    printf("Ready. Waiting for C64...\n\n");

    /* Main loop: service IEC bus */
    while (true) {
        iec_service();
    }

    return 0;
}

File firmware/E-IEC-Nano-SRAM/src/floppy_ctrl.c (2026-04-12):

#include "floppy_ctrl.h"
#include "config.h"
#include "shiftreg.h"
#include "mfm_codec.h"
#include "iec_protocol.h"
#include "uart.h"

#ifdef __AVR__

#include <avr/io.h>
#include <util/delay.h>

/*
 * Floppy drive control for Arduino Nano.
 *
 * Output signals (/DENSITY, /MOTEA, /DRVSEL, /MOTOR, /DIR, /STEP,
 * /WGATE, /SIDE1) go through 74HC595 shift register.
 *
 * Input signals (/TRK00, /WPT, /DSKCHG) are direct GPIO on A0-A2.
 * /RDATA on D8 (Timer1 ICP1) for MFM capture.
 * /WDATA on D7 (direct GPIO) for MFM write.
 */

static floppy_state_t state = {0};

void floppy_init(void) {
    TRACE("[FLP] init GPIO...\r\n");

    /* Input pins with pull-ups: /TRK00 (A0), /WPT (A1), /DSKCHG (A2) */
    FLOPPY_IN_DDR &= ~((1 << FLOPPY_TRK00_PIN) |
                        (1 << FLOPPY_WPT_PIN) |
                        (1 << FLOPPY_DSKCHG_PIN));
    FLOPPY_IN_PORT |= (1 << FLOPPY_TRK00_PIN) |
                      (1 << FLOPPY_WPT_PIN) |
                      (1 << FLOPPY_DSKCHG_PIN);

    /* /RDATA (D8 = PB0) as input */
    DDRB &= ~(1 << FLOPPY_RDATA_PIN);

    /* /WDATA (D7 = PD7) as output, HIGH (deasserted) */
    FLOPPY_WDATA_DDR |= (1 << FLOPPY_WDATA_PIN);
    FLOPPY_WDATA_PORT |= (1 << FLOPPY_WDATA_PIN);

    /* LED (D9 = PB1) as output */
    DDRB |= (1 << FLOPPY_LED_PIN);

    /* Set shift register: HD density, drive selected, everything else deasserted */
    uint8_t sr = SR_DEFAULT;
    sr &= ~(1 << SR_BIT_DENSITY);  /* Assert /DENSITY (LOW = HD) */
    sr &= ~(1 << SR_BIT_DRVSEL);   /* Assert /DRVSEL (select drive) */
    shiftreg_write(sr);

    /* Read input pin states for debug */
    uint8_t pins = FLOPPY_IN_PINR;
    TRACE("[FLP] inputs: TRK00=");
    uart_putchar((pins & (1 << FLOPPY_TRK00_PIN)) ? 'H' : 'L');
    TRACE(" WPT=");
    uart_putchar((pins & (1 << FLOPPY_WPT_PIN)) ? 'H' : 'L');
    TRACE(" DSKCHG=");
    uart_putchar((pins & (1 << FLOPPY_DSKCHG_PIN)) ? 'H' : 'L');
    TRACE("\r\n");

    state.current_track = 0;
    state.current_side = 0;
    state.motor_on = false;
    state.disk_present = false;
    state.write_protected = false;
    state.initialized = false;

    TRACE("[FLP] init done, SR=0x");
    uart_puthex8(sr);
    TRACE("\r\n");
}

void floppy_motor_on(void) {
    if (!state.motor_on) {
        TRACE("[FLP] motor ON, waiting for speed...\r\n");
        shiftreg_assert_bit(SR_BIT_MOTEA);
        shiftreg_assert_bit(SR_BIT_MOTOR);
        PORTB |= (1 << FLOPPY_LED_PIN);  /* LED on */

        /*
         * Wait for motor to reach stable speed by monitoring /RDATA (ICP1).
         * Valid MFM intervals (with pull-up delay compensation) must be
         * within the expected range. We require 16 consecutive valid
         * intervals and track the average to verify correct RPM.
         *
         * Timeout 1000ms. IEC serviced during wait.
         */
        uint16_t prev = ICR1;
        uint8_t valid_count = 0;
        uint32_t interval_sum = 0;
        bool ready = false;
        uint16_t ms;

        for (ms = 0; ms < 1000 && !ready; ms++) {
            _delay_ms(1);

            /* Check for ICP events */
            if (TIFR1 & (1 << ICF1)) {
                uint16_t now = ICR1;
                uint16_t interval = now - prev;
                prev = now;
                TIFR1 = (1 << ICF1);

                /* Valid MFM interval? (2T..4T with pull-up compensation) */
                if (interval >= 40 && interval <= (MFM_THRESHOLD_LONG + 40)) {
                    interval_sum += interval;
                    valid_count++;
                    if (valid_count >= 16) {
                        ready = true;
                    }
                } else {
                    valid_count = 0;
                    interval_sum = 0;
                }
            }
        }

        if (ready) {
            uint16_t avg = (uint16_t)(interval_sum / 16);
            TRACE("[FLP] motor ready after ");
            uart_putdec(ms);
            TRACE("ms, avg interval=");
            uart_putdec(avg);
            TRACE(" ticks\r\n");

            /* Verify RPM: average interval should be ~92-120 ticks
             * (HD MFM 2T-3T mix with pull-up delay).
             * If >> 150, motor is too slow (wrong voltage?).
             * If << 50, signal is noise (not real MFM). */
            if (avg > 170) {
                TRACE("[FLP] WARNING: motor too slow! avg=");
                uart_putdec(avg);
                TRACE(" (expected ~100). Check 12V supply.\r\n");
            } else if (avg < 50) {
                TRACE("[FLP] WARNING: signal too fast, noise? avg=");
                uart_putdec(avg);
                TRACE("\r\n");
            }
        } else {
            TRACE("[FLP] motor spin-up timeout (no /RDATA)\r\n");
        }

        state.motor_on = true;
    }
}

void floppy_motor_off(void) {
    TRACE("[FLP] motor OFF\r\n");
    shiftreg_release_bit(SR_BIT_MOTEA);
    shiftreg_release_bit(SR_BIT_MOTOR);
    state.motor_on = false;
    PORTB &= ~(1 << FLOPPY_LED_PIN);  /* LED off */
}

static void step_once(bool inward) {
    /* Set direction: assert /DIR = inward (toward center) */
    if (inward) {
        shiftreg_assert_bit(SR_BIT_DIR);
    } else {
        shiftreg_release_bit(SR_BIT_DIR);
    }
    _delay_us(10);

    /* Step pulse */
    shiftreg_assert_bit(SR_BIT_STEP);
    _delay_us(FLOPPY_STEP_PULSE_US);
    shiftreg_release_bit(SR_BIT_STEP);
    _delay_ms(FLOPPY_STEP_RATE_MS);
}

int floppy_recalibrate(void) {
    TRACE("[FLP] recalibrate: seeking track 0...\r\n");
    for (int i = 0; i < 85; i++) {
        if (!(FLOPPY_IN_PINR & (1 << FLOPPY_TRK00_PIN))) {
            /* /TRK00 active low - we're at track 0 */
            state.current_track = 0;
            state.initialized = true;
            for (uint8_t d = 0; d < FLOPPY_STEP_SETTLE_MS; d++) {
                _delay_ms(1); iec_poll();
            }
            TRACE("[FLP] TRK00 found after ");
            uart_putdec(i);
            TRACE(" steps\r\n");
            return FLOPPY_OK;
        }
        step_once(false);  /* Step outward */
    }
    TRACE("[FLP] ERR: TRK00 not found after 85 steps!\r\n");
    return FLOPPY_ERR_NO_TRK0;
}

bool floppy_check_disk(void) {
    /*
     * Read /DSKCHG (A2) after head has stepped (recalibrate).
     * /DSKCHG is active-low:
     *   LOW  = disk changed / no disk present
     *   HIGH = disk present (cleared by step pulse)
     */
    bool present = !!(FLOPPY_IN_PINR & (1 << FLOPPY_DSKCHG_PIN));
    state.disk_present = present;
    state.write_protected = !(FLOPPY_IN_PINR & (1 << FLOPPY_WPT_PIN));

    TRACE("[FLP] disk check: DSKCHG=");
    uart_putchar(present ? 'H' : 'L');
    TRACE(" WPT=");
    uart_putchar(state.write_protected ? 'Y' : 'N');
    if (present) {
        TRACE(" -> disk PRESENT\r\n");
    } else {
        TRACE(" -> disk NOT PRESENT\r\n");
    }

    return present;
}
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

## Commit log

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2026-03-08 Add D64 disk image support with full read/write and test suite
    Implement D64 disk image mounting for the Pico firmware (variant A),
    enabling C64 users to load programs from standard .D64 files copied
    to FAT12 floppy disks. The D64 image is loaded into Pico RAM buffer
    and accessed via SD2IEC-compatible CD: commands on the IEC command channel.
    New modules:
    - d64.c/d64.h: D64 image parsing, mount/unmount/flush, BAM management,
    directory listing, file read/write/delete via track/sector chains
    - cbm_dos.c: d64_mode branching for LOAD/SAVE/dollar, CD: mount/unmount,
    S: scratch command in D64 mode
    Test infrastructure:
    - 27 unit tests (test_d64.c) with FAT12 mock - found and fixed 3 bugs
    (ui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
    [cbm_dos.c]
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2026-03-08 Add Gerber zip to bin/E-IEC-Nano-SRAM and fix PCB layout
    Move firmware binary and add manufacturing Gerbers into
    bin/E-IEC-Nano-SRAM/. Fix PCB: move R9-R12 and U3 to
    eliminate pad overlaps, enlarge board to 115x95mm, fill
    GND zone. All 30 nets routed by Freerouting.
    [64korppu-E.dsn, 64korppu-E.kicad_pcb]
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2026-03-08 Geometric PCB layout with aligned components and fix grep -P for macOS
    - Redesign component placement with grid-aligned positions
    - Power row at y=108, ICs at y=172, passives at y=198
    - Consistent 7-8mm spacing between resistor groups
    - Fix pcb-pipeline.sh grep -P (PCRE) to sed for macOS compatibility
    - Update gerber zip in bin/
    [64korppu-E-B_Cu.gbl, 64korppu-E-B_Mask.gbs, 64korppu-E-B_Silkscreen.gbo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]
2026-03-08 Convert PCB to 4-layer 70x60mm (75% smaller)
    - 4 layers: F.Cu/In1.Cu(GND)/In2.Cu(+5V)/B.Cu
    - Board size reduced from 140x120mm to 70x60mm
    - Dedicated GND and VCC power planes on inner layers
    - All signals routed, 2 minor +5V zone connectivity issues
    - Add convert-4layer.py script for 2→4 layer conversion
    - Update pipeline for 4-layer Gerber export (In1.Cu, In2.Cu)
    [64korppu-E-B_Cu.gbl, 64korppu-E-B_Mask.gbs, 64korppu-E-B_Silkscreen.gbo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]
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2026-03-08 Add post-routing DRC analyzer with severity classification
    - pcb-drc-check.py: parses KiCad DRC JSON, classifies violations as
    CRITICAL (shorts, unconnected), WARNING (clearance, dangling tracks),
    INFO (lib issues, starved thermals), ACCEPTED (known DIN-6/mounting)
    - Pipeline now stops on critical DRC failures
    - MAX_UNCONNECTED env var controls allowed unconnected threshold
    - 2-layer board correctly flagged: 33 short circuits found
    [pcb-drc-check.py]
2026-03-08 Fix 4-layer PCB: all nets connected, 0 critical DRC errors
    - Add manual +5V traces: U2.7→U2.8 (F.Cu), R12.1→R11.1 (F.Cu),
    U3.16→R12.1 (B.Cu routed around FLOPPY_DIR via)
    - DRC result: 0 critical, 0 unconnected, 0 shorts
    - Only cosmetic warnings remain (silk_over_copper)
    [64korppu-E-B_Cu.gbl, 64korppu-E-B_Mask.gbs, 64korppu-E-B_Silkscreen.gbo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]
2026-03-08 Fix 4-layer DRC: 0 warnings, 0 unconnected, 0 critical
    Moved mounting hole refs (H1-H4) to F.Fab layer to eliminate
    silk_over_copper warnings. Adjusted J2, R8, C1 reference positions.
    Re-exported gerbers after clean DRC pass.
    [64korppu-E-B_Cu.gbl, 64korppu-E-B_Mask.gbs, 64korppu-E-B_Silkscreen.gbo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]
2026-03-08 Fix 2-layer PCB: re-route from scratch, 0 warnings/0 unconnected
    Stripped 772 bad tracks causing 33 short circuits. Re-routed with
    Freerouting autorouter. Moved H1-H4 refs to F.Fab to fix
    silk_over_copper. Added J1 edge clearance to accepted patterns.
    DRC result: 0 critical, 0 warnings, 0 unconnected.
    [64korppu-E-B_Cu.gbl, 64korppu-E-B_Mask.gbs, 64korppu-E-B_Silkscreen.gbo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]
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2026-03-08 Fix 2-layer PCB: move J1 inside board, re-route, 0/0/0 DRC
    Moved J1 (DIN-6) from x=108 to x=118 so shield pad is 9mm from
    board edge instead of sticking out. Re-routed with Freerouting,
    added 2 manual GND traces for J2 IDC header.
    Updated pcb-pipeline.sh: replaced macOS-incompatible `timeout`
    with bash background process + kill mechanism. Configurable via
    FREEROUTE_TIMEOUT env var (default 60s).
    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
    [64korppu-E-B_Cu.gbl, 64korppu-E-B_Mask.gbs, 64korppu-E-B_Silkscreen.gbo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]
2026-03-08 Add component body collision check to PCB validator
    New validation step checks physical component bodies for overlap,
    not just pads. Uses known component dimensions table (27 footprints).
    Catches cases like barrel jack body overlapping Arduino Nano headers.
    Also adds 2-layer layout visualization to docs.
    [pcb-validate.py]
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2026-03-08 Fix 4-layer PCB: redesign layout to eliminate all body collisions, 0/0/0 DRC
    Repositioned all 27 components to fix 15 body collisions with 1mm clearance.
    Added manual +5V trace on B.Cu for U3.16→R12.1. Freerouting autorouted
    remaining nets. DRC: 0 critical, 0 warnings, 0 unconnected.
    [64korppu-E-B_Cu.gbl, 64korppu-E-B_Mask.gbs, 64korppu-E-B_Silkscreen.gbo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]
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2026-03-08 Fix SRAM body size in 3D render: DIP-8 is 9mm, not 20mm
    [render-3d.py]
2026-03-08 Add hardware README with 3D render, fix render-3d.py, update .gitignore
    - Add README.md to hardware/E-IEC-Nano-SRAM/ with 3D PCB image
    - Fix render-3d.py drawing functions for new bounding box data format
    - Add .DS_Store, *.lck, fp-info-cache, *-drc.rpt, freerouting.jar to .gitignore
    [render-3d.py]
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2026-03-09 Fix 74HC595 bit mapping to match PCB wiring, switch SRAM to 23K256
    Critical bug fix: SR_BIT_* constants in config.h didn't match the
    KiCad PCB pad-to-net wiring. QA (pin 15) connects to /SIDE1 (bit 0),
    not /DENSITY. Reordered all 8 bit defines to match hardware.
    Also switched SRAM from 23LC1024 (128KB) to 23K256 (32KB) — actual
    usage is ~22KB so 32KB is sufficient. 16-bit addresses instead of
    24-bit, same DIP-8 pinout and SPI commands.
    [config.h, sram.c]
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2026-03-09 Switch SRAM from 23LC1024 (128KB) to 23LC256 (32KB), fix 74HC595 QA pin docs
    - Replace 23LC1024 with 23LC256: same DIP-8 pinout, 16-bit addressing
    - SRAM driver: 24-bit → 16-bit address (drop one spi_transfer call)
    - SimAVR harness: update SRAM emulation to 2-byte addressing and 32KB
    - Fix piirikaavio.md: QA was incorrectly marked as unused (is /SIDE1)
    - Fix shiftreg.h bit mapping comment to match actual hardware wiring
    - Update all docs, schematics, PCB files, tools for both 2-layer and 4-layer
    Actual SRAM usage is ~22KB, so 32KB is sufficient with margin.
    [64korppu-E.dsn, 64korppu-E.kicad_pcb, 64korppu-E.kicad_sch]
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2026-03-09 fix(fw): address code review findings in LZ4 compression
    - Fix compress_proto_get_status() to check status_pending flag
    (XZ:1/XZ:0 now correctly return "OK"/"OK COMPRESS ON")
    - Replace unframed raw fallback with transfer abort on compression failure
    - Use COMPRESS_BLOCK_SIZE/COMPRESS_FRAME_BUF_SIZE config defines
    - Remove unused #include <ctype.h> from compress_proto.c
    - Simplify duplicate #ifdef ctype include in cbm_dos.c
    - Add test: xz_get_status_without_query (23 total LZ4 tests)
    [cbm_dos.c]
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2026-03-09 Upgrade SRAM 23LC256→23LC512 (64KB), move LZ4 buffers to external SRAM
    23LC512 is a drop-in replacement (same pinout, same SPI protocol).
    LZ4 compression buffers (raw 512B + frame 556B) now live in external
    SRAM instead of ATmega328P internal RAM, freeing ~1 KB for stack.
    Block size increased from 128B to 512B (matches FAT12 sector size)
    for better compression ratio (~2.0:1 vs ~1.5:1).
    [cbm_dos.c, config.h, main.c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]
2026-03-09 Add test points and fix GND routing on 2-layer PCB (140x120mm)
    - Add 14 diagnostic test points (same signals as 4-layer) on B.Cu
    - Add resize-2layer.py for parametric board resizing
    - Add add-testpoints-2layer.py for test point insertion
    - Fix GND connection between U1 pad 4 and pad 7 via left-side routing
    - DRC clean: 0 critical, 0 warnings, 0 unconnected
    [64korppu-E-B_Cu.gbl, 64korppu-E-B_Mask.gbs, 64korppu-E-B_Silkscreen.gbo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]
2026-03-09 Shrink 2-layer PCB from 140x120mm to 120x100mm
    - Improve compute_layout: fix U2/Nano spacing, move LED/R8 to top area,
    move C1 cap left of SRAM, increase J1 margin from mounting hole
    - Clean reroute with Freerouting passes DRC: 0/0/0
    - Board area reduced 29% (16800mm² → 12000mm²)
    [64korppu-E-B_Cu.gbl, 64korppu-E-B_Mask.gbs, 64korppu-E-B_Silkscreen.gbo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]
2026-03-09 Shrink 2-layer PCB from 120x100mm to 100x80mm
    - Board area reduced 33% (12000mm² → 8000mm²)
    - Manual GND routing on F.Cu to fix starved thermal relief
    - Reduced thermal relief gap to 0.25mm for dense areas
    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
    [64korppu-E-B_Cu.gbl, 64korppu-E-B_Mask.gbs, 64korppu-E-B_Silkscreen.gbo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]
2026-03-09 Shrink 2-layer PCB from 100x80mm to 90x70mm
    - Improve layout algorithm for small boards:
    resistor stacking near DIN-6, cap collision avoidance,
    adaptive test point spacing
    - Board area reduced 21% (8000mm² → 6300mm²)
    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
    [64korppu-E-B_Cu.gbl, 64korppu-E-B_Mask.gbs, 64korppu-E-B_Silkscreen.gbo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]
2026-03-10 Improve resize-2layer.py: clamp texts inside board area, fix C1 placement
    Add clamp_texts_to_board() that flips and clamps Reference/Value texts
    to stay within PCB boundaries. Fix C1 bypass cap placement to use
    gap-width check with proper fallback position derived from R9-R12 stack.
    [64korppu-E-B_Cu.gbl, 64korppu-E-B_Mask.gbs, 64korppu-E-B_Silkscreen.gbo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]
2026-03-10 Add "karski by design 2026 rev 001" board label to both PCBs
    Add copper layer text label on F.Cu for 2-layer and 4-layer PCBs.
    Resize script recreates the label automatically on each resize.
    Fix SetIsBold→SetBold for KiCad 9 Python API.
    [64korppu-E.kicad_pcb]
2026-03-10 Move board label from F.Cu to F.SilkS, regenerate gerbers
    F.Cu text caused clearance violations with traces. F.SilkS is
    non-electrical and doesn't interfere with routing.
    [64korppu-E-B_Cu.gbl, 64korppu-E-B_Mask.gbs, 64korppu-E-B_Silkscreen.gbo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]
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2026-04-11 Fix IEC bus init order, timeout pin release, SA=15 error channel + LED/UART debug
    Move IEC bus initialization before floppy init to eliminate ~2.8s window
    where device doesn't respond to C64. Fix iec_receive_byte_atn() and
    iec_receive_byte() to release DATA/CLK lines on timeout instead of
    leaving the bus locked. Add SA=15 error channel read support so C64 can
    query device status. Add LED debug (green D9, optional red A5) and UART
    debug output for diagnosing "DEVICE NOT PRESENT" errors.
    [cbm_dos.c, iec_protocol.c, iec_protocol.h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]
2026-04-12 Change IEC series resistors R1-R4 from 1kΩ to 100Ω
    1kΩ was too large — formed a voltage divider with C64's pull-ups,
    keeping the IEC bus at ~2.5V instead of LOW. 100Ω provides ESD
    protection while allowing proper LOW signaling (~0.45V).
    Updated schematics (2-layer + 4-layer) and all documentation.
    [64korppu-E.kicad_sch]
2026-04-12 Add UART debug traces, fix motor-off after init, IEC reset reinit
    - Add TRACE() macro (PROGMEM) for flash-stored debug strings (RAM 188%→57%)
    - Add uart_puts_P, uart_puthex8/16, uart_putdec helpers
    - Add verbose UART traces to all modules: [SRAM] [SR] [FLP] [MFM] [FAT] [DOS] [IEC] [DISK]
    - Fix floppy motor never turning off: motor_off after boot init
    - Fix read/write sector not starting motor: add motor_on in read/write
    - IEC bus reset now shuts down floppy, unmounts FAT12, reinits on release
    - Add reset button documentation to kokoonpano.md
    [cbm_dos.c, fat12.c, floppy_ctrl.c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]
2026-04-12 Fix C64 hang on no-disk: release IEC bus, report DRIVE NOT READY
    - Release CLK+DATA and go IDLE when talker has no data (C64 was stuck)
    - Check FAT12 mount state before LOAD/SAVE, return error 74 DRIVE NOT READY
    - Set error channel on mount failure in boot and IEC reset reinit
    - Add fat12_is_mounted() accessor
    [cbm_dos.c, fat12.c, iec_protocol.c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]
2026-04-12 Fix disk detection: check /DSKCHG instead of hardcoded true, add tests
    - Add floppy_check_disk() that reads /DSKCHG signal after recalibrate
    - Change disk_present init from hardcoded true to false
    - Boot and IEC reset now check disk presence before attempting mount
    - Skip mount entirely if no drive or no disk (early exit with error)
    - Fix uart.h for host builds: no-op stubs so tests compile
    - Add 11 new test cases for disk I/O error paths (37/37 pass)
    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
    [floppy_ctrl.c, floppy_ctrl.h, iec_protocol.c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]
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2026-04-12 Enable ICP1 noise canceler (ICNC1) for /RDATA debounce
    4-sample hardware debouncer filters glitches from slow rising edges
    caused by 10kΩ pull-up on /RDATA. Adds fixed 250ns latency (does
    not affect interval measurement accuracy).
    [mfm_codec.c]
2026-04-12 Add MFM pulse code histogram after capture for debugging
    Scans first 500 packs and prints distribution of 2T/3T/4T/invalid
    codes. Helps diagnose: healthy MFM = mix of all three, noise = all
    2T, DD disk = mostly 4T+invalid.
    [mfm_codec.c]
2026-04-12 Add INT0 ATN interrupt for immediate IEC bus response
    - INT0 ISR fires on ATN falling edge, pulls DATA low within ~1µs
    to acknowledge device presence → prevents "DEVICE NOT PRESENT"
    - Add iec_poll(): lightweight check called from blocking waits
    - Motor spin-up (500ms) now services IEC every 1ms via iec_poll()
    - Step settle delays (15ms) also service IEC
    - During MFM capture (~200ms), ATN is acknowledged by ISR but
    full command handling is deferred until capture completes
    [floppy_ctrl.c, iec_protocol.c, iec_protocol.h]
2026-04-12 Replace hardcoded 500ms motor spin-up with event-driven /RDATA detection
    Motor spin-up now polls ICP1 for valid MFM flux transitions instead
    of blindly waiting 500ms. When 8 consecutive valid intervals (40-200
    Timer1 ticks) are detected, motor is at speed. Timeout 1000ms.
    Logs actual spin-up time. IEC serviced during wait. Remove unused
    FLOPPY_MOTOR_SPIN_MS constant.
    [config.h, floppy_ctrl.c]
2026-04-12 Fix reboot loop when C64 is off: edge-triggered /RESET handling
    /RESET LOW now triggers shutdown once, then stays idle (no action).
    Reinit only happens on LOW→HIGH transition (C64 turns on).
    Previously the level-triggered handler re-entered on every
    iec_service() call while /RESET was held LOW.
    [iec_protocol.c]
2026-04-12 Compensate 10kΩ pull-up delay in MFM thresholds, add RPM check
    Root cause found: 10kΩ pull-up on /RDATA adds ~28 ticks delay to
    every measured interval (slow rise to HIGH threshold + ICNC1).
    This shifted all pulse classifications by one category (2T→3T, etc).
    - Add MFM_PULLUP_DELAY (28 ticks) to all classification thresholds
    - Motor spin-up now checks average interval and warns if motor is
    too slow (bad 12V supply) or signal is noise
    - Track 16 consecutive valid intervals for reliable speed detection
    After R12 is changed to 1kΩ, set MFM_PULLUP_DELAY to 0.
    [config.h, floppy_ctrl.c]
2026-04-12 Fix MFM decoder: extract data bits instead of clock bits
    The decoder extracted bit at position bit_count (the transition/clock
    bit) instead of bit_count+1 (the data bit). For gap bytes (0x00),
    this produced 0xFF, making sync mark detection (0xA1) impossible.
    This was the root cause of "sector not found" on valid MFM data.
    Fix: shift_reg >> (bit_count + 1) in all three decode functions
    (mfm_decode_sector, mfm_find_sectors, mfm_wait_for_sector).
    [mfm_codec.c]
2026-04-12 Rewrite MFM decoder: raw 0x4489 sync pattern matching
    Root cause: the old decoder assembled bytes from raw MFM bits with
    arbitrary alignment, then checked byte values for 0xA1 sync.
    This never worked because the byte boundaries were wrong.
    New approach (same as real MFM controllers like WD1770):
    - Accumulate raw MFM bits in 32-bit shift register
    - Scan for raw bit pattern 0x4489 (sync A1 with missing clock)
    - When 3x sync found, byte alignment is automatically correct
    - Extract data bytes using aligned clock/data bit pairs
    Also: remove iec_poll() from motor spin-up to prevent IEC/ICP
    interference that caused 0-pack capture timeouts.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
    [floppy_ctrl.c, mfm_codec.c]
2026-04-12 Fix MFM data bit extraction offset after sync detection
    After 0x4489 sync alignment, data bits are at even positions
    (0,2,4...) in the shift register — extract at raw_avail, not
    raw_avail+1. The +1 offset was reading clock bits instead of data.
    Also fix pointer dereference errors from previous replace_all.
    [mfm_codec.c]
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2026-04-12 Pin RCLK LOW immediately at boot to prevent 74HC595 latch glitch
    At power-on, 74HC595 outputs are random and RCLK (D6) is floating.
    SPI traffic during sram_init() could accidentally latch garbage,
    potentially asserting /WGATE and corrupting disk data. Now RCLK is
    forced OUTPUT LOW as the very first instruction in main(), before
    any SPI or peripheral init.
    [main.c]
2026-04-12 Add 74HC595 boot safety: RCLK pull-down + /OE on A3
    Hardware:
    - 10kΩ pull-down on RCLK (D6) prevents accidental latch during boot
    - /OE pulled HIGH (10kΩ to 5V) keeps outputs tri-state until firmware
    drives A3 LOW → floppy signals safe during power-on/reset
    - Skip /SRCLR to reset (would assert all active-low signals)
    Firmware:
    - RCLK pinned LOW as first instruction in main()
    - shiftreg_init() writes 0xFF THEN enables /OE via A3
    - Outputs never have undefined state
    Updated: piirikaavio.md (diagram, pinout, BOM), config.h, shiftreg.c
    [config.h, shiftreg.c]
2026-04-12 Set MFM_PULLUP_DELAY=0 for 1.5kΩ effective pull-up (1.8k||10k)
    With 1.8kΩ in parallel with 10kΩ, rise time is ~0.2µs (~3 ticks).
    The old 28-tick compensation over-shifted thresholds, causing 3T to
    be classified as 2T — sync A1 pattern 0x4489 never formed correctly.
    [config.h]
2026-04-12 Rewrite MFM decoder as single-loop state machine
    Previous decoder called mfm_extract_byte() from inside the pulse
    loop, causing SRAM position to skip unprocessed codes → wrong mark
    bytes (0x00/0x4A instead of 0xFE).
    New: single loop, state machine (SCAN_SYNC→READ_MARK→READ_ID→
    READ_DATA). All pulses flow through one path, no SRAM mismatch.
    [mfm_codec.c]
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2026-04-12 Increase PULLUP_DELAY to 32 for better 2T classification margin
    With 28, borderline 2T at A1 sync boundaries misclassified as 3T
    → bit alignment shift → 2nd/3rd A1 didn't match 0x4489.
    Thresholds now 112/144/192.
    [config.h]
2026-04-12 Accept both 0x4489 and 0x44A9 as MFM sync patterns
    Drive outputs normal A1 (0x44A9) instead of missing-clock sync
    (0x4489). Accept both for compatibility.
    [mfm_codec.c]
2026-04-12 Revert to 0x4489-only sync, add preamble-triggered sync area dump
    0x44A9 caused thousands of false sync matches in regular data.
    New diagnostic: detect 0x00 preamble (raw_bits == 0x5555 for 4+
    consecutive pulses), then dump the next 30 raw_bits values. This
    shows exactly what pattern the sync marks produce. First 3 preambles.
    [mfm_codec.c]
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2026-04-12 Adaptive MFM thresholds: compensate variable delay from recovery time
    Root cause fix: after short intervals (2T/3T), signal recovery is
    incomplete → next interval appears ~24 ticks longer → 2T classified
    as 3T. Now ISR tracks prev_code and raises thresholds by 24 after
    short recovery. After 4T+ (full recovery), standard thresholds.
    [mfm_codec.c]
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2026-04-13 Fix brute-force calibration for 74LS14 Schmitt-trigger setup
    Extend delay search range from 50-120 to 0-150 to cover
    74LS14's lower delay (~10-40 ticks vs ~109 for raw CMOS input).
    Add diversity check (require ≥2 interval types) to prevent
    false positives where all intervals collapse to one type.
    Add consecutive byte bonuses to scoring (4E+4E, A1+A1, A1+FE).
    Finer histogram (16-tick bins + min/max) and 2048 raw tick hexdump
    for signal diagnostics.
    [config.h, mfm_codec.c]
2026-04-13 Fix calibration: count-based diversity check + measured delay=30
    Previous boolean diversity check was defeated by rare outlier
    intervals (e.g. 161 ticks) that just barely crossed the cell
    boundary. Now requires each interval type to have ≥5% of samples.
    Remove 0x00 from scoring — all-2T decoding produces all-zero
    bytes which inflated scores at wrong delay values. Add 0x00→0xA1
    transition bonus for real preamble-to-sync sequences.
    Set MFM_PULLUP_DELAY=30 from measured trace data with 74LS14:
    2T≈107, 3T≈133, 4T≈155 ticks.
    [config.h, mfm_codec.c]
2026-04-13 Replace brute-force calibration with analytical delay computation
    Brute-force scoring was defeated by coincidental byte matches:
    wrong delay (e.g. 15) misclassified 2T→3T and 3T→4T, but the
    shifted MFM bitstream accidentally produced 0xA1 bytes that
    scored higher than correctly decoded 0x4E gap fill.
    New approach: compute delay analytically from histogram peaks.
    Find the two largest 16-tick bins (2T and 3T clusters), compute
    delay = (center_lo - 64 + center_hi - 96) / 2. Then determine
    offset by scoring only 0x4E bytes with both candidates.
    Also reduce trace output (raw 2048→64, decoded 2048→256) to
    fit in PuTTY's scroll buffer.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
    [mfm_codec.c]
2026-04-13 Use raw 0x4489 sync pattern for MFM sector detection
    The previous approach extracted decoded bytes at a calibrated
    offset and searched for 0xFE IDAM. This failed because:
    1. The offset depends on capture start position (random)
    2. Any misclassified interval causes permanent framing error
    3. Gap fill scoring couldn't determine offset when capture
    started in data region (most of the track)
    New approach matches how real floppy controllers work:
    search for raw MFM sync pattern 0x4489 (0xA1 with missing
    clock) directly in the accumulated bitstream. This is
    self-aligning — once 3 consecutive syncs are found, the bit
    framing is known (offset=0 after sync).
    Also replace decoded hex dump with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
    [mfm_codec.c]
2026-04-13 Lower delay estimate to correctly classify 4T sync intervals
    Variable delay: after longer intervals, signal recovers more
    giving shorter delay. 4T intervals (~148-155 ticks) were being
    classified as 3T at delay=40 (boundary at 152), so the raw
    0x4489 sync pattern was never found in the bitstream.
    Now uses min(delay_2T, delay_3T) - 8 = 32, placing the 3T/4T
    boundary at 144 ticks. This correctly classifies 4T intervals
    while keeping 2T/3T classification accurate.
    [mfm_codec.c]
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2026-04-13 Add 2T run length diagnostics to detect pulse merging
    If the 74LS14 rise time is too slow for 2T intervals (4µs),
    consecutive 2T pulses merge into 4T, destroying the preamble
    (12×0x00 = 96 consecutive 2T). This diagnostic reveals it:
    - max 2T run: should be ~96 (preamble), if <16 → pulse merging
    - run length histogram: 1-2, 3-4, 5-8, 9-16, 17-32, 33+
    - dumps first 4 long 2T runs with following raw intervals
    [mfm_codec.c]
2026-04-13 Replace delay formula with explicit threshold classification
    The formula (interval-delay+16)/32 cannot handle variable delay:
    - Preamble 2T (after 2T): delay ~48 → interval ~112
    - Gap fill 2T (after 3T): delay ~42 → interval ~106
    - Sync 4T (after 3T): delay ~30 → interval ~158
    At delay=32, the 2T/3T boundary was at 112, misclassifying
    preamble 2T intervals as 3T. This destroyed preamble detection
    (max 2T run = 2 instead of expected 96).
    New approach: explicit thresholds from histogram cluster peaks.
    thr_23 = midpoint(2T_peak, 3T_peak) = ~120
    thr_34 = 3T_peak + half_spacing - 8 = ~144
    This correctly classifies all three regions:
    2T (93-119) < 120, 3T (120-143) < 144, 4T (144-17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
    [mfm_codec.c]
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
